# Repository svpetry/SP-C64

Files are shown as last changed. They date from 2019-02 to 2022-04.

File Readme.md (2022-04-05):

This was my first attempt to recreate the Commodore 64. I was able to get it more or less working, but the design still contains timing issues. Currently I am working on a C64 ATX board.

Please note that this design is still buggy. If you are interested in my work then you should wait until I release my C64 ATX project.

## Original text:

This is a rebuild of the Commodore 64 using the original schematics.

Features/changes:
* Replaced DRAM with 2 x 32K SRAM
* Modulator with S-Video and Composite output
* PLA replaced with EEPROM
* PS/2 keyboard connector
* VIC and SID voltage selectable by jumper
* replaced all C64 ROM chips with one EEPROM
* 4 kernal images selectable by switches
* clock generation by ICS 525 clock chip

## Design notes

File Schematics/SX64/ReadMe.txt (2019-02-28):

Commodore SX 64 Portable Computer Schematics
--------------------------------------------

This archive contains a scanned version of the complete Commodore SX 64
Portable Computer Schematics. The book is marked as CBM Part No. 314001-05.

The PDF is in Letter format with all the double sized diagram pages in Ledger
format, just as the original. The width on the Front and Back covers is
slightly oversized, also just as the original.
The original was in near perfect condition, but due to the poor quality
of the original print, some of the scanned pages look somewhat poor. Blame
CBM, not me ;-)

I hope this document can be of some use to you.

2007-04-10, Devia/Ancients

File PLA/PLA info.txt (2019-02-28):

Eprom PIN		C64 signal

1		A15	/GAME
2		A12	A13
3		A7	A14
4		A6	A15
5		A5	/VA14
6		A4	/CHAREN
7		A3	/HIRAM
8		A2	/LORAM
9		A1	/CAS
10		A0	MA4 (A4/A12 VIC)
11		O0	/ROML
12		O1	I/O
13		O2	GR/W
14		GND	GND
15		O3	/CHAROM
16		O4	/KERNAL
17		O5	/BASIC
18		O6	/CASRAM
19		O7	/ROMH
20		/CE	GND
21		A10	MA5 (A5/A13 VIC)
22		/OE	GND
23		A11	/EXROM
24		A9	R/W
25		A8	/AEC
26		A13	BA
27		A14	A12
28		VCC	VCC

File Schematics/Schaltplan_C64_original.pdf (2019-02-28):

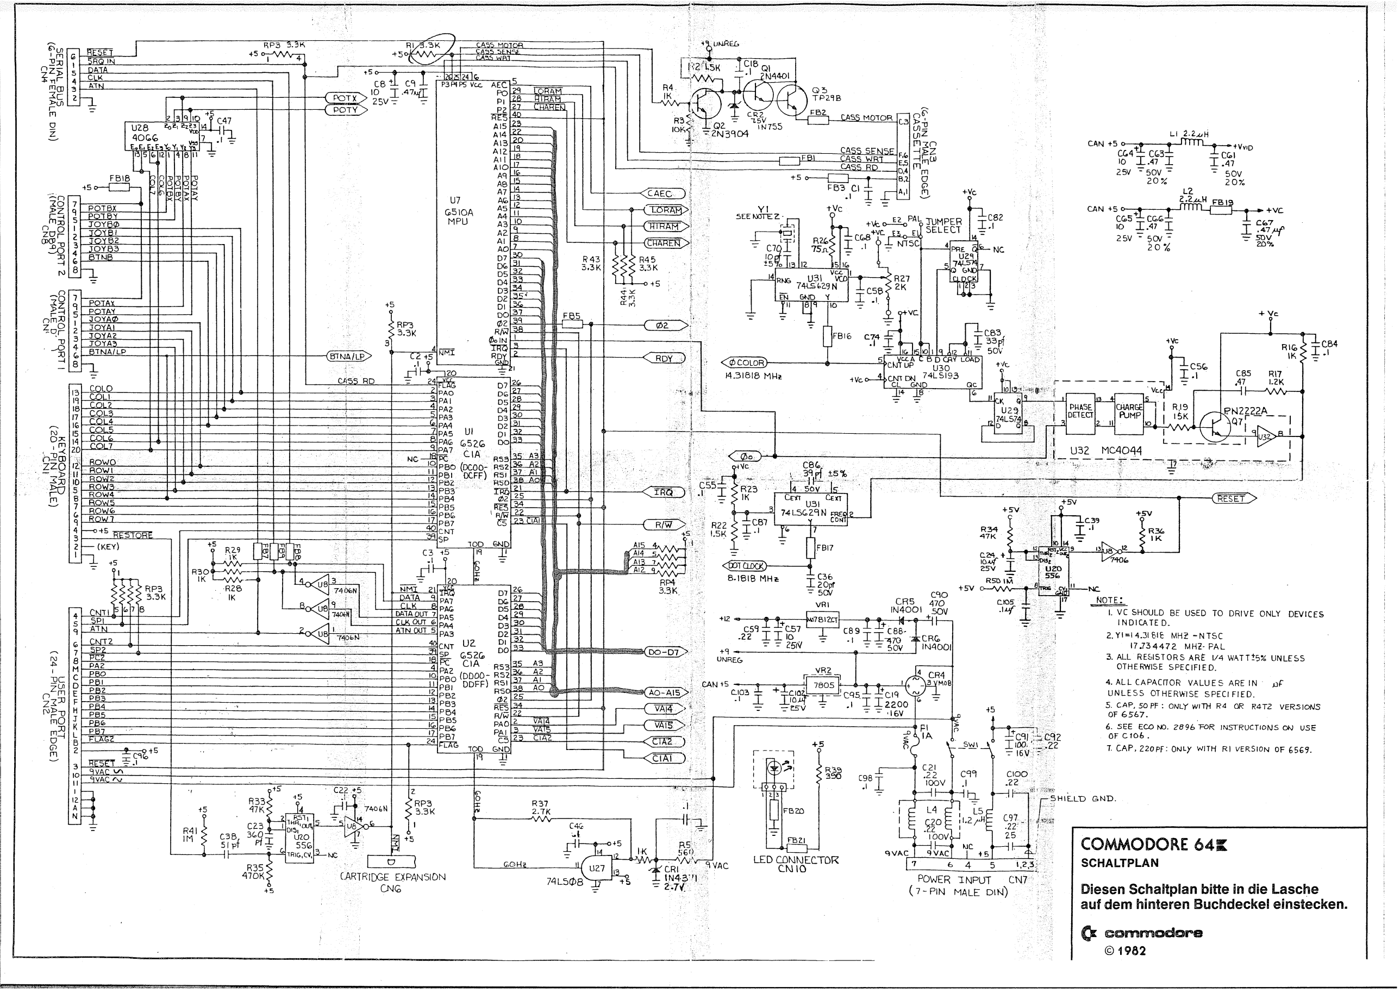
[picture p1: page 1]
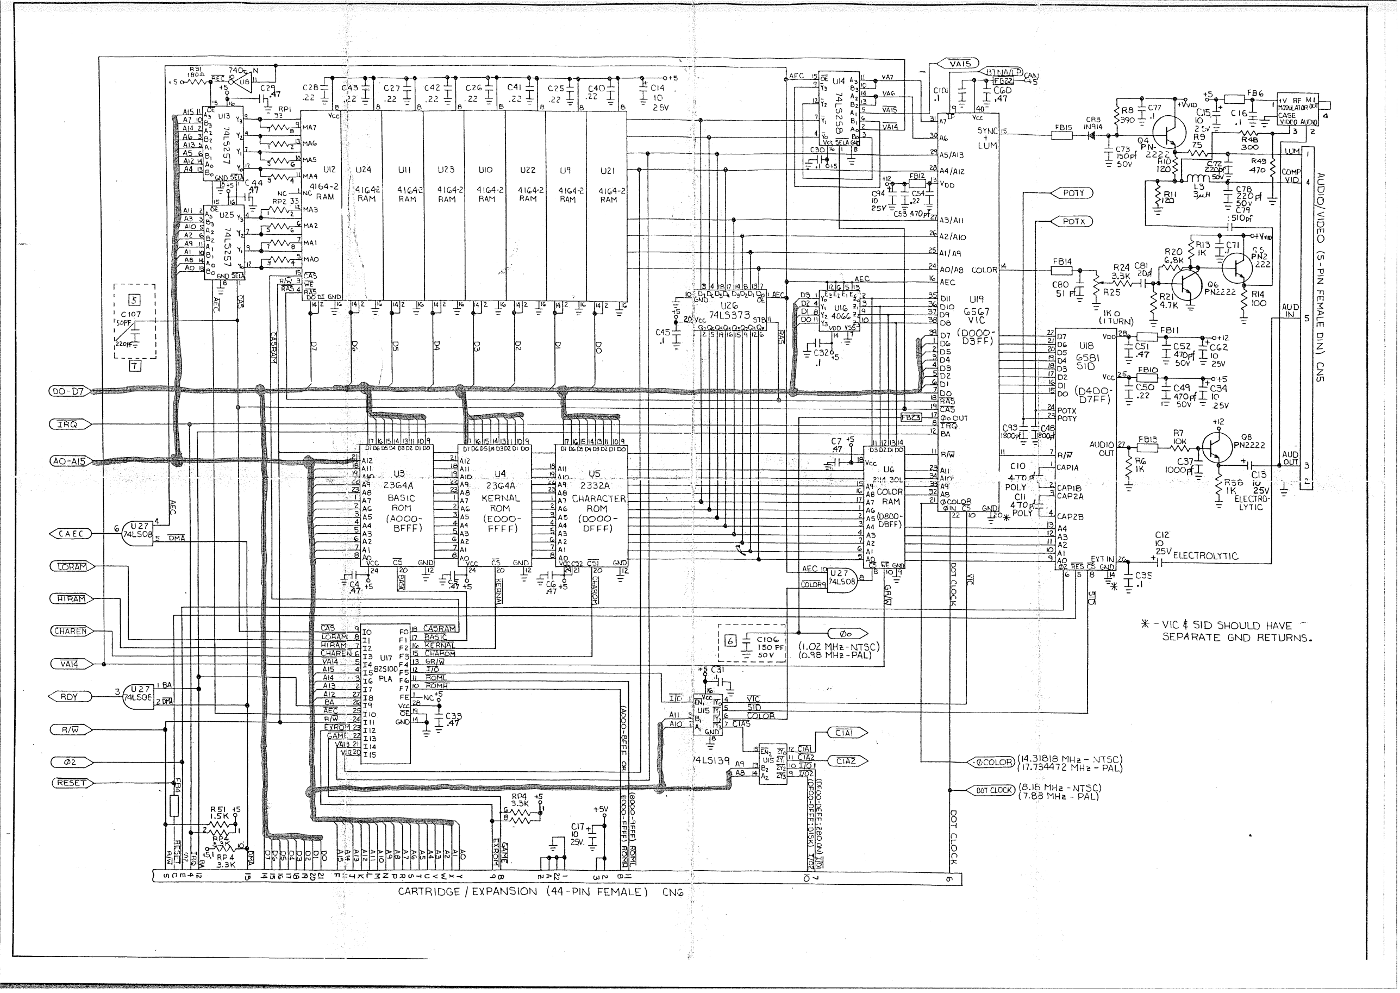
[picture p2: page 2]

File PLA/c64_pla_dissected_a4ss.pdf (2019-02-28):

The C64 PLA Dissected

Thomas ’skoe’ Giesel

Revision 1.1, December 24, 2012

# Contents

Contents | 2
1 Introduction | 3
2 The Logic in the PLA | 6
3 Hardware | 16
4 The Inner Workings of a CSG PLA | 25
5 A PLA Replacement: realPLA | 52
6 Conclusion | 55
A C64 Memory Configurations Explained | 57
Bibliography | 65

2

# Chapter 1

# Introduction

### 1.1 Overview

The programmable logic array (PLA) in the Commodore 64 (C64) is used to create chip select signals from various other signals, e.g., from the current address. These signals control which chip is to be connected to the data bus. Therefore the PLA is responsible to implement the memory map of the C64.

If the PLA is broken, the CPU and the VIC-II¹ direct memory access (DMA) can not access the right memory and I/O devices anymore. In this case some chips can not be selected or more than one chip is active at the same time. A total or partial malfunction of the computer is the result. If a PLA is replaced with a part which does not meet certain timing or electrical constraints of the chips connected to it, the computer becomes unstable, possibly depending on temperature or hardware extensions used or may refuse to work at all.

The logic implemented in the PLA defines the memory map. The logic equations are described in chapter 2, among a short overview of previous reverse engineering work related to it. Also the meaning of all signals connected to the PLA for the working of the C64 is explained there. Appendix A contains the actual memory maps in a readable form as a reference.

A list of PLAs found in C64s and measurements on some of them are shown in chapter 3. This chapter also describes which parameters are important when a PLA is replaced with a different part. Most C64s shipped with a PLA made by Commodore Semiconductor Group (CSG), better known under their original name MOS Technology (MOS). A PLA of this type was opened, photographed through a microscope and completely reverse engineered for this article, down to the transistor level. Chapter 4 contains information about the inner workings of the PLA, a redrawn chip layout and schematics. That chapter also contains some background information by former Commodore/MOS engineers.

An actual implementation of a PLA replacement called realPLA is introduced in chapter 5 which can be built with parts being in production at the time of writing. This implementation aims at highest compatibility possible while using low-cost parts only. The design files for the realPLA are available under a Creative Commons license.

Finally, chapter 6 gives a conclusion about the findings in this document. It also evaluates the compatibility of different PLA replacements.

1Video Interface Controller II

3

### 1.2 About this Document

Why is it necessary to write a document about the PLA in 2012? Information already documented is spread over many articles, buried in old dusty books, various forums and mailing lists, sometimes mixed with wrong statements. Even though the PLA contains combinatorial logic only, it plays an essential role in the C64 and other Commodore computers. “The PLA’s [...] were our last salvation to pull a problem out of the fire, and our chance to impart any coolness in logic,” recalls Bil Herd, a former Commodore engineer.

Understanding the logical function of the PLA is important for programmers, for hardware designers and for emulator developers. However, it is also important to have a closer look at the electrical properties of the original PLAs to implement a drop-in replacement for PLA chips. This document addresses both topics.

This document collects information already documented and adds new measurement and research results. The text and all figures are licenced under Creative Commons Attribution-ShareAlike 3.0 Unported (CC BY-SA 3.0).

### 1.3 Acknowledgements

I wish to thank the engineers of Commodore for the interesting memory maps achieved by using the PLA. Unfortunately you forgot a KERNAL cartridge ;)

Furthermore I would like to express respect to all persons who examined the PLA before and published their results, namely William Levak, Jens Sch¨onfeld, Marko M¨akel¨a, Andreas Boose and Mark Smith.

All PLA logic incorporated in this document and used for the implementation is based on the JEDEC file by Raymond Jett of arcadecomponents.com. It was created by reading a C64 PLA with a TopMAX programmer and Max Loader software. The file is available at [AC12] and in the source code repository of the realPLA implementation [realPLA12].

Segher Boessenkool described in a mail to the cbm-hackers mailing list [Boess12] how the JEDEC file can be read directly. Thanks to his explanation I was able to implemented a small tool which converted the JEDEC file to VHDL equations directly. Segher also helped me much with the first steps to learn to read NMOS die shots and also reviewed this document.

The micrographs for this document were made by Dr. Martin ‘enthusi’ Wendt (8700R1) and Philipp ‘Dexter’ Maier (7700R2). AREA51HD donated the chips we used for that.

Gerrit Heitsch, TheRyk and Bj¨orn ‘JMP$FCE2’ Wieck sent some different PLAs for the investigations. Gerrit also gave some valuable hints for various topics and Bj¨orn made some additional measurements. Ingo Korb helped with proofreading.

Last but not least I also want to thank the former Commodore engineers Bil Herd, Bret Raymis, Dan Morris, Dave DiOrio, Dave Esposito and James Redfield for interesting background information and for clarifying some technical issues.

All quotes in this document which do not state a reference are taken from personal com-munications with the persons concerned.

4

Revision | Changes
1.0 | Initial release
1.1 | Minor changes after review comments; link to Jens Sch¨onfeld’s PLA tool
| added; SuperPLA V3 mentioned

Table 1.1: Document Revisions

### 1.4 Document Revisions

Please look out for new revisions of this document. If you have new or additional information relevant for this document or found mistakes, please contact me. The latest version of this document is available at http://skoe.de/docs/c64-dissected/pla/. Feel free to mirror these files.

5

# Chapter 2

# The Logic in the PLA

### 2.1 The Development

The logic needed to get the C64 running was programmed by Bob Yannes. “He just needed some glue logic to tie everything together,” recalls James Redfield. According to Bil Herd, “[The original PLA terms] appear on an 82S100 worksheet photocopied out of the Signetics databook.”

### 2.2 Reverse Engineering History

The memory maps in the Programmer’s Reference Guide [PRG83] show all possible configurations as they are seen by the CPU, including Ultimax mode. However, some details cannot be taken from that book, especially memory configurations for VIC-II accesses.

Probably the earliest full reverse engineering of the logic programmed to the PLA was written by William Levak in 1986. It was published in The Transactor magazine [Lev86]. He read out a PLA, put the binary dump onto a disk and used a computer program to extract the logic table from it. Using this way he avoided transcription errors. He double-checked the results against two other PLAs. Unfortunately the article in The Transactor has some typesetting mistakes in the memory maps, although the logic table is correct and nicely optimized.

Some years later, in 1994, Jens Sch¨onfeld - apparently not aware of William’s work -captured the truth table again. He, Marko M¨akel¨a, Andreas Boose and others [PLA95] investigated that table and derived equations from it. Mark Smith took a programmer and read out an 82S100 in 1995. The results confirmed their work.

### 2.3 PLA Logic Revisions

Very early C64s contain a PLA which was labeled REV2 7E17. This version is said to have a different logic implemented. Unfortunately no binary or JEDEC dump was available for this document. The next version was REV3 8411. The four digit hex number is the checksum of the original JEDEC file most likely.

Different PLAs with different part numbers by different manufacturers found in C64s have been read out. The logic in all of them was identical with REV3, so this was the final revision.

6

### 2.4 How the PLA is Connected in the C64

To understand the logic in the PLA, first let’s have a look how it is connected in the C64. All descriptions are based on the schematic #251138 from [Serv85], but apply for other C64 models too.

#CAS (I0)

The input line I0 is connected to the #CAS output of the VIC-II. In every Phi1 and Phi2 cycle this line is pulled down by the VIC-II to initiate a read or write access to DRAM. Depending on the other inputs, the PLA may propagate the #CAS pulse to the #CASRAM output or mask it out. Only if it is propagated to #CASRAM, DRAM is actually addressed by the memory access. When #CASRAM remains high in a cycle because it is disabled by the PLA logic, the DRAM access is rendered ineffective, or more precisely it turns to a RAS-only refresh cycle.

#LORAM, #HIRAM, #CHAREN (I1 to I3)

The lines #LORAM (I1), #HIRAM (I2) and #CHAREN (I3) are connected to the pro-cessor port of the CPU, better known as bits 0..2 of $00/$01 in the 6510/8500. After a reset these lines are all set to input mode by the CPU, which means that they are not driven. To make sure the have a sane value when the machine is started, they are pulled up by R43, R44 and R45. With all these values being 1, the C64 can start with KERNAL, I/O and BASIC banked in.

#VA14 (I4)

#VA14 (I4) is one of the additional video address lines for the VIC-II. The VIC-II has a 14 bit wide address bus to address 16 KiByte of memory, while the C64 has 64 KiByte of DRAM. To allow the VIC-II to address any of the four 16 KiByte chunks available in these 64 KiByte, two additional address lines called #VA14 and #VA15 are generated by programmable outputs of the CIA U2. They are fed to an extra address multiplexer U14. This is a 74LS258, which has inverted outputs.

The I/O ports are in input mode after the CIA has been reset. In this case these two lines are pulled high by internal pull-up devices in the CIA, which effectively selects bank 0 on startup. Note that these two video address bits do not appear on the global C64 address bus, they are only used for DRAM accesses. #VA14 is also connected to the PLA to influence the character set ROM mapping.

A15 to A12 (I5 to I8)

The address bus lines A15 to A12 (I5 to I8) are connected to the global address bus. They are driven by the CPU when AEC from the VIC-II and #DMA from the Expansion Port are both high. During VIC-II cycles, when AEC is low, they are pulled up by RP4. When they are pulled up by this resistor array only, it is possible to change them from the Expansion Port. These address lines are used by the PLA to control the memory mapping when AEC is high, i.e. during CPU cycles. However, they are also evaluated in the PLA in Ultimax mode when AEC is low, which makes an interesting trick possible, shown in section A.

7

BA (I9)

BA (I9) is set low by the VIC-II when it wants to halt the CPU to be able to use both half-cycles to get more memory bandwidth. When the VIC-II pulls down BA to take over the bus, there are three cycles left for the CPU. In these cycles up to three write accesses can take place, which is the maximum number of consecutive write accesses a 6510 does. However, the CPU stops its work before the first read access is started. Therefore there are up to three dummy read accesses on the bus until the VIC-II takes over control.

#AEC (I10)

#AEC (I10) is an inverted version of AEC. #AEC is high whenever the VIC-II is going to control the address bus. This is the case in every Phi1 cycle and in all full cycles when is BA low, after the CPU got three extra Phi2 cycles.

R/#W (I11)

The signal R/#W (I11) is high for read accesses and low for write accesses. Note that it is pulled up with resistor R51, because this line is not driven by the CPU when AEC or #DMA are low.

#EXROM, #GAME (I12, I13)

The two lines #EXROM and #GAME can be pulled down by cartridges to change the memory map of the C64, e.g., to map external ROM into the address space. When they are not pulled down from the cartridge port, resistors in RP4 pull them up.

VA13, VA12 (I14, I15)

The two address lines VA13 and VA12 are directly connected to the VIC-II. These lines are needed to address the 16k address space of the VIC-II. Note that #VA14 is from a completely different source, it is connected to a CIA output.

#CASRAM (F0)

The #CASRAM output is connected to the #CAS input of the DRAM chips. It is a gated version of the #CAS signal from the VIC-II. The VIC-II activates the #CAS signal in every half-cycle. Whenever a memory access has to address a different chip or port than the internal DRAM, the PLA disables the #CASRAM output, i.e. it remains high. This is also the case in the Ultimax memory configuration, where some address ranges simply have no memory selected at all.

The #CASRAM line requires the PLA to fullfill certain timing requirements, details can be found in section 3.3.

#BASIC, #KERNAL, #CHARROM (F1..F3)

The outputs #BASIC, #KERNAL, #CHARROM are connected to the chip select inputs of BASIC, KERNAL and character set ROMs. To address one of these chips, the appropriate line is pulled down.

### 2.5 How to Extract the Logic from a 82S100

The 82S100 PLA used in some early C64s can be read out to a JEDEC file with a programmer. This file contains a direct image of the fuse map programmed in the PLA.

8

This fuse map can be translated to product terms, which are AND combinations of inputs and inverted inputs. These product terms may be used in any of the eight sum terms, which are OR combinations. Finally, the fuse map describes which output shall be inverted. The meaning of the bits in the JEDEC file has been explained, e.g., in a mail by Segher Boessenkool [Boess12].

For this document a Python tool has been implemented, which converts the JEDEC file to a more readable logic table and to VHDL source code. The result is also used in the PLA replacement described in section 5.

### 2.6 Full Logic Table

The following table shows the AND and OR relations in the PLA in a very compact form. The symbol ‘*’ means AND, ‘/’ means AND NOT and ‘+’ means OR. Human readable equations are listed in subsequent sections, the resulting memory maps can be found in appendix A.

p 00000000001111111111222222222233 01234567890123456789012345678901 Inputs
#CAS | ........* | /*/

#LORAM | *...*......**..**..* |

#HIRAM | ****.*...**..**....*.* |

#CHAREN ...///...******** |

#VA14 | ......** |

A15 | ******..***************.///**..*
A14 | /*****..***********///*.//*/*..*
A13 | ***///../////////////**..*.*/../
A12 | ...***..***********.....*.../..*
BA | .........*.*.*.*.* |
#AEC | //////**///////////////*......./

R/#W | ******../*/*/*/*/*/*.*........./
#EXROM | ../.././.....////**/*/*******...

#GAME | **/**/*/.****//////./////////...

VA13 | ......// | *........
VA12 | ......** | *........
Outputs
++++++++.++++++++++++++++++++.+. | #CASRAM
+ | NOT #BASIC
.++ | NOT #KERNAL
...+++++ | NOT #CHARROM
| + NOT #GRW
.........++++++++++ | NOT #IO
| ++ | NOT #ROML
| +++........ NOT #ROMH

### 2.7 Original PLA Equations

This chapter shows all equations as extracted directly from a 82S100 and explains their meaning.

9

Note that the value of VADDR refers to a VIC-II address as mapped to the 64k memory space: Address bits 15 and 14 are the inverted values of #VA15 and #VA14, generated by the CIA U2, the remaining bits are generated by the VIC-II itself.

Product Terms

These product terms are AND combinations of the input signals and inverted input signals. They can be used in sum terms to determine the final output signals.

Product Term for #BASIC

If p0 is true, BASIC ROM is selected.

-- # LORAM = 1 , # HIRAM = 1 ,
-- address $A000 .. $BFFF ,
-- no VIC access , read , cartridge : none or 8k p0 <= n_loram and n_hiram and
a15 and not a14 and a13 and
not n_aec and rd and n_game ;

Product Terms for #KERNAL

If p1 or p2 are true, KERNAL ROM is selected.

-- # HIRAM = 1 ,
-- address $E000 .. $FFFF
-- no VIC access , read , cartridge : none or 8k p1 <= n_hiram and
a15 and a14 and a13 and
not n_aec and rd and n_game ;

-- # HIRAM = 1 ,
-- address $E000 .. $FFFF
-- no VIC access , read , cartridge : 16k
p2 <= n_hiram and
a15 and a14 and a13 and not n_aec and rd and not n_exrom and not n_game ;

Product Terms for #CHARROM

If one or more of p3 to p7 are true, CHARACTER SET ROM is selected.

-- # HIRAM = 1 , # CHAREN = 0 ,
-- address $D000 .. $DFFF
-- no VIC access , read , cartridge : none or 8k p3 <= n_hiram and not n_charen and
a15 and a14 and not a13 and a12 and not n_aec and rd and n_game ;

-- # LORAM = 1 , # CHAREN = 0 ,
-- address $D000 .. $DFFF ,
-- no VIC access , read , cartridge : none or 8k p4 <= n_loram and not n_charen and
a15 and a14 and not a13 and a12 and not n_aec and rd and n_game ;

-- # HIRAM = 1 , # CHAREN = 0 ,

10

-- address $D000 .. $DFFF ,
-- no VIC access , read , cartridge : 16k
p5 <= n_hiram and not n_charen and
a15 and a14 and not a13 and a12 and
not n_aec and rd and not n_exrom and not n_game ;

-- VADDR $1000 .. $1FFF or $9000 .. $9FFF
-- VIC -II access , cartridge : none or 8k
p6 <= n_va14 and not va13 and va12 and n_aec and n_game ;

-- VADDR $1000 .. $1FFF or $9000 .. $9FFF
-- VIC -II access , cartridge : 16k
p7 <= n_va14 and not va13 and va12 and n_aec and not n_exrom and not n_game ;

Unused Product Term p8

The term p8 is not used at all. It may be a remainder of an earlier design stage of the C64 prototypes. Note that this is the same as p31 with CAS inverted.

p8 <= n_cas and
a15 and a14 and not a13 and a12 and not n_aec and not rd ;

Product Terms for #IO

If one or more of p9 to p18 are true, an I/O chip or port is selected.

-- # HIRAM = 1 , # CHAREN = 1 ,
-- address $D000 .. $DFFF ,
-- no VIC access bus available , read ,
-- cartridge : none or 8k
p9 <= n_hiram and n_charen and
a15 and a14 and not a13 and a12 and not n_aec and ba and rd and n_game ;

-- # HIRAM = 1 , # CHAREN = 1 ,
-- address $D000 .. $DFFF ,
-- no VIC access , write , cartridge : none or 8k p10 <= n_hiram and n_charen and
a15 and a14 and not a13 and a12 and not n_aec and not rd and n_game ;

-- # LORAM = 1 , # CHAREN = 1 ,
-- address $D000 .. $DFFF ,
-- no VIC access , bus available , read ,
-- cartridge : none or 8k
p11 <= n_loram and n_charen and
a15 and a14 and not a13 and a12 and not n_aec and ba and rd and n_game ;

-- # LORAM = 1 , # CHAREN = 1 ,
-- address $D000 .. $DFFF ,
-- no VIC access , write , cartridge : none or 8k p12 <= n_loram and n_charen and
a15 and a14 and not a13 and a12 and

11 not n_aec and not rd and n_game ;

-- # HIRAM = 1 , # CHAREN = 1 ,
-- address $D000 .. $DFFF ,
-- no VIC access , bus available , read , cartridge : 16k p13 <= n_hiram and n_charen and
a15 and a14 and not a13 and a12 and
not n_aec and ba and rd and
not n_exrom and not n_game ;

-- # HIRAM = 1 , # CHAREN = 1 ,
-- address $D000 .. $DFFF ,
-- no VIC access , write , cartridge : 16k p14 <= n_hiram and n_charen and
a15 and a14 and not a13 and a12 and not n_aec and not rd and
not n_exrom and not n_game ;

-- # LORAM = 1 , # CHAREN = 1 ,
-- address $D000 .. $DFFF ,
-- no VIC access , bus available , read , cartridge : 16k p15 <= n_loram and n_charen and
a15 and a14 and not a13 and a12 and
not n_aec and ba and rd and
not n_exrom and not n_game ;

-- # LORAM = 1 , # CHAREN = 1 ,
-- address $D000 .. $DFFF ,
-- no VIC access , write , cartridge : 16k p16 <= n_loram and n_charen and
a15 and a14 and not a13 and a12 and not n_aec and not rd and
not n_exrom and not n_game ;

-- address $D000 .. $DFFF
-- no VIC access , bus available , read , cartridge : Ultimax p17 <= a15 and a14 and not a13 and a12 and
not n_aec and ba and rd and
n_exrom and not n_game ;

-- address $D000 .. $DFFF ,
-- no VIC access , write , cartridge : Ultimax
p18 <= a15 and a14 and not a13 and a12 and
not n_aec and not rd and n_exrom and not n_game ;

Product Terms for #ROML

If p19 or p20 are true, the cartridge line ROML is selected.

-- # LORAM = 1 , # HIRAM = 1 ,
-- address $8000 .. $9FFF
-- no VIC access , read , cartridge : 8k or 16k p19 <= n_loram and n_hiram and
a15 and not a14 and not a13 and
not n_aec and rd and not n_exrom ;

-- address $8000 .. $9FFF

12

-- no VIC access cartridge : Ultimax
p20 <= a15 and not a14 and not a13 and
not n_aec and n_exrom and not n_game ;

Product Terms for #ROMH

If one or more of p21 to p23 are true, the cartridge line ROMH is selected.

-- # HIRAM = 1 ,
-- address $A000 .. $BFFF ,
-- no VIC access , read , cartridge : 16k
p21 <= n_hiram and
a15 and not a14 and a13 and
not n_aec and rd and not n_exrom and not n_game ;

-- address $E000 .. $FFFF ,
-- no VIC access cartridge : Ultimax
p22 <= a15 and a14 and a13 and
not n_aec and n_exrom and not n_game ;

-- VADDR $3000 .. $3FFF , $7000 .. $7FFF , $B000 .. $BFFF or
-- | $E000 .. $EFFF ,
-- VIC -II access , cartridge : Ultimax
p23 <= va13 and va12 and
| n_aec and n_exrom and not n_game ;

Additional Product Terms for #CASRAM

The DRAM of the C64 must be disabled whenever another device is selected. Therefore all product terms above appear in the #CASRAM term. Exceptions are the unused terms and #GRW, which is not a chip select signal. However, in Ultimax mode most of the DRAM is hidden permanently to emulate the 4 KiByte contained in an original Commodore MAX Machine. To hide the remaining DRAM, the terms p24 to p28 are used.

-- address $1000 .. $1FFF , $3000 .. $3FFF ,
-- cartridge : Ultimax
p24 <= not a15 and not a14 and a12 and
| n_exrom and not n_game ;

-- address $2000 .. $3FFF ,
-- cartridge : Ultimax
p25 <= not a15 and not a14 and a13 and
| n_exrom and not n_game ;

-- address $4000 .. $7FFF ,
-- cartridge : Ultimax
p26 <= not a15 and a14 and
| n_exrom and not n_game ;

-- address $A000 .. $BFFF ,
-- cartridge : Ultimax
p27 <= a15 and not a14 and a13 and
| n_exrom and not n_game ;

-- address $C000 .. $CFFF ,
-- cartridge : Ultimax

13 p28 <= a15 and a14 and not a13 and not a12 and n_exrom and not n_game ;

Unused Product Term p29

Term p29 is unused. Note that this is the same as p30 with CAS inverted.

p29 <= not n_cas ;

Product Term to Forward #CAS to #CASRAM

p30 is used to put #CASRAM always high when #CAS is high. This completes the gate mechanism for #CAS.

p30 <= n_cas ;

Product Term for #GRW

The C64 makes use of static RAM for the color memory. Typical SRAM parts like the HM472114 ([Hita2114]) need their address lines to be set up for a certain time before they get their chip select and write enable signals. Because of the bus multiplex mechanism controled by #AEC this is not the case in the C64.

When the color SRAM may be written, a special #GRW is generated for it. The term makes use of #CAS, because this input is only active when the address bus has a stable state. Note that also the I/O decoding has to match to enable an actual write access to the color RAM.

-- # CAS low ,
-- address $D000 .. $DFFF ,
-- no VIC access , write
p31 <= not n_cas
and a15 and a14 and not a13 and a12 and not n_aec and not rd ;

Sum Terms

-- No RAM whenever BASIC , KERNAL , CHARROM , IO , -- ROML or ROMH are accessed or
-- any area with RAM disabled in Ultimax mode or -- when there is no CAS signal from the VIC -II n_casram <= p0 or p1 or p2 or
p3 or p4 or p5 or p6 or p7 or
p9 or p10 or p11 or p12 or p13 or
p14 or p15 or p16 or p17 or p18 or
p19 or p20 or p21 or p22 or p23 or
p24 or p25 or p26 or p27 or p28 or p30 ;

-- Low for BASIC ROM read
n_basic <= not p0 ;

-- Low for KERNAL ROM read n_kernal <= not ( p1 or p2 );

-- Low for CHARACTER SET ROM read
n_charrom <= not ( p3 or p4 or p5 or p6 or p7 );

14

-- Clean write pulse for color RAM
n_grw <= not p31 ;

-- Low for I/O chips or ports read or write
n_io <= not ( p9 or p10 or p11 or p12 or p13 or p14 or p15 or p16 or p17 or p18 );

-- Low for cartridge ROML read or write
n_roml <= not ( p19 or p20 );

-- Low for cartridge ROMH read or write n_romh <= not ( p21 or p22 or p23 );

15

# Chapter 3

# Hardware

### 3.1 Types of PLAs Found in C64s

Signetics 82S100

The well known PLA type 82S100 by Signetics [Si75] can be found in many early C64s. Signetics was acquired by Philips and the part was renamed to PLS100 later, with a slightly revised specification [PLS100]. The 82S100 has been the first widely used field programmable logic chip. It was launched in 1975 [CHM09].

Fairchild 93459

A clone of the Signetics PLA made by Fairchild was named 93459. The oldest public reference to this IC found so far is a Fairchild catalog from 1977 [Fc77]. This PLA was also used in many early C64s.

MOS 7700/8700

Later Commodore MOS made their own chips labeled with MOS 906114-01. This was a mask programmable NMOS clone of the 82S100. “We reverse engineered the PLA from Signetics using a polaroid camera,” recalls Bil Herd. Dave DiOrio adds, “We may have looked at other circuits but the design was custom.”

To reverse engineer the CSG PLAs for this document several of them were decapped. It turned out that the actual silicon used has been a 7700R2 before around mid of 1984 and an 8700R1 later. There is no clear indication printed on the chip package, but after opening a few (broken) PLAs, it turned out that manufacturing dates in 1983 suggest a 7700 and 1985 and later suggest an 8700. ICs manufactured in 1984 could be either of them.

Beginning in 1986 another version of the 8700R2 has been made: The revision number didn’t change, but the MOS logo was replaced with “[M] 1986 CBM”.

The CSG PLAs were also used in other Commodore computers and periphery. For example a 251641-02 from a C16/C116/Plus4 was decapped. It had an 8700R1 inside, with just a different mask programming.

The C64 schematics also reference different types for the PLA, this is summarized in table 3.1. Schematic #252278 contains a PLA type MB112A101, which to the authors best knowledge has not been found on a C64 board yet.

16

PCB Assy | Schematic | PLA types listed
326298 | #326106 | 82S100
250407 | #251138 | 7700
250425, 250441 | #251469 | 7700, 8700
250446 | #252278 | 8700, MB112A101

Table 3.1: PLAs on various C64 schematics

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
14 | 15
| 16

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
FE/NC | 28
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
VSS | F3 F2

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
## PLA

Figure 3.1: PLA pinout

### 3.2 Package and Pin Assignment

The PLAs used in the C64 are packaged in a 600 mil wide DIP with 28 pins, usually made of plastic. The pinout diagram is shown in figure 3.1. It has two supply pins, VCC (5 V) and VSS ( 0 V). There are 16 inputs to the logic functions and one output enable (#OE) to tristate or enable the outputs. The 8 outputs have push-pull drivers. The special pin FE/NE is used for programming field-programmable parts and not connected internally for mask programmable parts.

### 3.3 Electrical Properties

In this section the results of measurements of some electrical properties of original PLAs and different PLA replacements are shown. Their meaning for the inner workings of the C64 is discussed.

Devices Under Test

The measurements for this document were done with one sample of each of the two most frequently used bipolar PLAs, the Signetics 82S100 and the Fairchild 93459PC. Three samples of the 906114-01 with different date codes were also tested. Finally three PLA replacements were checked, the EPROM STMicroelectronics M27C512-90B6, which is

17

Package | Type | VOH | Technology
Label | | [V]
N82S100N S C64 K8303 | Signetics 82S100 | 4.2 | Bipolar
93459 PC F 8235 | Fairchild 93459PC | 3.9 | Bipolar
906114-01 2683 | MOS 7700R1 | 3.7 | NMOS
906114-01 4885 | MOS 8700R2 | 3.8 | NMOS
906114-01 2488 | MOS 8700R2 | 3.7 | NMOS
M27C512-90B6 | EPROM M27C512-90B6 | 4.9 | CMOS
SuperPLA | SuperPLA V2 | 4.0 | CMOS/NMOSa
realPLA | realPLA | 5.0 | CMOS

Table 3.2: PLA devices under test

said to be the EPROM ideally suited for this usage, the SuperPLA V2¹
from Individual
Computers and the realPLA, which is introduced in this document.

Gerrit Heitsch found another PLA type in a C64 which seems to be manufactured by Fujitsu, according to its package shape and printing. This type has a much lower power consumption than other original PLAs. It was not examined for this document yet, but listed for the sake of completeness.

Table 3.2 lists all devices under test (DUTs). This table contains also the voltage of an output high level VOH. This is a valuable indicator to the semiconductor technology used. However, the technology is listed in the datasheets for most of the parts.

As a rough guideline the bipolar parts have a VOH of about VCC − 1.0 V. The NMOS parts have a VOH of VCC − 1.3 V, where 1.3 V is Vth of an N-channel FET used in the pad buffer totem pole. Details about the actual circuitry used there will be described in section 4. The CMOS parts have a VOH of about VCC. The SuperPLA is a special case, refer to section 3.3 for details.

Power Consumption

One of the most impressive properties of the PLA is: It gets quite hot for the little work it has to do. To get an impression about their static power dissipation, the devices were mounted on a breadboard. #OE was connected to GND. All inputs were pulled high, the outputs did not have a load. The current at VCC was measured with a multimeter.

Additionally the temperature was captured with an infrared thermometer in the middle of the chip package’s surface at an ambient temperature of 24 ◦C. Note that the temperature is a rough estimation only. In some cases the temperature is higher for a part which needs less power compared to another part. The reason may be different physical properties of the chip package² or simply inaccurate temperature measurements.

Table 3.3 shows the results of these measurements.

The 82S100 and the 93459 use bipolar technology, basically TTL or Schottky TTL. They have the highest power consumption.

Also the NMOS implementation has a quite high power dissipation, which is caused by the depletion load NMOS logic which needs relatively strong pull-up devices to get the same switching speed as the bipolar original.

1While this document has been written, a revised Super PLA V3 has been released, it has similar characteristics as V2, it can replace PLAs in multiple Commodore devices
2All of them where plastic packages

18

DUT | Iidle [mA] | T [ ◦C]
82S100 | 102 | 45
93459PC | 98 | 57
7700R1 (2683) | 92 | 52
8700R2 (4885) | 90 | 53
8700R2 (2488) | 86 | 39
M27C512-90B6 | 4 | 26
SuperPLA | 68 | 42
realPLA | 13 | 28

Table 3.3: PLA power consumption and package temperature

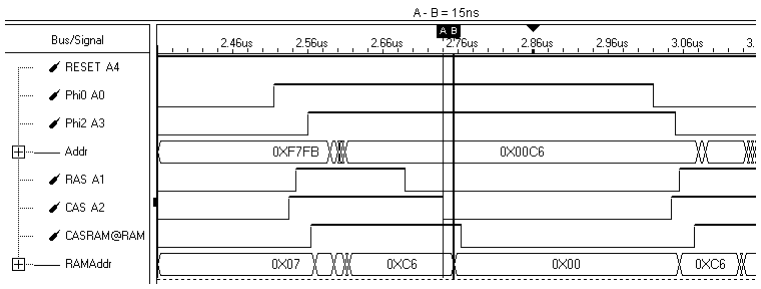
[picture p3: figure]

Figure 3.2: The #CAS race

The pure CMOS variants EPROM and realPLA have the lowest idle power consumption.

The PLD used in the SuperPLA uses CMOS technology according to its datasheet [Mach110]. But the relatively high static power consumption and its VOH of only 4.0 V (refer to table 3.2) shows that it must use some kind of hybrid logic, e.g., pseudo NMOS logic. This is indirectly confirmed by some figures in that datasheet, e.g., the output driver uses an NMOS totem pole instead of a real CMOS totem pole, most likely for higher speed vs. chip area compared with PMOS FETs.

Propagation Delay

The propagation delay of the PLA is very important for the correct work of the C64. For example, the #CASRAM signal must be delayed by the PLA by at least a certain time. On the other hand, the propagation delay must not be too large, otherwise e.g., setup times of the chips which get their select signals too late may be violated.

The #CAS signal from the VIC-II is also used to multiplex the address bus for the DRAM address inputs. This is done with U13 and U25 (74LS257), which have a maximum propagation delay from their select input (#CASRAM) to their outputs of 24 ns [TI257]. Typical DRAM chips used in the C64 have an address setup time of at least 0 ns before #CAS, an example is the HM4864A ([Hita4846]). This means that the #CASRAM signal must be delayed by at least this time, otherwise the DRAMs would latch the wrong column address. This timing dependency could be called a design flaw in the C64. Figure 3.2 shows that the multiplexed address changes about 15 ns after #CAS and becomes stable just about 10 ns before #CASRAM gets active on this board.

19

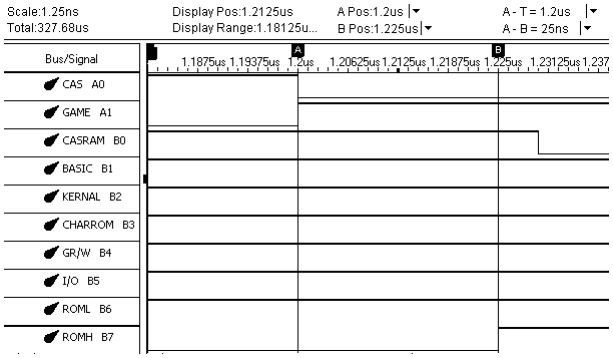
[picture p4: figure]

Figure 3.3: Example propagation delay measurement, DUT is 8700R2 (2488)

The measurements shown here were done with a 200 MHz logic analyzer, so the error is about ±5 ns. The input signals #CAS and #GAME were connected to a binary counter. The output signals were sampled with a threshold voltage of 1.3 V, which is close to the threshold voltage of NMOS inputs. #CASRAM and #ROMH have been chosen as outputs because one of them has an inverted logic compared to the other one. This may cause these two to have different delays. Figure 3.3 shows the output of one of these measurements. Table 3.4 lists the results. There may be sightly different propagation delays for situations where several inputs change simultaneously, this has not been considered for the measurements.

The propagation delays of original PLAs are of the order of 25 ns ± 5 ns. Note that the 7700R1 is about 5 ns to 10 ns slower then the other types. The bipolar PLAs have a slightly slower effective delay for low to high transitions because their rising edges are very slow.

The EPROM M27C512-90B6 is a bit quicker than the original PLAs, but still in the same ballpark.

The SuperPLA has its CASRAM delay tuned to be in the right order, which is important for the DRAM control in the C64. But the delay of the other outputs is much lower than the values seen on original parts. This seems not to play a role usually, but there may be C64 boards and cartridges which may have problems with this difference. Note that the logic in the SuperPLA inhibits that other outputs to become low when #CASRAM is still low, which would lead to overlapping chip selects otherwise, due do the different delays.

The realPLA was designed to have an authentic delay and to have matched delays among all outputs. This measurement confirmed that this aim was reached.

Slew Rate

Some of the signals generated by the PLA are connected to long PCB traces and connected to the Expansion Port, which may be connected using a ribbon cable (as in the SX64) or may have a port expander or large PCB attached to it. Signals with very steep edges

20

#CASRAM | #ROMH

DUT | TpdLH | TpdHL | TpdLH | TpdHL
82S100 | 35 | 25 | 25 | 25
93459PC | 35 | 20 | 35 | 20
7700R1 (2683) | 30 | 35 | 40 | 30
8700R2 (4885) | 30 | 25 | 25 | 30
8700R2 (2488) | 20 | 30 | 25 | 25
M27C512-90B6 | 20 | 20 | 20 | 20
SuperPLA | 25 | 30 | 10 | 10
realPLA | 25 | 30 | 25 | 30

Table 3.4: Propagation delays [ns]

Figure 3.4: 82S100 - rising edge | Figure 3.5: 82S100 - falling edge

could cause undesirable effects because of reflections on the PCB traces or result in strong switching noise.

To get an impression of the slew rate of all PLAs tested, they were connected to a test circuit. One of the inputs of each PLA was connected to a clock signal, one of the outputs was loaded with a capacitor (82 pF, which is a quite heavy load already) and captured with a digital scope. The scope I was using had a sample rate of 100 Msamples/s only, so the slew rates are a rough guess only.

A noticeable result of this measurement series is that bipolar and NMOS/CMOS PLAs have very different slew rates. The falling edge and the rising edge of the NMOS and CMOS PLAs are nearly symmetric, at least in the range between 1 V and 3 V.

However, the voltage of the bipolar PLAs raises very slowly over the whole voltage range but drops quite quickly. The reason is most likely an output stage similar to what is used in LS-TTL.

Overlapping Chip Selects

A potential problem with PLAs and PLA replacements is that they could activate multiple chip select signals at the same time. A reason for that can be slower high to low transition times than low to high or different propagation delays for different signal paths. Temporary bus contentions caused by these effects could lead to higher power dissipation and therefore higher heat generation in the chips involved.

21

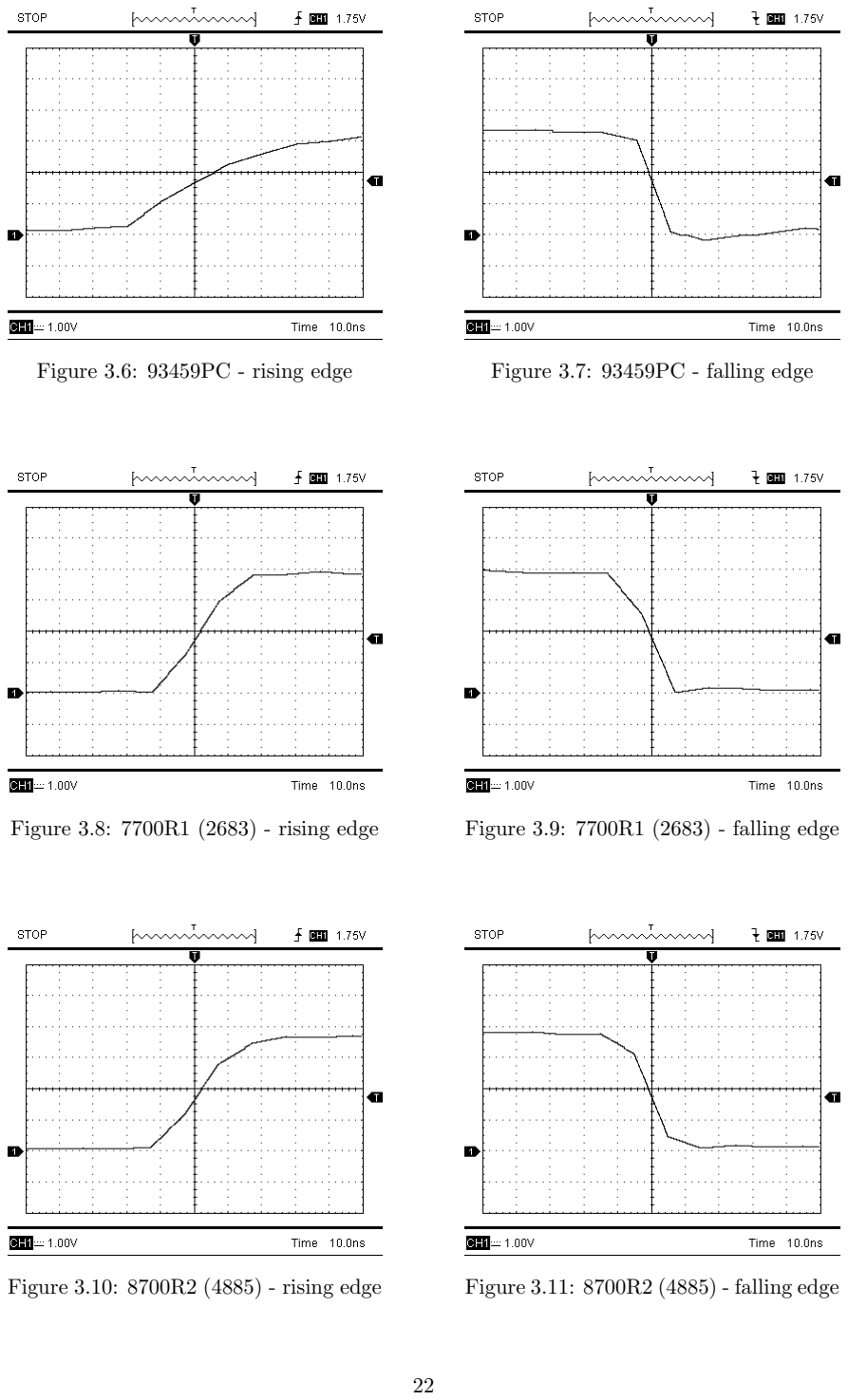
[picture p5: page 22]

Figure 3.6: 93459PC - rising edge | Figure 3.7: 93459PC - falling edge
Figure 3.8: 7700R1 (2683) - rising edge | Figure 3.9: 7700R1 (2683) - falling edge
Figure 3.10: 8700R2 (4885) - rising edge | Figure 3.11: 8700R2 (4885) - falling edge

22

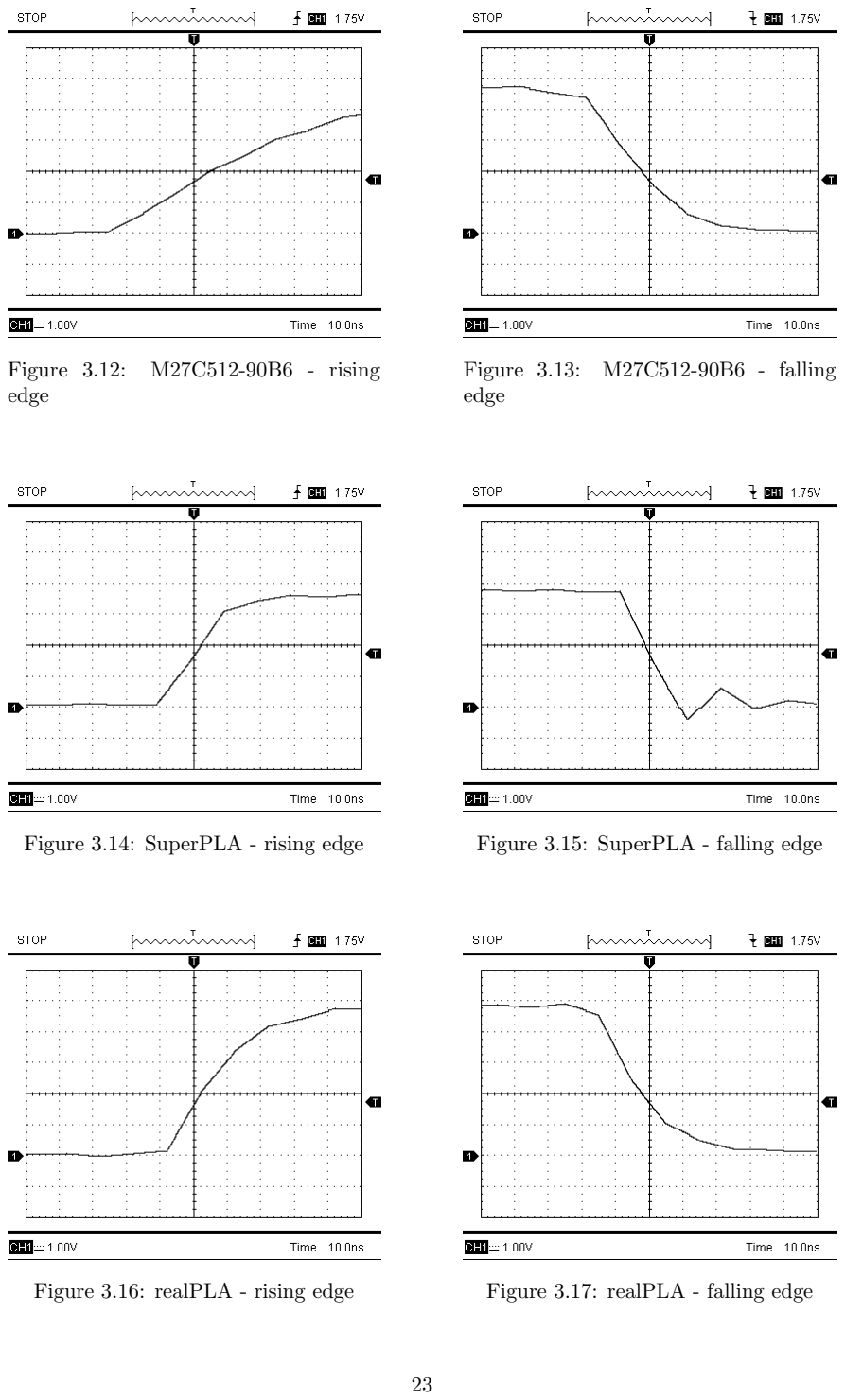
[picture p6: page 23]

Figure 3.12: M27C512-90B6 - rising edge

Figure 3.13: M27C512-90B6 - falling edge

Figure 3.14: SuperPLA - rising edge | Figure 3.15: SuperPLA - falling edge
Figure 3.16: realPLA - rising edge | Figure 3.17: realPLA - falling edge

23

DUT | Overall | PLA | Board w/o PLA
| I [mA] | I [mA] | I [mA]
SuperPLA | 695 | 59 | 636
8700R2 (2488) | 720 | 82 | 638
8700R2 (4885) | 721 | 82 | 639
M27C512-90B6 | 647 | 6 | 641
93459PC | 736 | 86 | 650

Different Board, different PLAs:

realPLA | 782 | 15 | 767
M27C512-90B6 | 775 | 6 | 769
SuperPLA | 837 | 68 | 769
82S100 | 875 | 105 | 770

Table 3.5: Board power consumption depending from PLA

After some investigations regarding this topic at [esl11], Fran¸cois L´eveill´e had the idea to measure the power consumption of a C64 with different PLAs attached. He did not elaborate this interesting experiment very much, so it was repeated for this document.

Two different C64s of revision 250407 were used. The 5V rail was cut at inductor L5 and the current was measured there. The supply current of such a C64 at the 5V line is about 50 mA higher when the computer is at room temperature than when it is warm. So in all cases the C64s have been left running with the BASIC screen shown until the current consumption was stable.

In a second experiment the plain VCC current of the PLA was measured at the same state of the C64. This can be subtracted from the overall current to calculate the power consumption of the rest of the C64.

Table 3.5 shows the result of these measurements, sorted by board supply current at 5V without PLA supply current. Note that the first board had the KERNAL ROM replaced with a CMOS type, which is the reason for its lower overall power consumption.

The results show that the current differs, in addition to the different power consumptions of the PLAs themselves. The 93459PC causes the rest of the C64 to draw about 10 mA more, which confirms the theory by Fran¸cois L´eveill´e.

However, the additional 10 mA compared with the overall 800 mA are a bit more then 1%, distributed over at least two chips. This will not cause a noticeably increased heat generation nor reduced life time.

A closer look at the propagation delays and slew rates shown in section 3.3 reveals that the Fairchild 93459PC has very quick falling edges and very slow rising edges. This may lead to a bus contention with a duration of about 15 ns per transistion, which explains the slightly higher current.

24

# Chapter 4

# The Inner Workings of a CSG PLA

To investigate the actual implementation of the PLA in the part which was used most often in C64s, the MOS 7700R2/8700R1, they have been decapped and photographed under a microscope for this document.

To get rid off the package, the PLAs have been cooked in rosin two times for several hours. The abietic acid contained in rosin dissolved the plastic package. Finally the dies have been cleaned in isopropyl alcohol. Figure 4.1 et seq. show this procedure.

With these die shots the masks of the 8700R1 have been redrawn. The resulting chip layout was used to draw the schematics of the PLA.

### 4.1 The Original Designers

Even though the overall design of the PLA is not very complex, it may have been chal-lenging to build the NMOS part with the same speed as the original bipolar part. It needs only approximately 25 ns for the whole row of gates comprising an input super buffer, another super buffer, a NOR array for the product term, another NOR array for the sum term, a super buffer and the pad push-pull buffer. It was designed by Dave DiOrio, he recalls, “It was a rather simple chip select circuitry.”

The PLA was produced over many years, but not all replacements for third party chips by Commodore had such a good fate. “At one time there was a shortage of some of the TTL components used on the platform so they even tried replacing those chips with an NMOS ‘equivalent’ that never really panned out due to speed problems,” recalls James Redfield.

Figure 4.1: The decapping procedure starts

25

Figure 4.2: The package starts to dissolve

Figure 4.3: The die decapped and cleaned

The 7700R2 PLA has the initials “RD” and “JB” written on the metal layer. JB is the mask designer Joan Brenneke. She drew the polygons most likely, her colleague RD¹ digitized the layout into the Calma CAD system finally. Figure 4.4 shows their initials.

### 4.2 NMOS Process Generations

CSG evolved several generations of NMOS manufacturing. Before about 1983, the chips were numbered with a 6xxx scheme. Their manufacturing process was commonly referred to as NMOS and had a critical dimension (CD) of about² 8 µm for the 6502, over the years they seem to have been reduced, The VIC-II (MOS 6567) was implemented with 6 µm channel length³
. The 7xxx chips appeared in about 1983. This process was called HMOS1. Only one year later, the next generation called HMOS2 was in use already, which was numbered 8xxx. The design rules had a CD of 5 µm⁴
. The numbering scheme
was not used consistently in all cases, for example the CIA was still called 6526(A) when it was manufactured using the HMOS2 process.

Dave DiOrio explains, “These dimensions were ‘drawn’ dimensions. Through the fabri-cation process there would be etching and effects that provided a different effective gate length.” This may be the reason that the PLA die shots look like they use a channel width of approximately 4 µm, although the nominal gate length were larger.

1Name still unknown
2Measured on die shots
3According to James Redfield and Bret Raymis, this confirms measurements on die shots 4According to Bret Raymis

26

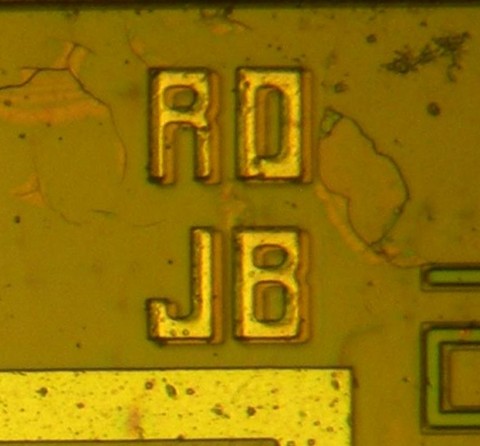
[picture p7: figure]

Figure 4.4: Initials found on the PLA 7700R2

There is no official definition for HMOS1 and HMOS2. Dan Morris recalls “All companies used similar naming conventions. [...] The photo process sets the classical shrink sequence. As photo equipment improves, smaller geometries can be resolved. Scaling through photo shrinkage allowed circuit designs to be reused without the need to redesign them. A 20% linear shrink would run [approximately] 40% faster at 40% lower power. and reduce production cost by 40% as well. So process engineering’s job was to develop a 20% shrink process about every 12 months. The number sequence identified each shrink step (HMOS1 to HMOS2) that process was running. When a process could no longer be shrunk a new process was developed and used the new design rules as its starting point. (NMOS to HMOS)”

Figure 4.5 shows the size of the two CSG PLAs. There is a noticeable 10% linear process shrink between these two revisions. Unfortunately the surface of the 7700R2 got damaged when it was decapped. Figure 4.6 shows (more or less) that the channel length was changed by the same factor, which confirms a photo shrink with changes in the metal layer for the labels only. When putting a die shot of the 7700R2 on top of a scaled die shot of the 8800R1, it can be seen that the match very well.

With the term NMOS this document refers to NMOS logic in general, no matter which process or structure size was used to manufacture it.

### 4.3 Reliability Failures

People who repair Commodore computers notice that the early PLAs fail quite often. Bil Herd recalls “By far the worst chip failure mode we had was the PLA around 1982-83 as it was suffering from poor passivation. It would get the ‘purple creeping crud’ which was corrosion under the protective layer.”

Dan Morris knows the reason for this issue: “The inter-layer glass (Low Temp Oxide or LTO) is doped with Boron and Phosphorus atoms. Boron and phosphorus are added to soften the glass and cause it to flow at lower temperatures. The flow smooths the surface of the circuit dramatically improving step coverage for the aluminum interconnections. Boron concentrations above 4% really accelerates the glass flow. Unfortunately raising the Boron concentration above 4% also sets up a strong but relatively slow corrosion reaction with aluminum. This is a reliability time bomb. As soon as the field failures demonstrated

27

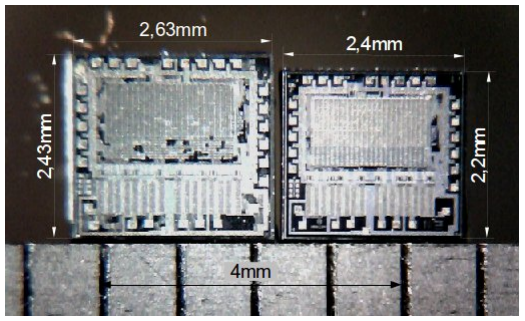
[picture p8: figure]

Figure 4.5: Sizes of MOS 7700R2 and MOS 8700R1 compared

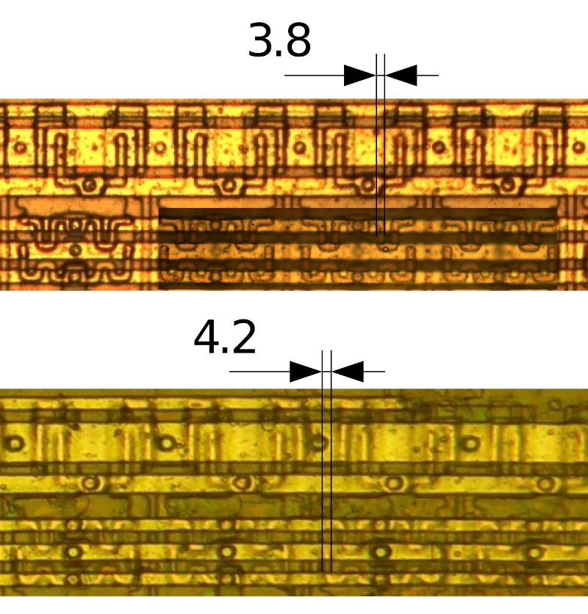
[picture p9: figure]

Figure 4.6: Approximate channel length of 7700R1 and 8700R1

28 a problem. The process was changed to reduce the Boron to less than 3%. Unfortunately, many, many computers shipped with this problem first.”

Dan Morris managed the manufacturing test and product engineering for the California semicondutor facilitya
from September 1981 to 1985. His first task was to set up a silicon gate CMOS fab, this fab made metal gate CMOS up to then. “About three months into our production ramp up we got the word on a Friday night that we needed to stop all work and immediately convert the fab to run the NMOS process from Valley Forge. [...] The CMOS process we developed never went to production.”
“Our orders were ‘copy exactly’, no deviations allowed. That was a tall order, given different equipment and different process skills. We worked without sleep for 5 days. We took each process step and duplicated it on each piece of equipment and started the first fab lot on the 6th day. We ramped the fab to full production 4 weeks later after the first lot proved successful with yields better than the Valley Forge fab.” The California facility produced the majority of the integrated circuits for the VIC 20 and Commodore 64 computers.
Dan Morris also developed low cost test systems for wafer and final test of the audio and video chips.

aFrontier Semiconductors, acquired by Commodore

The PLA seems to be more prone to failures than e.g., the 6510 or 8500 CPU. This may be caused by the fact that it was among the first chips made with the HMOS1 process. Another factor could be that it has a quite high power dissipation on a small die area compared to other chips. Its high temperature may speed up its aging, e.g., because of mechanical stress and by speeding up processes like electromigration [Hoffmann06]. Also the 7360 TED and the 7501 CPU are reported to fail quite often.

### 4.4 Block Diagram

Figure 4.7 shows the function blocks of the CSG PLA and their approximate position on the die. These function blocks will be described in the subsequent sections.

29

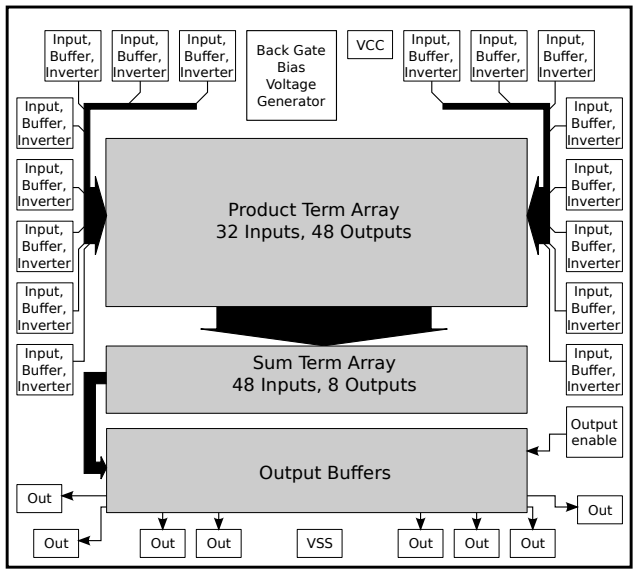
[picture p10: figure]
Product Term Array 32 Inputs, 48 Outputs; Sum Term Array 48 Inputs, 8 Outputs; Back Gate Bias Voltage Generator; Input, Buffer,; Inverter; VCC; VSS; Output enable; Output Buffers; Out

Figure 4.7: Block Diagram of the CSG PLA

30

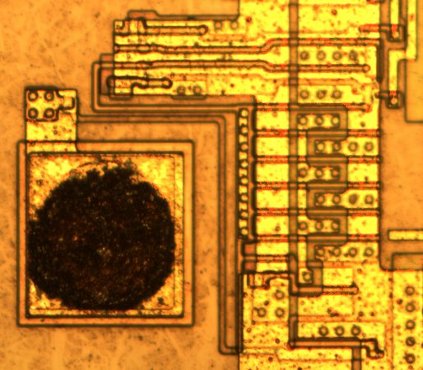
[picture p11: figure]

Figure 4.8: Die photograph of ESD protection, input buffer and inverter

### 4.5 Input Stage

All 16 function inputs of the PLA have the same input stage. An input contains a basic ESD protection made of a grounded gate FET T1 (GGNMOS). With a width of only 50 µm this protection can only stand small ESD stress [Sem08]. The diffusion resistor R1 connects to the input pad I0. This resistor additionally limits current peaks, which supports the ESD protection mechanism.

The input signal is connected to a large inverting super buffer T2..T5 which creates an inverted signal #I0B. Additionally there are two inverting super buffers T6..T9 and T10..T13 to create a buffered signal I0B. These two output signals I0B and #I0B are connected to the rows of the AND array.

Note that the depletion mode pull-up devices of the final stages, T4 and T12 are very strong drivers, their width to length ratio (W/L) is about 35/6. They must be that strong to pull up all of the 48 small gates in the NOR array quickly enough.

Figure 4.8 shows a photo of an input stage, the redrawn layout is shown in figure 4.9 and the schematics in figure 4.10.

31

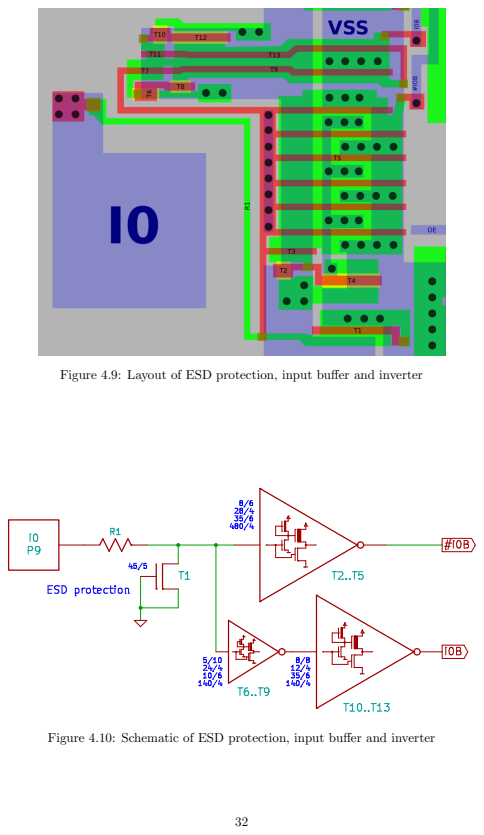
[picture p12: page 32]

Figure 4.9: Layout of ESD protection, input buffer and inverter

Figure 4.10: Schematic of ESD protection, input buffer and inverter

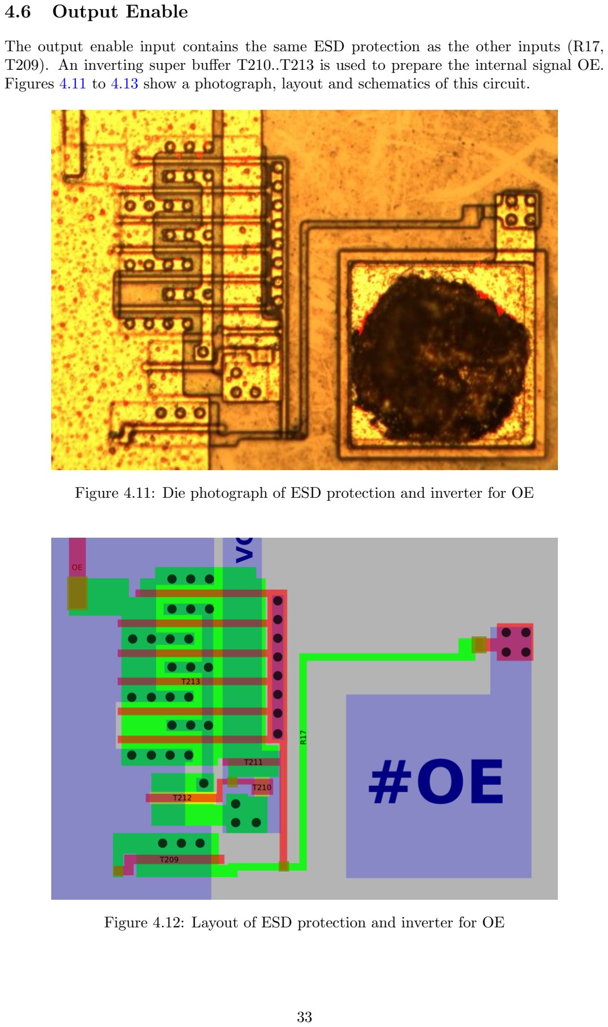
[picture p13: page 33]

### 4.6 Output Enable

The output enable input contains the same ESD protection as the other inputs (R17, T209). An inverting super buffer T210..T213 is used to prepare the internal signal OE. Figures 4.11 to 4.13 show a photograph, layout and schematics of this circuit.

Figure 4.11: Die photograph of ESD protection and inverter for OE

Figure 4.12: Layout of ESD protection and inverter for OE

33

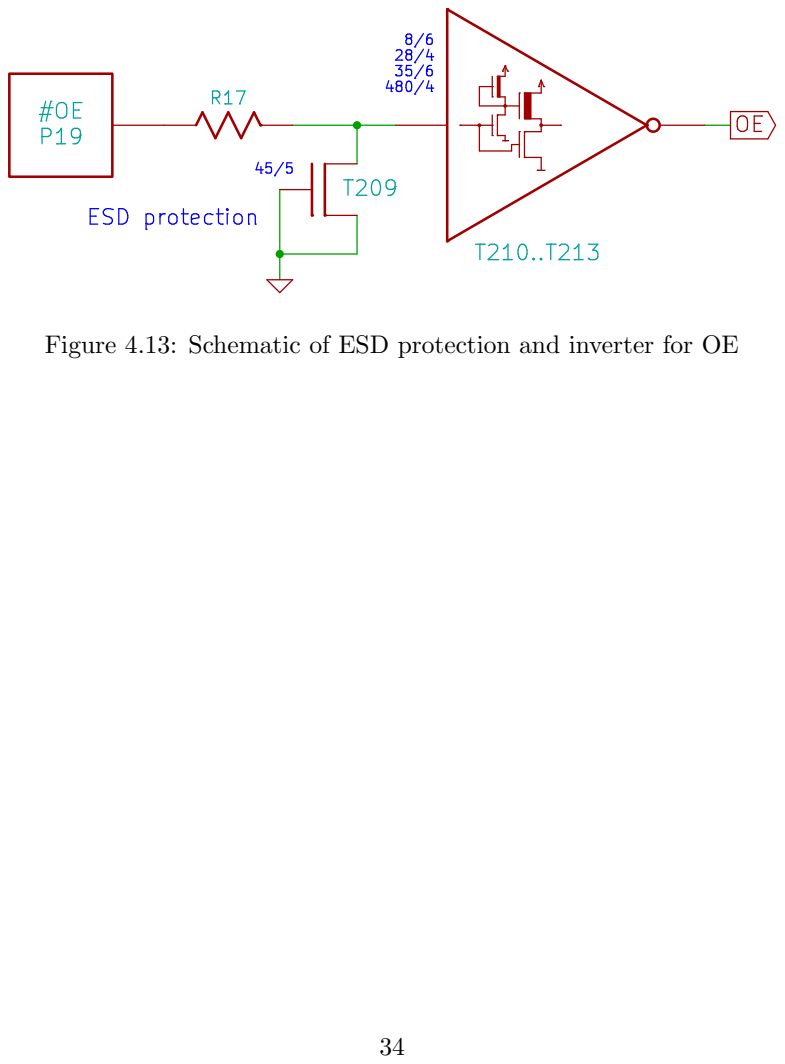
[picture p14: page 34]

Figure 4.13: Schematic of ESD protection and inverter for OE

### 4.7 Product Term Array

A classical PLA contains a programmable AND array which has its outputs connected to a programmable OR array [Maini07]. The AND array is used for product terms and the OR array for sum terms.

The actual implementation of the AND array is realized with NOR gates with inverted inputs on the CSG PLAs, which has the same functionality according to De Morgan’s laws. This implementation is also explained in [Mead79].

The product term array has 32 inputs, I0B, #I0B to I15B and #I15B and 48 outputs P0 to P47. Each of these 48 output columns can carry the result of a product term of the inputs.

Each input row is connected to 48 polysilicon tracks which can become gates for enhancement mode FETs. The field oxide mask, which also defines the diffusion layer, is used to program this array. Each of the 48 * 32 array gates forms a FET only if it crosses a diffusion area. Otherwise it is just a piece of non-functional polysilicon.

Each output column has a pull up circuit to pull it high when no FET in the column is on. Any of the FETs in each column can pull the column down. This circuit is used to implement NOR functions.

The die photograph and layout 4.15 show two inactive nodes in the product term array and two nodes which were mask programmed to build FETs. The same parts are also shown in the schematic 4.16. To keep the numbering scheme simple, all gates have a transistor annotation ’T...’, although only some of them are real transistors. The whole array is totally uniform, therefore only a part of it is shown here.

Figure 4.14 shows the encoding of the whole NOR array. The product terms are nearly in the same order as it was extracted from an 82S100. The unused terms p8 and p29 were removed (refer to section 2.7) and replaced with the terms initially numbered p31 and p30. So the numbering of the product terms is slightly different.

Figure 4.17 shows a high resolution detail of the pull-up circuit, even the contact through gate oxide can be seen there. The two images in figure 4.18 give a very good impression about the third dimension of the chip’s surface. The microscope was focused on the active area at the first picture and on the poly or metal layer on the second one.

The graphics also show the pull up circuit mentioned before. Because of its relatively large width the pull up FET T426 is not a depletion mode FET but an enhancement mode device. Its gate is pulled up to VCC with the depletion mode FET T424. This causes T426 to be switched on steadily.

The function of T425 could not be clarified. Its gate is tied to VSS, therefore this FET is always off. One potential use of it could be bootstrapping. In this case the parasitic capacity CDS of T425 would pull down or push up the gate voltage of T426 for a short moment, whenever the source voltage of this FET changes. This would increase its channel resistance on falling edges and decrease it on rising edges. Note that the drain-gate capacitance CDG even has an opposite effect. SPICE simulations⁵ did not reveal a useful effect of this transistor. Also simulations with a zero-threshold device did not help. However, when a poly cap of a similar size, e.g., 20 µm×10 µm is put into the simulation, there is a much stronger bootstrap effect, which speeds up this gate by about 1 ns. Possibly the SPICE model parameters were not chosen correctly to simulate the intended effect. So it looks like the real reason for T425 is still unknown.

5MOSFET model level 3, various parasitic parameters defined with generic values, L, W, AS, AD, PS, PD measured and entered

35

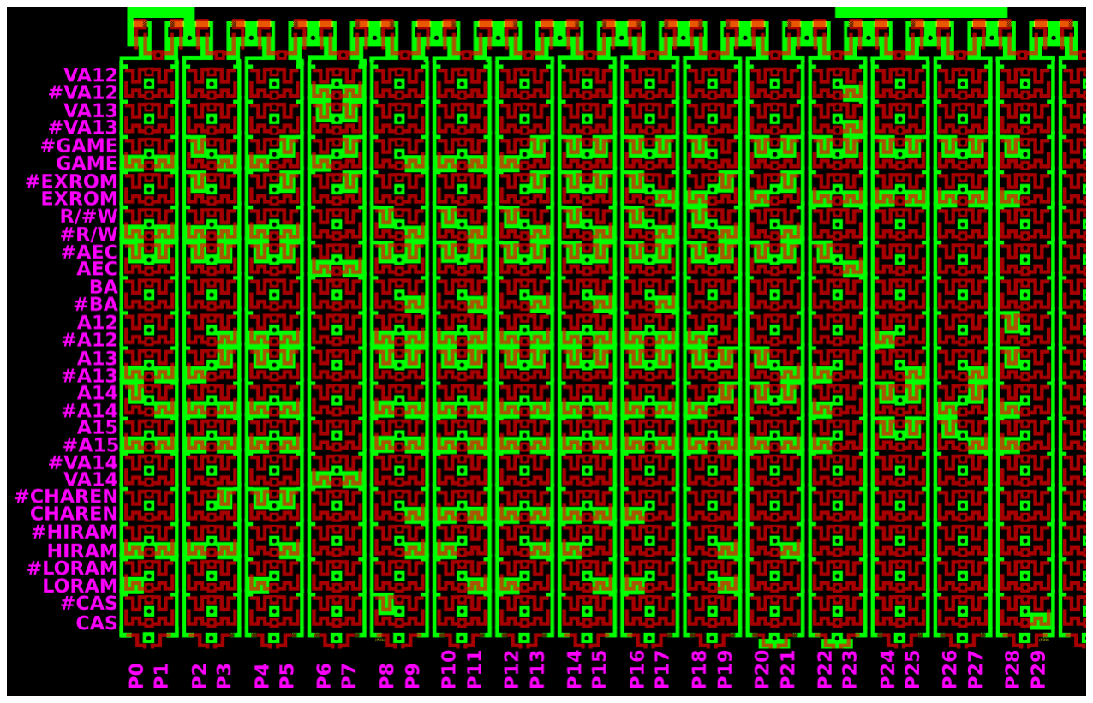
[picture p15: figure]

Figure 4.14: Product terms made readable in the layout

(a) Die photograph | (b) Layout

Figure 4.15: A part of the product term array

36

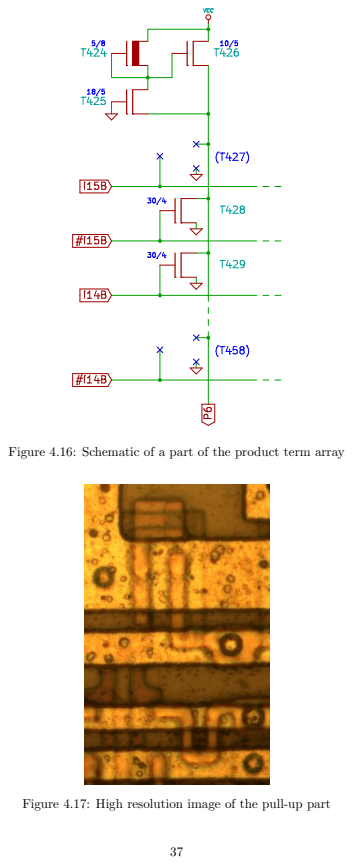
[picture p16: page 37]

Figure 4.16: Schematic of a part of the product term array

Figure 4.17: High resolution image of the pull-up part

(a) Focus on active area | (b) Focus on poly

Figure 4.18: Different focal planes

The enhancement mode FET threshold voltage Vth in the CSG chips cannot be measured directly. However, it can be found by looking at the output pad buffers: They are implemented using a totem pole made of two NMOS FETs. When an output delivers a high level, the pull-up FET gets its gate voltage from a super buffer with a depletion mode pull-up, which delivers VCC virtually. This NMOS pull-up can pull the output not higher than about VCC − Vth. Measurements showed that the output voltage is about 3.7 V to 3.8 V, which means that Vth is approximately 1.3 V.
Note that Vth can not be measured on an input pad accurately, because the inputs are connected to a super buffer with depletion mode devices in its pull-up branches. A high level is only detected if the input voltage is higher than the inverter voltage Vinv, which is determined by the FET size ratios. However, given the large ratios seen on CSG chips, Vinv is not much higher than Vth.

Unfortunately it is not possible to accurately simulate or calculate the dynamic behaviour of these chips, because too few parameters are known. However, some things can be calculated, for example the output voltage of a product term VO. It depends on how many pull-down FETs are switched on, the size of the FETs involved, VCC and Vth.

As an example VO for a single pull-down device being active is calculated here. The gate and source of a pull-up FET (e.g. T426) are at approximately VCC (5 V). Its source is at output voltage VO.
VGSu = VDSu = VCC − VO | (4.1)

The drain of a pull-down FET (e.g. T428) is also at VO, its gate is at VCC, due to the depletion mode super buffers, and the source at VSS (0 V).

VGSd = VCC | (4.2)
VDSd = VO | (4.3)

The ratio between pull-up device and pull-down device will be called z:

z =

Wd
Ld Wu Lu | (4.4)

38

Because of (4.1) VGS < VDS + Vth is valid, the pull-up FET is saturated. So its drain current is calculated as follows:

I = K

W
L

(VGS − Vth)

2
(4.5)

With K being a constant which describes some physical properties of the FETs. Refer to [Raj08] for details about K, (4.5) and (4.6).

Because the pull-up device is a depletion mode FET, it is known that VO < VCC − Vth, which means that VGS > VDS + Vth. Therefore the pull-down FET is not saturated. For this case (4.6) is used.

I = K

W
L

[2(VGS − Vth)VDS − V

2
DS] | (4.6)

This equation can be written in a form which will be more handy later, the result is (4.7)

| 6

I = K

W
L

[2(VGS − Vth)VDS − V

2
DS]

= K

W
L

[2VGSVDS − 2VDSVth − V

2
DS]

= K

W
L

[V

2
GS − 2VGSVth + V

2
th
− V

2
GS − V

2
DS − V

2
th + 2VGSVDS + 2VGSVth − 2VDSVth]

= K

W
L

[(VGS − Vth)

2 − (VGS − VDS − Vth)

2
] | (4.7)

The current flows through both FETs and there is no significant load current once the circuit reached a static state, therefore (4.5) and (4.7) can be used:

IDu = IDd

K

W u
Lu

(VGSu − Vth)

2 = K

W d
Ld [(VGSd − Vth)

2 − (VGSd − VDSd − Vth)

2
]

With the values from (4.1) to (4.3):

(VCC − VO − Vth)

2 = z[(VCC − Vth)

2 − (VCC − VO − Vth)

2
]

(VCC − VO − Vth)

2 = z(VCC − Vth)

2 − z(VCC − VO − Vth)

2

(z + 1)(VCC − VO − Vth)

2 = z(VCC − Vth)

2

Both sides are positive:
√
z + 1(VCC − VO − Vth) = √
z(VCC − Vth)
√
z + 1(VCC − Vth) −

√
z + 1VO =

√
z(VCC − Vth)
(

√
z + 1 −

√

z)(VCC − Vth) = √
z + 1VO

VO =

√
z + 1 −

√
z
√
z + 1

(VCC − Vth)

VO = (1 −

√
z
√
z + 1
)(VCC − Vth) | (4.8)

6Thanks to Segher Boessenkool for pointing me to the transformed equation. However, deriving it from the equation found in most books needs a bit of magic.

39

Die shots show that Wd
Ld

is about 3Wu
Lu

, so z = 3. With VCC = 5 V to and Vth = 1.3 V this results in:

VO = (1 −

√
3
√
3 + 1

)(5 V − 1.3 V)

∼ 0.5 V

This gives a nice low level output. The voltage will be lower with more pull-down FETs turned on, which is equivalent with higher values for z.

James Redfield was hired by Al Charpentier specifically to work on the VIC-II chip. Al Charpentier, James Redfield and Dave DiOrio developed the VIC-II together. I asked James about the methodology taken to develop the design of the Commodore chips. “There were no logic simulations in those days,” he explains, “everything was manual expect for pure transistor simulations with SPICE [...].” A custom chip design is a very complex work. To give an impression of some of the steps needed to be done, James explains, “Before joining Commodore, one of the grad courses I had taken was a class in VLSI systems design. That class used a book that was the authority for NMOS circuit design at the time: ‘Introduction to VLSI Systems’ by Carver Mead and Lynn Conway [Mead79]. I would highly recommend that any serious student of early VLSI design methodology purchase a copy of this book if at all possible! [...] For example, chapter 1 walks the student through calculations necessary to derive the proper transistor dimensions that will establish logic switching thresholds that yield the greatest noise immunity. The inverter is the most basic element, it is analyzed to develop the optimal aspect ratio (the optimal NMOS switching device W/L dimensions to depletion device W/L dimensions). Once established this ratio can easily be extended to cover [other] logic elements. This optimal aspect ratio is always the same for any given process technology. Once it’s been derived the main consideration for sizing transistors is the load seen by each gate. To assist in sizing the transistors, my methodology was as follows. At the start of the project I would run a series of simulations to generate a table of load versus gate size delay information. The circuit in the simulation was a string of six inverters, each inverter connected to identical load capacitance and the sizes on each inverter all set the same. I would measure the delay time between nodes 3 and 5 in the inverter string and divide by two (to average out rise versus fall delay). I would then have a table of delay versus transistor size for a wide range of load capacitance that I would reference to size paths in the chip I was building. In logic devices, required timing for each path is dictated by the frequency of the clock used to clock the launching and sampling flip-flops. The period of the clock divided by the number of logic gates between each set of flops specified how fast each gate in the path needed to be. I would start with the sampling flop, estimate the input load of the flop and select the size for gate driving the input based on that load and the time budgeted for each gate in that path. That gate having been sized I could move back to the next gate and size that one. This provided a preliminary design that could then be simulated with spice [...].
Of course this is very simplified overview of the design process. Many factors could dictate other size choices for example die real-estate available and power requirement are two other considerations.”

40

Figure 4.19: Die photograph of a part of the sum term array

Figure 4.20: Layout of a part of the sum term array

### 4.8 Sum Term Array

The sum terms are also implemented using a NOR array. The output signals are inverted compared with a plain OR array, but this does not matter since the final output will still go through amplifiers and can be programmed to be inverted anyway.

Each output signal from the product term array is connected to a column of polysilicon. Eight metal rows cross these columns. These rows carry the sum terms #F0 to #F7. Each row has a pull-up circuit of the same kind as used in the product term array.

The field oxide mask is used to program FETs, like in the other array. Additionally contacts to metal are needed here. Obviously these contacts are not at every potential FET, but only at FETs actually implemented. This means that two masks had to be changed to program a PLA.

The ratio between pull-up FET and pull-down FETs is the same as in the product term array.

Figures 4.19 to 4.21 show a photograph, layout and schematics of this circuit.

41

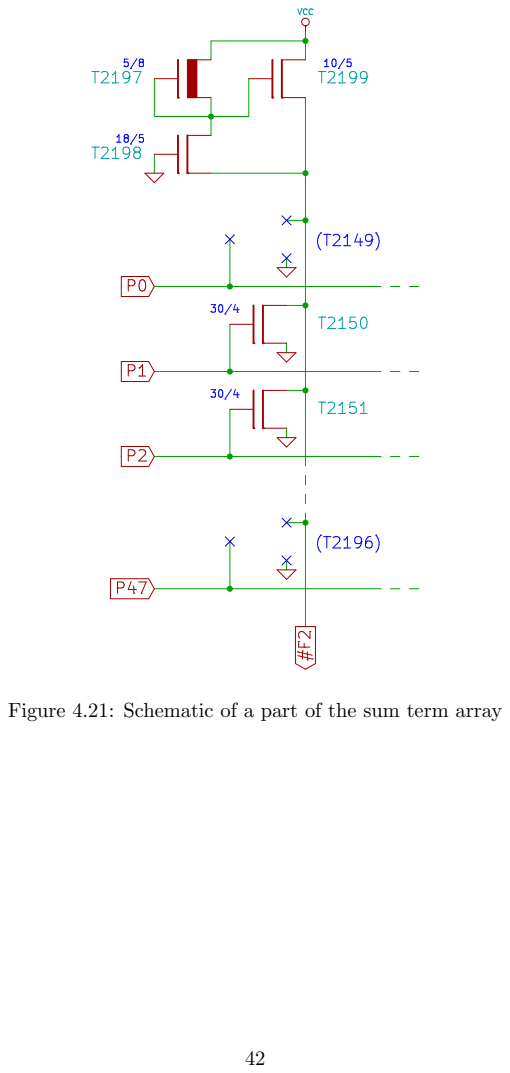
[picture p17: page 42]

Figure 4.21: Schematic of a part of the sum term array

### 4.9 Output Stage

Each function result like #F0 is inverted with a quick inverting super buffer (T2302..T2305), which results in the complementary value F0. F0 and #F0 are combined with OE with a logical NAND function (T2306..T2310). The resulting intermediate signals are buffered with two larger super buffers to be able to drive the gates of the pad buffer quickly.

The push-pull totem poles for the output pads are really huge. These 16 FETs take about 25% of the chip area. Bj¨orn ‘JMP$FCE2’ Wieck examined their drive strength. When an output is low, it can sink more than 80 mA while still being in the linear region⁷
, i.e. the
output is still below 1.3 V in this situation. When the output switched from low to high, the pull-up FET will deliver the same current as long as the source voltage is still very low, so also low to high transitions rise over the threshold voltage quickly. Due to the characteristics of an N-channel FET the drive strength decreases at higher output levels which result in lower VGS.

Figure 4.22 to 4.24 show photo, layout and schematic diagram of the output stage.

Why did the initials disappear? People who worked on reverse engineering CSG chips noticed that older chips usually have the initials of their engineers written on it. Later revisions do not have these nice signatures anymore. A certain incident was the reason.
In about 1984 or 1985 several chips were redrawn for the HMOS2 process to reduce cost. Bret Raymis worked on a shrink of the SID chip from 6 to 5 micron. He recalls, “I almost got fired for putting my initials on the chip with it appearing in 3 spots across the die with ‘Dave’sa Bar and Grill’. The SID had three identical large blocks with a hole in the middle.” Dave DiOrio confirms this story, “It actually got fab’ed and the mask shop went berserk.”
Bret’s intention was to make a joke, “But the president of Commodore did not think it was funny. Fortunately Mike [Angelina] took the heat and I did not get fired.” The chip in question was the 8580 R1 most likely. Unfortunately only later revisions have been seen up to now, which do not carry this Easter egg anymore.
James Redfield concludes, “And from that day on we were no longer permitted to include our initials on the chips.”

a
referring to Dave DiOrio

7Don’t try this at home, the PLA won’t survive this for long

43

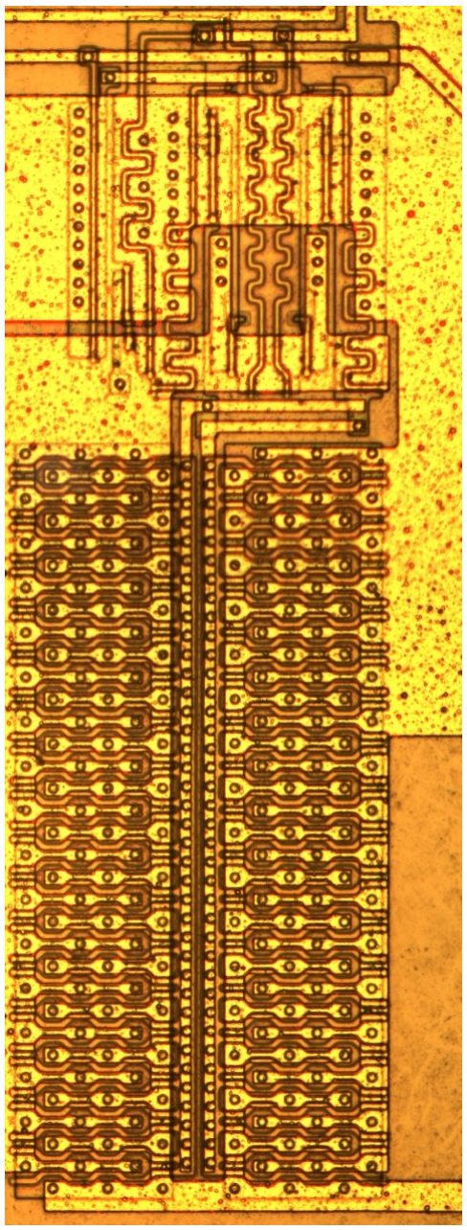
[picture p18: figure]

Figure 4.22: Die photograph of the output stage

44

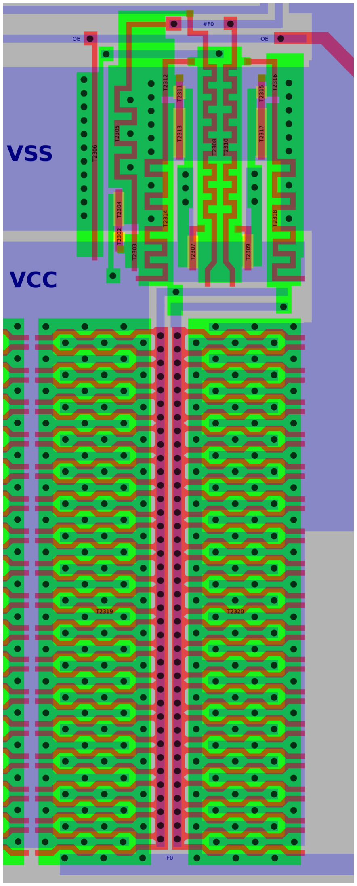
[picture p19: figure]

Figure 4.23: Layout of the output stage

45

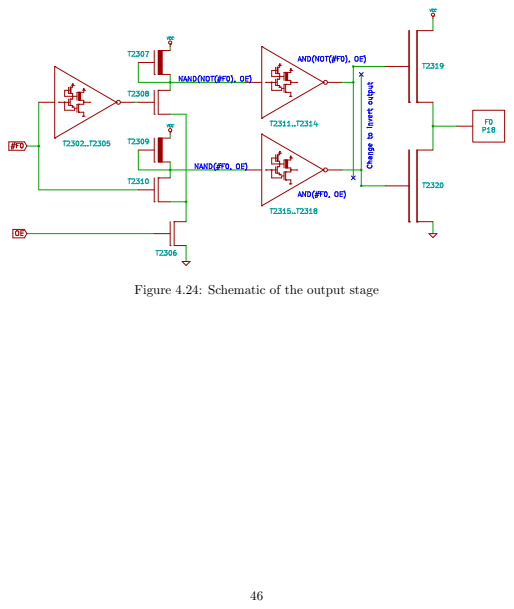
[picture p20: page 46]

Figure 4.24: Schematic of the output stage

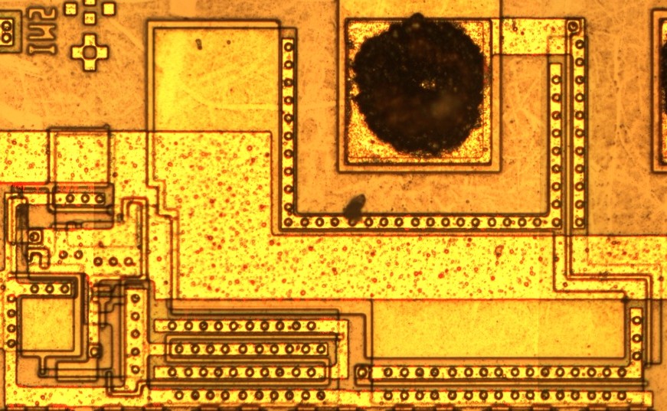
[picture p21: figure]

Figure 4.25: Die photograph of the back-gate bias generator

### 4.10 Back-Gate Bias Generator

The HMOS1 and HMOS2 processes used to make the PLAs use a back-gate bias generator to adjust the FET threshold voltage. Due to the body effect the threshold voltage of NMOS devices increases when the body voltage drops. The back-gate bias generator consists of an oscillator and a charge pump.

The circular oscillator consists of three inverters, T2462/T2463, T2458..T2461 and T2465/T2466. The oscillation frequency is limited by two RC low-pass filters, T2464/C3 and T2467/C2. The totem pole T2456, T2457 and C1 form the charge pump. The two FETs T2454 and T2455 function like diodes for the charge pump.

Figure 4.29 show a simulation of this circuit. The actual voltages and the oscillation frequency depend from the process parameters. As most of the parameters are not known, this simulation is only useful to show the working principle.

47

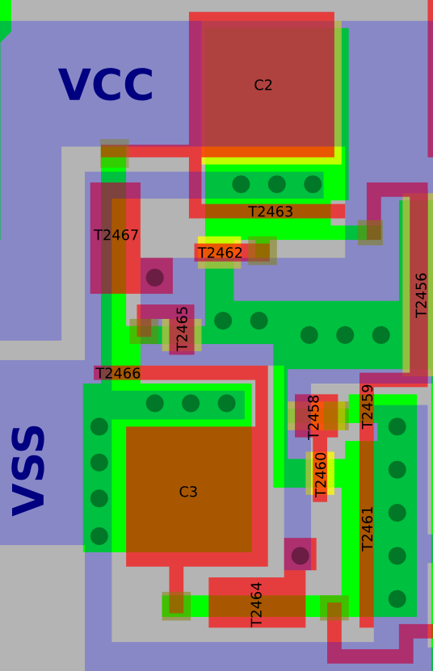
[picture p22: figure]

Figure 4.26: Layout of the back-gate bias generator (oscillator)

48

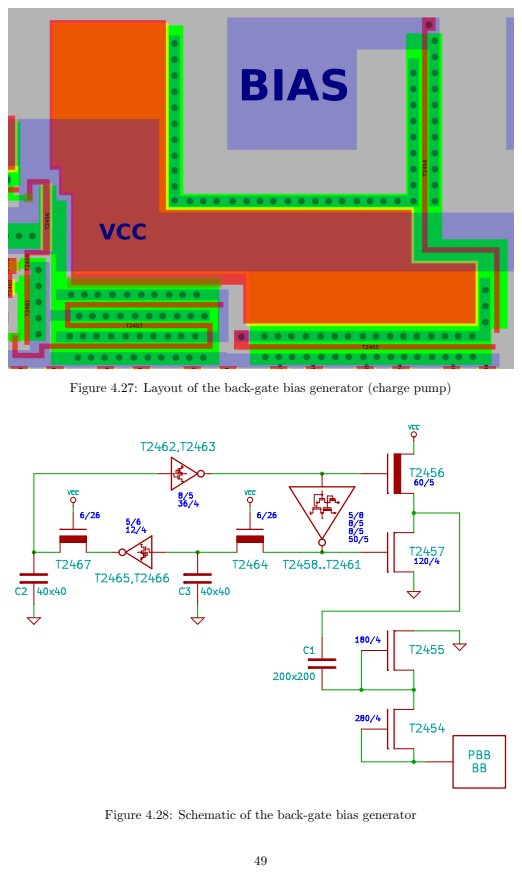
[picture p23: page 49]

Figure 4.27: Layout of the back-gate bias generator (charge pump)

Figure 4.28: Schematic of the back-gate bias generator

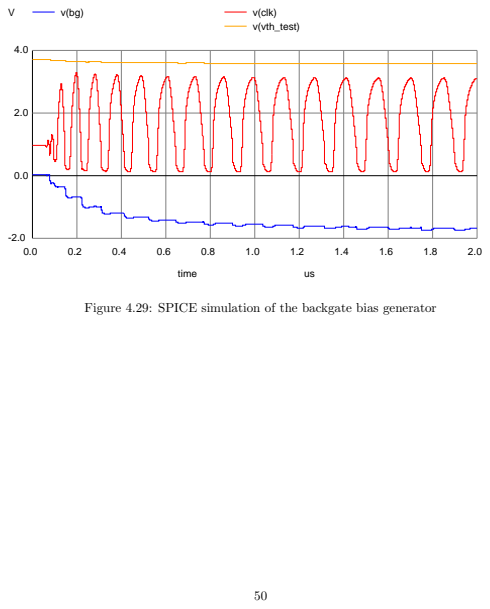
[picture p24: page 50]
time; v(clk); v(vth_test)

Figure 4.29: SPICE simulation of the backgate bias generator

### 4.11 List of Components

Table 4.1 shows the list of transistors, resistors and capacitors found on an MOS 8700R1 and their assignment to functional blocks described in this document.

Annotation | Part usage
R1..R16 | Part of ESD protection for inputs I0..I15
T1..T208 | ESD protection, input buffer and inverter for inputs I0..I15
R17 | Part of ESD protection for OE input
T209..T213 | ESD protection and input buffer for OE
T214..T1893 | NOR array for product terms, only some transistors actually
| populated
T1894..T2301 | NOR array for sum terms, only some transistors actually pop-
| ulated
T2302..T2453 | Output stage and pad push-pull pad buffers
T2454..T2467, C1..C3 | Back-gate bias generator

Table 4.1: List of components on 8700R2 chip

51

# Chapter 5

# A PLA Replacement: realPLA

The realPLA is a PLA replacement which I developed with the results of the investigations shown in this document. It was developed with the aim to work with all C64s which work with original PLAs too. It uses only parts which are still in production and available at low cost as the time of writing.

The logic functions are implemented in a Lattice LC4032V CPLD. Although it runs at 3.3 Volts, it is 5 Volt tolerant. Because of this property the CPLD inputs can be connected to the PLA inputs directly. They even have an input threshold voltage which is quite close to the one of the CSG PLAs.

The logic programmed to the CPLD has been converted from the JEDEC file converted from a 82S100 to VHDL with a small Python tool. The CASRAM equation does not fit into one macrocell of this CPLD, because it either has too many inputs or it needs to use feedback from other terms. To provide matching propagation delays for all input to output paths, all terms have been edited to use two levels of logic. A binary PLA dump has been used to execute a unit test for the logic part of this PLA implementation.

In addition to the logic functions of the PLA, also the dynamic characteristics have to be similar to the original parts, mainly propagation delay and slew rates.

It would have been possible to increase the propagation delay of the CPLD by using additional internal nodes. However, as the speed grade of the CPLD may vary and also depends on factors like temperature, this was not the way chosen. Instead an RC delay has been added for each channel, plus a Schmitt trigger to get well-defined edges again. The RC delay has been dimensioned to get an overall propagation delay as an average original PLA. Finally each output incorporates a serial resistor to limit its slew rate. The Schmitt trigger which also translates the voltage from 3.3 V to 5 V has the additional positive effect that high to low transitions are slightly more delayed than than low to high transitions, which completely inhibits any chip select overlap.

The PCB has been designed to have nearly the same size as an original DIP-28 PLA. This allows it to fit in all C64s, even if there is e.g., a heat sink attached to adjacent chips.

The design of the realPLA is licensed under Creative Commons Attribution-ShareAlike 3.0 Unported (CC BY-SA 3.0). The design files are available at https://bitbucket.org/skoe/pla. (https://bitbucket.org/skoe/pla) Figure 5.2 shows the schematic diagram of realPLA.

52


Figure 5.1: The realPLA

53


Figure 5.2: realPLA schematic diagram

# Chapter 6

# Conclusion

There have been numerous discussions about the PLA and its properties in the past. The reason may have been bad PLA replacements which did not work on all C64s or not with all hardware extensions. The full logic of the PLA was not officially documented by Commodore, which made it necessary to reverse engineer it to be able to implement advanced programs or hardware extensions. In contrast to the CPU, which was of interest for every assembler programmer, the PLA was only examined by a few people. This is another point which made the PLA look somewhat intransparent.

However, this document shows that there is no such obscurity and that most of its properties have been found years ago already. Others can be measured easily or can be derived from C64 schematics. The logic incorporated in the PLA is shown in different comprehen-sive ways. With the hardware facts presented in this document it is easy to see what the important requirements for a compatible PLA replacement are. It also helps to identify properties of PLA replacements which could make it incompatible to certain boards.

Programmable memory devices (PROMs, EPROMs) have frequently been used to replace PLAs. The idea to do this is reasonable, a PLA is a device with a programmable AND array followed from a programmable OR array, while a PROM is a device with a fixed AND array¹
, and a programmable OR array. One must be aware that a PLA replacement has to comply with the requirements of a narrow timing window to work with all boards, no matter if it is made using programmable logic devices or programmable memory. Additionally, the timing printed on the chip is usually not the typical delay which counts here. Note that programmable logic devices usually have a very well defined and documented timing behavior, while PROMs may have different propagation delays for different address lines, caused by their internal geometry in rows and columns. So it is acceptable to use a PROM as PLA replacement, as long as the actual timing has been verified accurately.

The SuperPLA has been the first professional PLA replacement. It is known to work on nearly all boards. Yet, it happens to fail on a few C64 boards with a KU serial number. This board revision is infamous for its fragile timing. Reasons for the failures are hard to identify. It may be caused by the not fully authentic timing or by the fast slew rates which even caused undershoots in the measurements.

The EPROM PLA replacement M27C512-90B6 is one of the simplest PLA replacements. Recalling the bad experience some people had with the compatibility of other EPROM PLA replacements it was highly controversial. However, the sample tested in this document made a good impression. The only negative point seen was the slightly too fast propagation delay, which is most likely the reason that it also failed with a few KU boards.

1The address decoder

55

The prototypes of the realPLA have been tested on about 20 C64 boards of different board revisions, including KU boards. The compatibility of the realPLA with different C64 expansions has been checked, for example EasyFlash 3 and Turbo Chameleon. The realPLA worked on all of these boards. However, there can never be a guarantee that a PLA or PLA replacement works on absolutely every board with any extension ever designed. The different lots and revisions of C64 computers with different VIC-II chips have different timing requirements, which was also known to Commodore: They defined different RC delays for different combinations.

The chapter which describes the reverse engineering and inner workings of a CSG PLA may be of less practical interest. It is more focused on understanding how this part was developed and how it works, for educational and historical purposes.

Hopefully this document can help other hardware projects, emulators and programmers to improve and prolong the experience with the definitely best computer of the world ;)

56

# Appendix A

# C64 Memory Configurations Explained

The Commodore 64 memory configurations are explained in various books and other documents. Some of these tables are incomplete or even flawed.

For the sake of completeness of an C64 PLA article they are listed here once more. All tables have been generated directly from the JEDEC file read out from a 82S100 PLA, so it is very unlikely that there are mistakes in them.

There is a mechanism implemented in the PLA logic which is not shown in the tables below. Section 2.4 explains how the VIC-II can halt the CPU when it wants to take over the bus. If write accesses by the CPU address the I/O area during this phase, the PLA selects the I/O chips accordingly. But to make sure that the (dummy) read cycles in this phase will never accidentally acknowledge an interrupt, the PLA redirects them to RAM. The signals BA and R/#W are used to identify this situation.

Jens Sch¨onfeld’s PLA analyzer is useful to explore the C64 memory maps interactively. It can be downloaded at http://icomp.de/products/SuperPLA/pla_analyzer.zip. It runs in a DOS box, also in the DOS emulator dosbox under Linux.

CPU Memory Configuration

#LORAM, #HIRAM, #GAME, #EXROM = 1111

Table A.1 shows the standard memory configuration ($01 = #$37). No cartridge is attached. BASIC, I/O and KERNAL are visible to the CPU. With #CHAREN = 0 ($01 = #$33), CHARROM (read) and RAM (write) are mapped instead of I/O.

57

#CHAREN 1 | #CHAREN 0

Address | CPU R | CPU W | CPU R | CPU W
$0000 | ram | ram | ram | ram
$1000 | ram | ram | ram | ram
$2000 | ram | ram | ram | ram
$3000 | ram | ram | ram | ram
$4000 | ram | ram | ram | ram
$5000 | ram | ram | ram | ram
$6000 | ram | ram | ram | ram
$7000 | ram | ram | ram | ram
$8000 | ram | ram | ram | ram
$9000 | ram | ram | ram | ram
$A000 | BASIC | ram | BASIC | ram
$B000 | BASIC | ram | BASIC | ram
$C000 | ram | ram | ram | ram
$D000 | I/O | I/O | CHARROM | ram
$E000 | KERNAL | ram | KERNAL | ram
$F000 | KERNAL | ram | KERNAL | ram

Table A.1: C64 memory configurations with LHGX = 1111

#LORAM, #HIRAM, #GAME, #EXROM = 011x

Table A.2 shows the configuration with BASIC banked out ($01 = #$36). If an 8k cartridge is attached, it is also banked out. I/O and KERNAL are visible to the CPU. With #CHAREN = 0 ($01 = #$32), CHARROM (read) and RAM (write) are mapped instead of I/O.

#CHAREN 1 | #CHAREN 0

Address | CPU R | CPU W | CPU R | CPU W
$0000 | ram | ram | ram | ram
$1000 | ram | ram | ram | ram
$2000 | ram | ram | ram | ram
$3000 | ram | ram | ram | ram
$4000 | ram | ram | ram | ram
$5000 | ram | ram | ram | ram
$6000 | ram | ram | ram | ram
$7000 | ram | ram | ram | ram
$8000 | ram | ram | ram | ram
$9000 | ram | ram | ram | ram
$A000 | ram | ram | ram | ram
$B000 | ram | ram | ram | ram
$C000 | ram | ram | ram | ram
$D000 | I/O | I/O | CHARROM | ram
$E000 | KERNAL | ram | KERNAL | ram
$F000 | KERNAL | ram | KERNAL | ram

Table A.2: C64 memory configurations with LHGX = 011x

58

#LORAM, #HIRAM, #GAME, #EXROM = 1000

Table A.3 shows the configuration with a 16k cartridge attached but banked out ($01 = #$35). I/O is visible to the CPU. #CHAREN = 0 ($01 = $31) can be used to hide the I/O space, but it does not bank in CHARROM.

#CHAREN 1 | #CHAREN 0

Address | CPU R | CPU W | CPU R | CPU W
$0000 | ram | ram | ram | ram
$1000 | ram | ram | ram | ram
$2000 | ram | ram | ram | ram
$3000 | ram | ram | ram | ram
$4000 | ram | ram | ram | ram
$5000 | ram | ram | ram | ram
$6000 | ram | ram | ram | ram
$7000 | ram | ram | ram | ram
$8000 | ram | ram | ram | ram
$9000 | ram | ram | ram | ram
$A000 | ram | ram | ram | ram
$B000 | ram | ram | ram | ram
$C000 | ram | ram | ram | ram
$D000 | I/O | I/O | ram | ram
$E000 | ram | ram | ram | ram
$F000 | ram | ram | ram | ram

Table A.3: C64 memory configurations with LHGX = 1000

#LORAM, #HIRAM, #GAME, #EXROM = 101x

Table A.4 shows the configuration with BASIC and KERNAL banked out ($01 = #$35). If an 8k cartridge is attached, it is also banked out. I/O is visible to the CPU. With #CHAREN = 0 ($01 = #$32), CHARROM (read) and RAM (write) are mapped instead of I/O.

59

#CHAREN 1 | #CHAREN 0

Address | CPU R | CPU W | CPU R | CPU W
$0000 | ram | ram | ram | ram
$1000 | ram | ram | ram | ram
$2000 | ram | ram | ram | ram
$3000 | ram | ram | ram | ram
$4000 | ram | ram | ram | ram
$5000 | ram | ram | ram | ram
$6000 | ram | ram | ram | ram
$7000 | ram | ram | ram | ram
$8000 | ram | ram | ram | ram
$9000 | ram | ram | ram | ram
$A000 | ram | ram | ram | ram
$B000 | ram | ram | ram | ram
$C000 | ram | ram | ram | ram
$D000 | I/O | I/O | CHARROM | ram
$E000 | ram | ram | ram | ram
$F000 | ram | ram | ram | ram

Table A.4: C64 memory configurations with LHGX = 101x

#LORAM, #HIRAM, #GAME, #EXROM = 001x or 00x0

The configurations hown in table A.5 have everything banked out ($01 = #$34 or $01 = #$30). No cartridge, an 8k or an 16k cartridge is attached. Only RAM is visible to the CPU. #CHAREN has no effect in this case.

Address | CPU R | CPU W
$0000 | ram | ram
$1000 | ram | ram
$2000 | ram | ram
$3000 | ram | ram
$4000 | ram | ram
$5000 | ram | ram
$6000 | ram | ram
$7000 | ram | ram
$8000 | ram | ram
$9000 | ram | ram
$A000 | ram | ram
$B000 | ram | ram
$C000 | ram | ram
$D000 | ram | ram
$E000 | ram | ram
$F000 | ram | ram

Table A.5: C64 memory configurations with LHGX = 001x or 00x0

60

#LORAM, #HIRAM, #GAME, #EXROM = 1100

Table A.6 shows the standard 16k cartridge configuration ($01 = #$37). A 16k cartridge is attached. ROML/ROMH, I/O and KERNAL are visible to the CPU. With #CHAREN = 0 ($01 = #$33), CHARROM (read) and RAM (write) are mapped instead of I/O.

#CHAREN 1 | #CHAREN 0

Address | CPU R | CPU W | CPU R | CPU W
$0000 | ram | ram | ram | ram
$1000 | ram | ram | ram | ram
$2000 | ram | ram | ram | ram
$3000 | ram | ram | ram | ram
$4000 | ram | ram | ram | ram
$5000 | ram | ram | ram | ram
$6000 | ram | ram | ram | ram
$7000 | ram | ram | ram | ram
$8000 | ROML | ram | ROML | ram
$9000 | ROML | ram | ROML | ram
$A000 | ROMH | ram | ROMH | ram
$B000 | ROMH | ram | ROMH | ram
$C000 | ram | ram | ram | ram
$D000 | I/O | I/O | CHARROM | ram
$E000 | KERNAL | ram | KERNAL | ram
$F000 | KERNAL | ram | KERNAL | ram

Table A.6: C64 memory configurations with LHGX = 1100

#LORAM, #HIRAM, #GAME, #EXROM = 0100

The 16k cartridge configuration with ROML banked out ($01 = #$36) is shown in table A.7. A 16k cartridge is attached. ROMH, I/O and KERNAL are visible to the CPU. With #CHAREN = 0 ($01 = #$32), CHARROM (read) and RAM (write) are mapped instead of I/O.

61

#CHAREN 1 | #CHAREN 0

Address | CPU R | CPU W | CPU R | CPU W
$0000 | ram | ram | ram | ram
$1000 | ram | ram | ram | ram
$2000 | ram | ram | ram | ram
$3000 | ram | ram | ram | ram
$4000 | ram | ram | ram | ram
$5000 | ram | ram | ram | ram
$6000 | ram | ram | ram | ram
$7000 | ram | ram | ram | ram
$8000 | ram | ram | ram | ram
$9000 | ram | ram | ram | ram
$A000 | ROMH | ram | ROMH | ram
$B000 | ROMH | ram | ROMH | ram
$C000 | ram | ram | ram | ram
$D000 | I/O | I/O | CHARROM | ram
$E000 | KERNAL | ram | KERNAL | ram
$F000 | KERNAL | ram | KERNAL | ram

Table A.7: C64 memory configurations with LHGX = 0100

#LORAM, #HIRAM, #GAME, #EXROM = 1110

Table A.8 shows the standard 8k cartridge configuration ($01 = #$37). An 8k cartridge is attached. ROML, BASIC, I/O and KERNAL are visible to the CPU. With #CHAREN = 0 ($01 = #$33), CHARROM (read) and RAM (write) are mapped instead of I/O.

#CHAREN 1 | #CHAREN 0

Address | CPU R | CPU W | CPU R | CPU W
$0000 | ram | ram | ram | ram
$1000 | ram | ram | ram | ram
$2000 | ram | ram | ram | ram
$3000 | ram | ram | ram | ram
$4000 | ram | ram | ram | ram
$5000 | ram | ram | ram | ram
$6000 | ram | ram | ram | ram
$7000 | ram | ram | ram | ram
$8000 | ROML | ram | ROML | ram
$9000 | ROML | ram | ROML | ram
$A000 | BASIC | ram | BASIC | ram
$B000 | BASIC | ram | BASIC | ram
$C000 | ram | ram | ram | ram
$D000 | I/O | I/O | CHARROM | ram
$E000 | KERNAL | ram | KERNAL | ram
$F000 | KERNAL | ram | KERNAL | ram

Table A.8: C64 memory configurations with LHGX = 1110

62

#LORAM, #HIRAM, #GAME, #EXROM = xx01

The Ultimax configuration is shown in table A.9. An Ultimax cartridge is attached. Only 4k RAM, ROML, I/O and ROMH are visible to the CPU. Note that ROMH is mapped to $E000. Memory areas marked with ”-” are not mapped, i.e. read accesses to these areas result in values depending on the current state of the floating data bus. Write accesses to ROML or ROMH address space are forwarded to the cartridge, they have no effect on usual ROM based cartridges. $01 does not change the memory configuration in this mode.

Address | CPU R | CPU W
$0000 | ram | ram
$1000 | - | -
$2000 | - | -
$3000 | - | -
$4000 | - | -
$5000 | - | -
$6000 | - | -
$7000 | - | -
$8000 | ROML | ROML
$9000 | ROML | ROML
$A000 | - | -
$B000 | - | -
$C000 | - | -
$D000 | I/O | I/O
$E000 | ROMH | ROMH
$F000 | ROMH | ROMH

Table A.9: C64 memory configurations with LHGX = xx01

VIC-II Memory Configuration

The VIC-II is able to address 16 kByte of memory, which requires 14 address bits. The C64 has 64 kByte of DRAM, there are 4 VIC-II banks possible in this memory space.

The two CIA lines #VA14 and #VA15 are used to map one of these four RAM areas to the VIC-II address space. They do not appear in the address column of the tables below, because they are no address lines controlled by the VIC-II.

#VA14 is used by the PLA to decide whether CHARROM has to be visible.

#GAME, #EXROM = 1x or 00

Table A.10 shows the memory map as seen by the VIC-II when not being in Ultimax mode.

63

VIC | #VA14 = 0 | #VA14 = 1
Addr | VIC R | VIC R
$0000 | ram | ram
$1000 | ram | CHARROM
$2000 | ram | ram
$3000 | ram | ram

Table A.10: VIC-II memory configurations with GX = 1x or 00

#GAME, #EXROM = 01

Table A.11 shows the memory map as seen by the VIC-II in Ultimax mode. The address lines A12 to A15 of the C64 address bus are pulled up by RP4 whenever the VIC-II has the bus, so they are %1111 usually.

Table A.12 shows an example where the address lines A12 to A15 are overridden to %0111 by an external cartridge. This shows that a cartridge can hide any internal memory from the VIC-II and provide data for it on the Expansion Port This technique is used in the Turbo Chameleon by Individual Computers. Note that the internal color RAM is still read as usual.

VIC Addr | VIC R
$0000 | ram
$1000 | ram
$2000 | ram
$3000 | ROMH

Table A.11: VIC-II memory configuration with GX = 01

VIC Addr | VIC R
$0000 | -
$1000 | -
$2000 | -
$3000 | ROMH

Table A.12: VIC-II memory configuration with GX = 01, modified address bus

64

# Bibliography

[AC12] http://www.arcadecomponents.com/downloads.html.

[Boess12] Mail by Segher Boessenkool to cbm-hackers mailing list, 2012, http://www.softwolves.com/arkiv/cbm-hackers/17/17308.html.

[CHM09] Computer History Museum, 2009, Signetics FPLF Oral History Panel, http://archive.computerhistory.org/resources/access/text/Oral_History/102702200%20.05.01.acc.pdf

[esl11] eslapion, 2011, posts in forum thread The end of the ROM based PLA for the 64, http://sleepingelephant.com/ipw-web/bulletin/bb/viewtopic.php?t=5533.

[Fc77] Fairchild, 1977, part of Fairchild Semiconductor - Full Line Condensed Catalogue 1977, http://www.datasheetarchive.com/93459-datasheet.html.

[Hita2114] Hitachi | Semiconductor, | datasheet | HM472114-3[...] 1024-word x 4-
Bit Static | Random | Access | Memory | http://www.datasheetarchive.com/
HM472114-3-datasheet.html. (http://www.datasheetarchive.com/HM472114-3-datasheet.html)

[Hita4846] Hitachi Semiconductor, datasheet HM4864A[...] 65536-word x 1-Bit Dynamic RAM http://www.datasheetarchive.com/HM4864AP-20-datasheet.html

[Hoffmann06] Kurt Hoffmann, 2006, Systemintegration: Vom Transistor zur groß-integrierten Schaltung, Oldenbourg Wissenschaftsverlag.

[Lev86] William Levak and Ann Arbor, 1986, Commodore 64 Memory Configurations, The Transactor, Volume 6, Issue 05, p. 51-55.

[Mach110] AMD/Lattice, 1995, datasheet, MACH110-12/15/20 High-Density EE CMOS
Programmable | Logic | http://www.latticesemi.com/lit/docs/datasheets/
cpld/14127.pdf. (http://www.latticesemi.com/lit/docs/datasheets/cpld/14127.pdf)

[Maini07] Anil K. Maini, 2007, Digital Electronics: Principles, Devices and Applications, John Wiley & Sons.

[Mead79] Carver Mead, Lynn Conway, 1979, Introduction to VLSI Systems, Addison Wesley, pre-publication drafts available at http://ai.eecs.umich.edu/people/conway/VLSI/VLSIText/VLSIText.html. (http://ai.eecs.umich.edu/people/conway/VLSI/VLSIText/VLSIText.html)

[PLA95] http://www.zimmers.net/anonftp/pub/cbm/firmware/computers/c64/pla. txt. (http://www.zimmers.net/anonftp/pub/cbm/firmware/computers/c64/pla.txt)

[PLS100] Phillips Semiconductors, 1993, product specification Programmable logic arrays (16 x 48 x 8) PLS100/PLS101 http://www.datasheetcatalog.org/datasheet/philips/PLS101A.pdf. (http://www.datasheetcatalog.org/datasheet/philips/PLS101A.pdf)

65

[PRG83] Commodore Computers, 1983, Commodore 64 Programmer’s Reference Guide, Financial Times Prentice Hall.

[Raj08] A. Albert Raj, T. Latha, 2008, VLSI Design, PHI Learning.

[realPLA12] https://bitbucket.org/skoe/realpla.

[Sem08] Oleg Semenov, Hossein Sarbishaei, Manoj Sachdev, 2008, ESD Protection Device and Circuit Design for Advanced CMOS Technologies, Springer.

[Serv85] Commodore Business Machines, Inc., 1985, Service Manual Model C64
Computer, | schematic #251138 at http://www.zimmers.net/anonftp/pub/
cbm/schematics/computers/c64/251138-1of2.gif (http://www.zimmers.net/anonftp/pub/cbm/schematics/computers/c64/251138-1of2.gif) | http://www.zimmers.net/
anonftp/pub/cbm/schematics/computers/c64/251138-2of2.gif (http://www.zimmers.net/anonftp/pub/cbm/schematics/computers/c64/251138-2of2.gif)

[Si75] Signetics, 1975, part of Mos and Bipolar ROM / PROM 1975 http://www.datasheetarchive.com/82S100-datasheet.html.

[TI257] Texas Instruments, 1976, revised 1988, datasheet SN74LS257B [...] Quadru-ple 2-line to 1-line data selectors/multiplexers, http://www.ti.com/lit/gpn/sn74ls257b. (http://www.ti.com/lit/gpn/sn74ls257b)

66

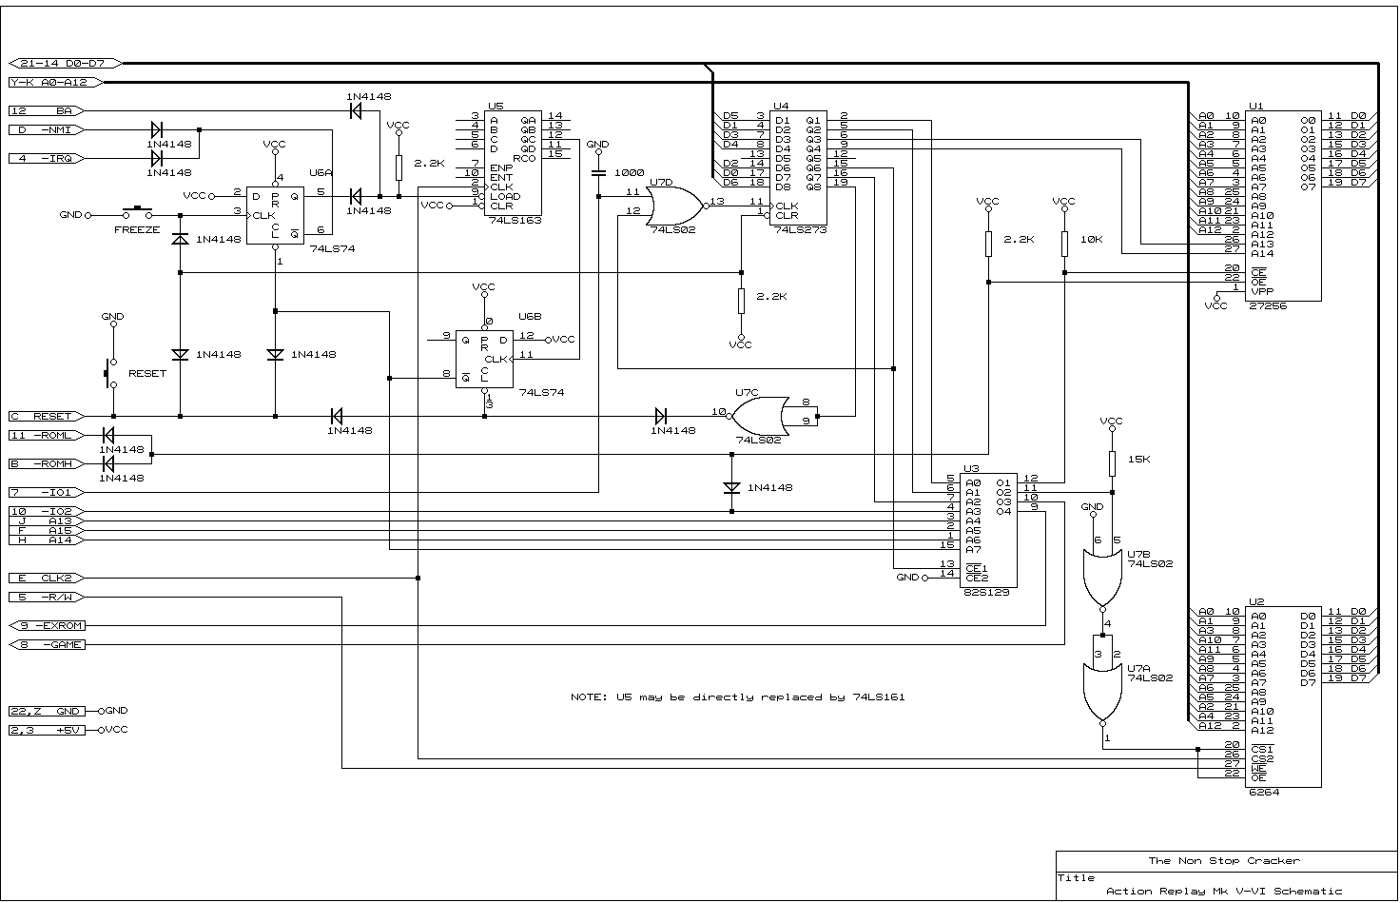
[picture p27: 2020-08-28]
Schematics/Action_Replay_MK5_6.gif

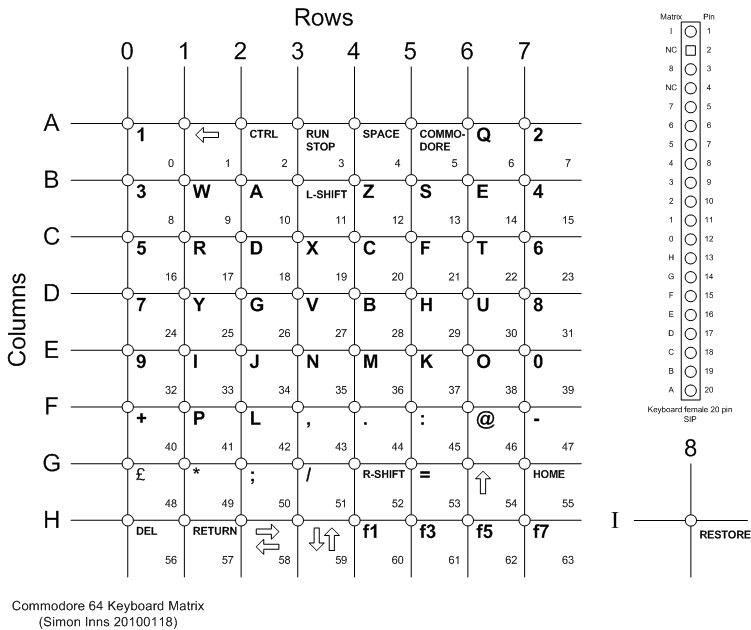
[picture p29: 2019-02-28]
Keyboard/C64_Keyboard_Schematics_PNG.png

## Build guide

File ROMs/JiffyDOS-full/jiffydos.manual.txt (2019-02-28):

JiffyDOS User's Manual:   (converted by Count Zero)

TABLE OF CONTENTS
Section 1:  Introduction.............................................1
Getting Started......................................................1
     After you have installed JiffyDOS...............................1
Getting Help.........................................................1
     Installation Service............................................2
What this Manual Includes............................................2

Section 2:  What Is JiffyDOS.........................................3
Features.............................................................3
Performance..........................................................4
     Speed comparisons...............................................5
Compatibility........................................................6

Section 3:  Using JiffyDOS...........................................9
ROM Switching........................................................9
     C-64, SX-64, and C-128..........................................9
     1541 and compatibles............................................9
     1571 and 1581...................................................9
     Switching ROMs with power on...................................10
Using a Tape Drive with JiffyDOS....................................10
Function Key Definitions............................................11
     Using the function keys with with the directory listing........11
     Disabling the function keys....................................11
     Re-enabling the JiffyDOS function keys.........................12
     Reprogrammable function keys (64 mode).........................12
Listing Freeze......................................................12
Getting Maximum Performance.........................................13
     Re-Writing files...............................................14
     Changing the Sector Interleave.................................14
The JiffyDOS File Copier............................................14
     File copier commands...........................................15
     How to copy files with JiffyDOS................................16
Setting the Sector Interleave.......................................19
     Understanding sector interleave................................19
     Determining the optimum interleave.............................20
If you're not getting top Performance...............................23
     Programs with built-in fast loaders............................23
     BASIC programs.................................................24
     Machine-language programs......................................24
     Fragmented files...............................................24
     Sprites........................................................25
     1571 drives....................................................26
If a Program won't Load or Operate..................................26
Using JiffyDOS with RAM Units.......................................27
Using JiffyDOS Commands with BASIC..................................28

Section 4:  The JiffyDOS Commands...................................29
Command Descriptions................................................29
     Setting the Default Device.....................................30
     Displaying the Directory.......................................31
     Reading the Disk Drive Error Channel...........................31
     Loading BASIC Programs.........................................32
     Saving BASIC Programs..........................................32
     Loading Machine-Language Programs..............................33
     Loading and Running the First Program on Disk..................33
     Verifying Programs.............................................34
     Listing BASIC Programs from Disk...............................34
     Listing ASCII Files from Disk..................................34
     ''Un-NEWing'' a BASIC Program..................................35
     Initializing the Disk Drive....................................35
     Resetting the Disk Drive.......................................36
     Validating Disks...............................................36
     Formatting Disks...............................................36
     Disabling the 1541 ''Head Rattle''.............................38
     Copying files..................................................38
     Changing the Sector Interleave.................................39
     Combining Files and Creating Backups...........................40
     Renaming Files.................................................40
     Scratching (Deleting) Files....................................41
     Locking and Unlocking Files....................................41
     Directing Output to a Printer..................................42
     Printing the Screen............................................42
     Disabling the JiffyDOS Function Keys...........................43
     Re-Enabling the JiffyDOS Function Keys.........................43
     Disabling the JiffyDOS Commands................................43
     Re-Enabling the JiffyDOS Commands..............................44
Special Command Features............................................44
     Using the Commands in Direct and Program Modes.................44
     Drive Specification............................................45
Enhancements to the DOS Wedge.......................................45
     Command Chaining...............................................45
     String Variables...............................................45
     Default Device Override........................................46
Addendum............................................................47
Command Summary.....................................................48

Guarantee and Warrenty..............................................50
 *np
                           Section 1
                         Introduction

Getting Started
----------------------------------------------------------------------
When you first receive your JiffyDOS system, you will probably be anxious to install it and to start taking advantage of the speed increases that JiffyDOS provides.  Before beginning, however, please note that installing JiffyDOS requires the partial disassembly of your computer and disk drive(s).  While this does not require a knowledge of electronics, it does require some manual dexterity to perform.  Read through the installation instructioons carefully before starting.  If you do not feel confident about installing JiffyDOS yourself, refer installation to a qualified technician, or take advantage of Creative Micro Design's installation service.

Also, please be aware that installing JiffyDOS will void any factory warrenty applicable to your computer or disk drive.  If you are concerned about voiding your warrenty, you may want to delay installing JiffyDOS until your warrenty period has expired (Commodore normally warrents their equipment for a period of 90 days).

After you have installed JiffyDOS

After you have installed JiffyDOS, please take the time to become familiar with this manual.  It describes the many commands and features of your JiffyDOS system, and gives you instructions on how to use them.  You will also find information that will help you get the most performance out of JiffyDOS.  If you experience any problems when using JiffyDOS, please check the manual - it may provide you with the information that you need to solve the problem.

Getting Help
----------------------------------------------------------------------
If you run into any problems or have any questions about the installation or operation of JiffyDOS, please feel free to contact Creative Micro Designs.  We will be glad to assist in any way we can.  Our address and phone number are listed below:

     Creative Micro Designs, Inc.
     P. O. Box 789
     Wilbraham, MA   01095
     (413)  525-0023

Installation Service

Creative Micro Designs offers a JiffyDOS installation service.  If you would like us to install JiffyDOS in your computer and/or disk drive, please contact us for information and prices.

What this Manual Includes
----------------------------------------------------------------------
This manual gives you complete instructions on how to use your JiffyDOS system.

Section 2, ''What is JiffyDOS?'', describes the performance and other features of JiffyDOS.

Section 3, ''Using JiffyDOS'', gives you instructions on how to enable and disable JiffyDOS, how to use the JiffyDOS function keys, how to control listings and how to get the most performance out of your system.

Section 4, ''The JiffyDOS Commands'', provides a description of each JiffyDOS command.

The JiffyDOS guarantee and Warranty are included at the back of this manual.

                            SECTION 2
                        WHAT IS JIFFYDOS?

JiffyDOS is an enhanced Disk Operating System (DOS) for Commodore C-64, SX-64, and C-128 computers.  Programmed onto ROMs that replace the Kernal ROM(s) in your computer and the DOS ROM in your disk drive, JiffyDOS provides the speed, commands and convenience missing on stock systems.  Because it is ROM-based, JiffyDOS becomes an integral part of your system, and is able to provide performance without the compatibility problems of Cartridges and other speed-enhancement systems.

Features
----------------------------------------------------------------------
Uses no ports or cabling

JiffyDOS installs without any extra cabling between your computer and disk drive(s), and does not tie up the Cartridge, User or Cassette ports.  This enables compatibility with all hardware devices (such as modems, memory expansions, etc.), and gives JiffyDOS an advantage over cartridge speedups and other hardware upgrades (RapiDOS, 1541 Flash!, DigiDOS, Dolphin DOS) which require extra cabling that plugs into one of the ports on your computer.

Built-In DOS Wedge Commands

JiffyDOS includes a complete, built-in implementation of the Commodore DOS 5.1 Wedge command set.  The DOS Wedge provides simple, easy-to-learn commands that eliminate the need to type complicated instructions when you need to perform common disk operations such as scratching files and formatting disks.  The JiffyDOS version of the Wedge also includes a series of enhancements that make it easier to use the commands within BASIC programs.

Additional JiffyDOS Commands

In addition to the standard DOS Wedge, JifyDOS includes a number of special commands that make using your computer even easier.  The JifyDOS commands all use the familiar DOS Wedge syntax, and enable you to perform functions such as disabling the head rattle (bump) on 1541's locking and unlocking files, listing files directly from disk, ''un-NEWing'' BASIC programs and dumping the screen to a printer.

Convenience features

JiffyDOS provides a full compliment of convenience features that enable you to list the directory without disturbing memory; to load and run the first program on disk; and to pause, inspect and restart BASIC of JiffyDOS listings.  In addition, JiffyDOS includes a full set of function key definitions that work along with the directory listing to eliminate the need to type lengthy filenames when loading, saving, or scratching files.

Does not bypass error checking

All JiffyDOS operations retain the built-in DOS error checking and correction routines that are a necessary part of any reliable data storage system.  While other speedup systems and utilities (i.e. the ones boasting 10-second formats) bypass these routines, JiffyDOS provides speed without jeopardizing the integrity of your data.

Incorporates the latest Commodore upgrades

When you purchase JiffyDOS, the ROMs you receive have been programmed to include the latest Commodore upgrades.  The JiffyDOS ROM for the 1571 eliminates bugs affecting Relative files, drive initialization, etc. and has also been modified to solve the problems with disk backup utilities (Fast Hack-Em, Copy II-64/128, etc.) caused by the Commodore upgrade.  The JiffyDOS Kernal ROM for the C-64 is based on the latest version, as are the 64- and 128-mode Kernal ROMs for the C-128.

Performance
----------------------------------------------------------------------
Speeds up all disk operations

JiffyDOS has been designed to speed up all operations on 1541, 1541 compatible, 1571 and 1581 disk drives.  This includes the initial loading of all types of programs (including copy-protected software), saving, reading and writing files from within programs, autobooting (C-128 in 128 mode), scratching, validating, and formatting (1541 drives).  JiffyDOS/128 speeds up disk operations in both 64 and 128 modes and is able to speed up the already-quick 128-mode operation of 1571 and 1581 drives.

Works within all types of software

Because of its ROM-based design, JiffyDOS is able to work from within all types of software to increase disk-access speed when you need it the most.  Wordprocessors, databases, spreadsheets, programming languages, MIDI software and games all benefit from the built-in speed provided by JiffyDOS.  Since JiffyDOS requires no extra RAM in your computer or disk drive and does not alter vectors, it can speed up the operation of all software that relies on the disk-access routines built into the Kernal ROM.

Speeds up access of SEQ, REL, & USR files

Another important feature of JiffyDOS is its ability to speed up the access of all types of files.  Program (PRG), Sequential (SEQ), Relative (REL) and User (USR) files can all be accessed faster on JiffyDOS systems.  This makes JiffyDOS effective with software that uses these file types, and provides an advantage over cartridge speedup products which improve performance only with PRG files.

Speed comparisons

The following tables illustrate the speed increases that can be obtained with JiffyDOS.  Please note that the times shown are rounded off to the nearest second, and do not take into account the disk spin-up delay (approx. 1/2 second) and the time required for directory searching (which varies in relation to the size of the particular directory).  Other factors may also influence the results that you obtain on your system.  Refer to Section 3 for more information on these factors and for ways to obtain maximum performance when using JifyDOS.

C-64, SX-64, C-128 in 64 Mode
-------------------------------------------------------------------------------
/                    /      1541        /      1571        /      1581        /
/                    /------------------/------------------/------------------/
/Disk Operation      / Stock / JiffyDOS / Stock / JiffyDOS / Stock / JiffyDOS /
/--------------------/-------/----------/-------/----------/-------/----------/
/Load 202-block      /       /          /       /          /       /          /
/program (PRG file)  /  124  /    12    /  124  /     9    /  102  /     8    /
/--------------------/-------/----------/-------/----------/-------/----------/
/Save 100-block      /       /          /       /          /       /          /
/program (PRG file)  /   75  /    24    /   75  /    20    /   40  /    15    /
/--------------------/-------/----------/-------/----------/-------/----------/
/Read 125-block      /       /          /       /          /       /          /
/SEQ or USR file     /   84  /    15    /   84  /    13    /   63  /     9    /
/--------------------/-------/----------/-------/----------/-------/----------/
/Write 100-block     /       /          /       /          /       /          /
/SEQ or USR file     /   81  /    27    /   81  /    24    /   44  /    17    /
/--------------------/-------/----------/-------/----------/-------/----------/
/Read 64 154-byte    /       /          /       /          /       /          /
/REL records         /   40  /    14    /   40  /    14    /   37  /    10    /
/--------------------/-------/----------/-------/----------/-------/----------/
/Write one 154-byte  /       /          /       /          /       /          /
/REL records         / .350  /  .125    / .350  /  .120    / .325  /  .110    /
/--------------------/-------/----------/-------/----------/-------/----------/
/Read/Write 16K on   /       /          /       /          /       /          /
/command channel     /   47  /     9    /   47  /     9    /   47  /     9    /
/--------------------/-------/----------/-------/----------/-------/----------/

C-128 in 128 Mode
-------------------------------------------------------------------------------
/                    /      1541        /      1571        /      1581        /
/                    /------------------/------------------/------------------/
/Disk Operation      / Stock / JiffyDOS / Stock / JiffyDOS / Stock / JiffyDOS /
/--------------------/-------/----------/-------/----------/-------/----------/
/Load 202-block      /       /          /       /          /       /          /
/program (PRG file)  /  124  /    12    /   14  /     9    /   12  /     8    /
/--------------------/-------/----------/-------/----------/-------/----------/
/Save 100-block      /       /          /       /          /       /          /
/program (PRG file)  /   75  /    24    /   48  /    25    /   26  /    14    /
/--------------------/-------/----------/-------/----------/-------/----------/
/Read 125-block      /       /          /       /          /       /          /
/SEQ or USR file     /   84  /    15    /   31  /    12    /   20  /    10    /
/--------------------/-------/----------/-------/----------/-------/----------/
/Write 100-block     /       /          /       /          /       /          /
/SEQ or USR file     /   81  /    27    /   48  /    33    /   20  /    11    /
/--------------------/-------/----------/-------/----------/-------/----------/
/Read 64 154-byte    /       /          /       /          /       /          /
/REL records         /   40  /    14    /   21  /    14    /   17  /    10    /
/--------------------/-------/----------/-------/----------/-------/----------/
/Autoboot 202-block  /       /          /       /          /       /          /
/program             /  125  /    13    /   54  /    10    /   13  /     9    /
/--------------------/-------/----------/-------/----------/-------/----------/
/Read/Write 16K on   /       /          /       /          /       /          /
/command channel     /   47  /    10    /   10  /     6    /   10  /     6    /
/--------------------/-------/----------/-------/----------/-------/----------/

Compatibility
----------------------------------------------------------------------
Works with virtually all software

We designed JiffyDOS to be fast.-.but not at the expense of compatibility.  As a result, JiffyDOS will load and operate with virtually all software of every type (including copy-protected commercial programs).  This includes programs that cannot be loaded by other speedup products such as cartridges, software-based ''turbo'' loaders, and other hardware-based systems.  In addition, JiffyDOS is compatible with programs that utilize their own fast-access routines (such as GEOS) and will work with the non-standard file formats created by programs such as the VORPAL utility kit.

RAMDOS compatibility

JiffyDOS commands are compatible with Commodore's RAMDOS for the 1700, 1750, and 1764 RAM expansion units (REU's), as well as being compatible with the RAM operating system used by CMD in the RAMLink RAM expansion interface.

Compatible with all hardware

Because it does not use any ports, JiffyDOS can work in conjunction with all hardware devices available for C-64's and C-128's, including modems, RAM expansions, MIDI interfaces, hard disk drives, etc.  JiffyDOS systems are also compatible with all serial bus devices (non-JiffyDOS disk drives, printers, printer interfaces, etc.).  JiffyDOS can be installed on disk drives regardless of device number, and devices numbers can be changed on JiffyDOS drives via software or hardware with no problems.  In addition, JiffyDOS-equipped disk drives can be used with stock C-64 and C-128 computers, if necessary.

Uses stock disk and file formats

All files written under JiffyDOS are identical to standard Commodore files.  Disks formatted on JiffyDOS systems are identical to those formatted on stock systems.  This means that you will have no problems using the disks, programs and files you create with JiffyDOS on stock systems (and vice-versa).

Can be completely switched out

In the event that a program will not load or operate properly with JiffyDOS (this should be a rare occurance - we know of only a few heavily copy-protected games that will not load), you can switch your system back to a completely stock version with the flip of a switch.  As an added advantage, you can use the switching system to switch JiffyDOS in or out with power on.

Available for all 64's, 128's and virtually all drives

JiffyDOS systems are available for the following computers and disk drives:

     C-64, 64''C'', SX-64, C-128, C-128D

     1541, 1541''C'', 1541-II, 1571, 1581
     FSD-1, FSD-2, Excelerator+, Excel 2001, OC-118
     MSD-1, MSD-2
     Enhancer 2000
     BCD/5.25, BCD/128
     RF501C, RF512C, FD-168, SW71
     Indus GT
     CSD-1

JiffyDOS can be ordered for any combination of the above computers and disk drives.  Additional drive ROMs can be ordered if you wish to speed up second, third or fourth drives.  JiffyDOS allows the use of multiple dissimilar drives (i.e. 1541, 1571, 1581) whether or not they are equipped with JiffyDOS ROMs.  JiffyDOS-equipped disk drives can be used interchangeably on different JiffyDOS-equipped computers (for example, a C-64 and C-128), or with stock computers.  Contact Creative Micro Designs if you are interested in expanding your JiffyDOS system.

Compatibility Guarantee

Because of our confidence in the compatibility of JiffyDOS, we back our product with a 30-day, Money-Back Compatability Guarantee.  The JiffyDOS guarantee is simple:  If you are dissatisfied because JiffyDOS is not compatible with any of the hardware or software that you own, simply return the unit unmodified and in good condition within 30 days of purchase for a complete refund.  This offer is only valid with units purchased directly from CMD.  See the back of this manual for a complete description of the JiffyDOS Guarantee.

                                SECTION 3
                             USING JIFFYDOS

ROM Switching
----------------------------------------------------------------------
JiffyDOS enables your computer and disk drive(s) to be switched back to stock mode, if necessary.  You will probably be able to have JiffyDOS selected all of the time.  However, in rare cases, your system may have to be switched back to stock mode to allow a program to load or operate properly.

C-64, SX-64, and C-128

The normal procedure for switching Kernal selections on the C-64, SX-64, and C-128 is to first turn your computer OFF, flip the selector switch to the desired position and then power the computer back ON.  After your computer is powered back on, the sign-on screen will indicate which Kernal has been selected.  If the JiffyDOS Kernal is selected, the sign-on screen will read:

                  JiffyDOS  V6.01     (C) 1989  CMD

This may differ slightly if your version of JiffyDOS is not version 6.01.  If the stock Kernal routines have been selected, the normal BASIC sign-on screen will be displayed.

1541 and compatibles

The normal procedure for switching JiffyDOS in or out on 1541 and compatible drives is to power the drive off, set the selector switch to the desired position and then power the drive back ON.  (Note:  The SX-64 does not have a seperate drive selector switch.)  Reading the disk drive error channel immediately after power-up will indicate which ROM selection has been made.  If JiffyDOS has been selected, the message is:

              73, JiffyDOS  5.0   1541, 00, 00

(Note:  The JiffyDOS version 6 drive ROMs have not been changed since version 5, therefore the actual version number displayed by the drive ROM is version 5).  If the stock ROM routines have been selected, the message is:

              73, CBM  DOS  V2.6  1541, 00, 00

1571 and 1581

On 1571 and 1581 drives equipped with JiffyDOS, a software switching scheme is used to select between JiffyDOS and the stock DOS.  With JiffyDOS installed, the drives sense whether the computer they are connected to is in stock or JiffyDOS mode and subsequently select the corresponding DOS routines automatically.  No manual switching is required.

Switching ROMs with power on

JiffyDOS has been designed to allow ROM switching while your system is powered on.  This is especially useful in cases where a heavily copy-protected program will not load with JiffyDOS selected, but will perform high-speed drive accesses properly if JiffyDOS is switched in once the program is up and running.

Precautions

The only precaution necessary for switching ROM selections on your computer or disk drive with power on is to be sure that no disk accesses are taking place at the time (switching while a disk drive is being accessed will cause the system to hang up).  Take note, however, that switching Kernal ROM selections on your computer while running a program may not be 100% reliable - that is, the program running at the time may crash when the switch is toggled or may hang up when a device access is attempted (some programs will respond better than others).

Switching to the Stock Kernal while in BASIC

To switch from the JiffyDOS Kernal to the stock Kernal while your computer is in BASIC direct mode, first disable the JiffyDOS commands by using the @Q command and then flip the Kernal Selector Switch to the stock position.

Switching to the JiffyDOS Kernal while in BASIC

To switch from the stock Kernal to the JiffyDOS Kernal while your computer is in BASIC direct mode, first flip the Kernal Selector Switch to the JifyDOS position and then type in one of the following commands:

  SYS 58551     (64 mode)

  SYS 65137    (128 mode)

Using a Tape Drive with JiffyDOS
----------------------------------------------------------------------
It is not possible to use a tape drive (Commodore DATASETTE, etc) while the JiffyDOS Kernal is selected.  If tape access is attempted, an ILLEGAL DEVICE NUMBER ERROR will occur.

To use a tape drive with JiffyDOS, select the stock Commodore Kernal ROM routines first by using the Kernal Selector Switch.  See ''ROM Switching'' earlier in this section for instructions.

Function Key Definitions
----------------------------------------------------------------------
JiffyDOS offers the convenience of function keys defined with JiffyDOS Wedge commands and BASIC keywords.  The function key definitions are active only in BASIC direct mode and are automatically disabled when a BASIC or ML program is run, in order to avoid conflict with any program-defined function key assignments.  The JiffyDOS function key definitions are:

  f1 = @$:* <RETURN>     Display the directory
  f3 = /                 Load a BASIC program
  f5 = ~                 Load and run a BASIC program
  f7 = %                 Load an ML program

  f2 = @D                List a BASIC program from disk
  f4 = @T                List an ASCII (text) file from disk
  f6 = <-                Save a BASIC program
  f8 = @  ''S:           Scratch a file

Using the function keys with the directory listing

The JiffyDOS function key definitions have been designed to work along with the filenames in the directory listing.  Once the directory has been listed, the cursor can be moved to the line of the desired filename, the appropriate function key can be pressed, and then RETURN can be pressed when it is OK to proceed with the command.

Using the JiffyDOS function keys with the directory listing eliminates the possibility of filename misspellings.  And, there is no need to enter a colon (:) after the filename or erase the filetype characters manually in order to avoid a syntax error.  After the function key has been pressed, the filename can be altered if desired.

Disabling the function keys

The JiffyDOS @F command may be used to disable the function key definitions in 64 mode.  In 128 mode this command will switch the function keys from the JiffyDOS definitions to the standard 128 definitions.  Refer to Section 4, ''The JiffyDOS Commands'', for a complete description of the @F command.

Re-enabling the JiffyDOS function keys

The following commands are used to re-enable the standard JiffyDOS function key definitions.  For more information see Section 4 of this manual.

  SYS 58551      (64 mode)

  SYS 65137     (128 mode)

Reprogrammable function keys (64 mode)

The function keys (C-64 or C-128 in 64 mode) can be redefined by using a BASIC program.  The following program redefines the keys with the strings assigned to variables F1$ through F8$ (change these strings to the new definitions you want to assign).  Please note that the keys must be assigned in the order shown in line 55 (f1, f3, f5, f7, f2, f4, f6, f8) and each definition must end with a CHR$(0).

15 F1$=''@$:*''+CHR$(13)+CHR$(0)
20 F2$=''@D''+CHR$(0)
25 F3$=''/''+CHR$(0)
30 F4$=''@T''+CHR$(0)
35 F5$=''~''+CHR$(0)
40 F6$=''<-''+CHR$(0)
45 F7$=''%''+CHR$(0)
50 F8$=''@  ''+CHR$(34)+''S:''+CHR$(0)
55 F$=F1$+F3$+F5$+F7$+F2$+F4$+F6$+F8$
60 BUF=820
65 FOR I=1 TO LEN(F$)
70 POKE(BUF+I-1),ASC(MID$(F$,I,1)):NEXT I
75 POKE 176,BUF-(256*(INT(BUF/256)))
80 POKE 177,INT(BUF/256):POKE 155,0

The variable ''BUF'' points to the RAM area where the new definitions will be stored (Address 820 is the Tape Buffer).  This can be changed to point to any safe RAM area except for the areas under the BASIC and Kernal ROMs.

Listing Freeze
----------------------------------------------------------------------
JiffyDOS features an enhanced listing freeze method that differs from V5.0.  The listing freeze is especially helpful when you are scanning a long BASIC program or a listing produced by the @$ (directory), @D (list BASIC program), or @T (list ASCII file) commands.  In addition, the listing freeze will work from within many commercial programs.

Scanning a listing

You can easily scan a listing by using the <CONTROL> key.  Holding down <CONTROL> will stop the listing from scrolling off the screen.  When you want the listing to start scrolling again, release the <CONTROL> key.  While you are holding down the <CONTROL> key, you can also freeze or single-step the listing (see below).

Freezing a listing

To freeze a listing, press <CONTROL>+<S> (Press ''S'' while holding down the <CONTROL> key).  This will stop the listing from scrolling and allow you to take your hands off the keyboard.  To restart the listing, press any key except <CONTROL>, <RUN/STOP>, <SHIFT>, or the <COMMODORE> key.

Single-stepping a listing

With JiffyDOS you can ''single-step'' a listing.  Single-stepping enables you to scroll through a listing one line at a time.  To single-step, first stop the listing by holding down <CONTROL>.  Then, while continually holding down the <CONTROL> key, alternately press the ''S'' and ''W'' keys.  Each time you press ''W'' a new line will appear on the screen.  You can restart the scrolling by releasing the <CONTROL> key after you have pressed ''W''.

Ending a listing

JiffyDOS enables you to end (break off) any JiffyDOS or BASIC listing by pressing and holding <RUN/STOP>.  You can press <RUN/STOP> while a listing is scrolling, or while it is frozen after <CONTROL>+<S> has been pressed.  Note:  Pressing <RUN/STOP> will work well with BASIC and JiffyDOS listings, but will not necessarily break off the listings that occur within commercial programs.

Getting Maximum Performance
----------------------------------------------------------------------
As a general rule (with 1541, 1571, and compatible drives only), programs and files saved with JiffyDOS will load faster than programs and files saved on stock systems (or with JiffyDOS switched out).  In some cases, re-saved files can be loaded up to 3 times faster.  With programs (or files) that already load quickly with the 1571 in 128 mode, re-saving files may be the only way to obtain a discernable speed increase.

Re-saving files under JiffyDOS does not alter the file's format or contents in any way - it merely rearranges the data more efficiently on disk, which allows JiffyDOS to find each block (sector) more quickly.  Re-saved files remain compatible with stock Commodore systems.

Re-writing files

To get the maximum possible speed increase when loading files from within other programs (i.e., wordprocessors, MIDI sequencers, etc.), start up the program, load in the desired file, and then re-save it.  For example, to increase the load speed of a MIDI sequencer file, load your MIDI sequencing program with JiffyDOS enabled and then load the file you want to speed up into the sequencer.  After the file has been loaded, simply save it back to disk.  In many cases, this procedure can double the speed at which files can be loaded.  Another method is to use the JiffyDOS file copier to re-write files.  See the section titled ''The JiffyDOS File Copier'' for more information.

Changing the Sector Interleave

JiffyDOS also enables you to easily change the sector interleave on 1541 and 1571 drives.  This feature makes it possible to increase the disk-access speed of particular programs that JiffyDOS seems to have little effect on.  In some cases, changing the sector interleave may be the only way to increase disk-access performance - especially when a 1571 drive is used with a C-128 in 128 mode.  For example, when a standard interleave is used, JiffyDOS does little to speed up Paperclip III (1571 in 128 mode).  However, if the sector interleave is changed to a value of 7, file-access speed is doubled.  See the section titled ''Setting the Sector Interleave'' for more information.

===============================================================================

The JiffyDOS File Copier
----------------------------------------------------------------------
JiffyDOS includes a built-in two-drive file copier that makes it easy to backup valuable data files, to copy files between 1541, 1571 and 1581 drives, and to copy files to and from RAM expansion units running under Commodore's RAMDOS.  Although the file copier built into JiffyDOS is not the fastest one in existence, it has the following advantages over stand-alone copy utilities:

.  The JiffyDOS file copier is built-in, which enables you to copy files without the hassle of loading a stand-alone utility.

.  Copies PRG, SEQ, REL and most USR files.

.  Saves time and trouble by automatically replacing existing files of the same name on the destination disk.  (The file is first scratched, then written.  Save-with-Replace is not used).

.  Unlike most utilities, the JiffyDOS file copier uses the standard JiffyDOS interleave (or the interleave specified by the @G command), which enables you to maximize the performance of the files that you copy.

.  Because the JiffyDOS copier does not rely on drive-specific routines, it can also be used to transfer non-copy-protected programs or files between any two Commodore or Commodore-compatible disk drives, including those that are not equipped with JiffyDOS.  This makes it easy to move files between 1541, 1571, 1581 and compatible drives.

.  The JiffyDOS file copier is compatible with Commodore's RAMDOS, which makes it ideal for transferring files to and from RAM Expansion Units.

.  Files can be copied with JiffyDOS without disturbing programs currently in memory.

.  The file copier commands can be used within BASIC programs, enabling you to write your own custom copy routines.

.  The file copier can be used to change the file type of PRG, SEQ, and USR files.

Re-Saving files

As described in the User's Manual, using a file copy utility (such as the JiffyDOS file copier) to re-save files created by the stock DOS is one of the best wys to increase performance when using 1541 and 1571 disk drives.  In fact, with programs or files that already load quickly on a 1571 in 128 mode, re-saving may be the only way to obtain a discernable speed increase.  The following types of files can benefit from being re-saved (copied) using the JiffyDOS file copier:

.  Any file written under the stock Commodore DOS.

.  Any file originally written on a 1541 drive now used on a 1571 drive.

.  Any file originally written on a 1571 drive now used on a 1541 drive.

File copier commands

The following JiffyDOS commands provide you with the ability to copy files.  Although only four commands are involved, they must be used properly in order to produce the desired results.  Before copying any files, you should understand the function and application of each command.  (For detailed information on each individual command, see the section covering JiffyDOS commands).

@Xdev#                 Sets the destination drive for copying.

*''filename'' type     Copies filename to the destination drive.

<CONTROL>+<A>          Toggles the copy flag on/off for all files in the directory listing.

<CONTROL>+<W>          Toggles the copy flag on/off for a single file in the directory listing.

How to copy files with JiffyDOS

The following procedures describe the steps you will need to follow when copying files with JiffyDOS.  Before using the JiffyDOS file copier for the first time, read through the procedure carefully.  It is also a good idea to experiment with non-valuable disks until you are sure you can make successful copies.

Copying a single file

If you need to copy one or two files, or you do not want to disturb a BASIC program currently in memory, use the following procedure:

1.  Place the source disk in the drive that you want to copy from.  Place the destination disk in the drive that you want to copy to.  Note:  No action is necessary at this point for a source or destination that is an REU.

2.  Use the @X command to tell JiffyDOS which drive is the destination drive.  For example, enter @X9 if the destination drive is to be device 9.

3.  Use the @# or <CONTROL>+<D> commands to set the default device to the source drive.  For example, enter @#8 if the source drive is to be device 8.

4.  List the directory from the source drive.  You can enter @$ or press f1.  Stop the listing (press RUN/STOP) when you see the file(s) that you want to copy appear on the screen.

5.  Cursor up to the file that you want to copy.  Keep the cursor on the left side of the screen.  Press the asterisk (*) key (the asterisk should appear in the leftmost column on the same line as the file you want to copy).

6.  Press <RETURN>.  The file will be copied from the source drive to the destination drive.

7.  Repeat Steps 4-6 for any additional files that you want to copy.

Copying multiple files

If you need to copy more than a few files, use the following procedure:

1.  Follow Steps 1-3 above under ''Copying a single file''.

2.  Load the directory from the source drive by entering /$.  Note:  This will overwrite any BASIC program currently in memory.

/-----------------------------------------------------------------------------/
/IMPORTANT:  Make sure you load the directory with the /$ command.  DO NOT use/
/the @$ command.                                                              /
/-----------------------------------------------------------------------------/

List the directory (type LIST).  If the directory listing is longer than one screen, you can use the JiffyDOS ''Listing Freeze'' feature to easily locate the desired file(s).  Next, use the <CONTROL>+<A> and/or <CONTROL>+<W> commands to select the files that you want to copy (see below).  The asterisk (*) indicates that the file will be copied.

Pressing <CONTROL>+<A> will togle the copy flag on/off for all files in the listing, and then re-display the entire list.

Pressing <CONTROL>+<W> will toggle the copy flag on/off for a single file.  The cursor must be on the same line as the file that you wish to toggle, and must be to the far left of the screen.

/-----------------------------------------------------------------------------/
/IMPORTANT:  DO NOT press <RETURN> when the cursor is on the same line as one /
/of the filenames.  This will result in a corrupted file list, and will       /
/require that you reload the directory from disk.                             /
/-----------------------------------------------------------------------------/

3.  Enter RUN.  The file copier will start working.  When all files have been copied, the cursor will return to the screen.

Using the file copier commands in BASIC programs

The following two examples illustrate how to use the file copier commands within a BASIC program.

Example 1:

100 @#8                           Set the source drive to device 8
110 @X10                          Set the destination to device 10
120 *''JIFFYMON''PRG              Copy PRG file ''JIFFYMON''
130 *''TAX DATA''SEQ              and SEQ file ''TAX DATA''
140 END                           from drive 8 to drive 10

Example 2:

100 INPUT''SOURCE DRIVE'';S       Input the source drive
110 INPUT''DESTINATION'';D        Input the destination drive
120 @#S : @XD                     Set the source and destination
140 INPUT''FILENAME'';F$          Input the filename
150 INPUT''TYPE (P/S/R/U)'';T$    Input the filetype
160 IF T$=''P'' THEN *F$ PRG      If file is PRG, copy it as such
170 IF T$=''S'' THEN *F$ SEQ      If file is SEQ, copy it as such
180 IF T$=''R'' THEN *F$ REL      If file is REL, copy it as such
190 IF T$=''U'' THEN *F$ USR      If file is USR, copy it as such

Changing the filetype of PRG, SEQ and USR files

The JiffyDOS file copier also enables you to change the filetype of PRG, SEQ and USR files.  (Note:  You cannot change a PRG, SEQ or USR file into a REL file, and you cannot change a REL file into any other type of file.)  Use the following procedure to change the filetype of a PRG, SEQ or USR file:

1.  Follow Steps 1-4 under ''Copying a single file''.

2.  Cursor up to the file that you wish to change.  Make sure the cursor is on the left-hand edge of the screen.  Press the asterisk (*) key.  DO NOT press <RETURN> yet.

3.  Stay on the same line and cursor over to the filetype (PRG, SEQ, USR).  Type the new filetype that you want over the one displayed on the screen, and press <RETURN>.  The file will be copied to the destination drive and will be assigned the new filetype.

Changing the filetype can also be done by using the JiffyDOS commands within a BASIC program.  See below:

100 INPUT''SOURCE DRIVE'';S       Input the source drive
110 INPUT''DESTINATION'';D        Input the destination drive
120 @#S : @XD                     Set the source and destination
140 INPUT''FILE TO CHANGE'';F$    Input the filename
150 INPUT''NEW TYPE (P/S/U)'';T$  Input the new filetype
160 IF T$=''P'' THEN *F$ PRG      Make it a PRG file
170 IF T$=''S'' THEN *F$ SEQ      Make it a SEQ file
180 IF T$=''U'' THEN *F$ USR      Make it a USR file

Additional notes about the JiffyDOS file copier

.  Whenever you copy files using the method shown above under ''Copying multiple files'' make sure that you load the directory by using the /$ command.  DO NOT use the @$ command.  The <CONTROL>+<A> and <CONTROL>+<W> commands will not work properly if the directory has been loaded using @$.

.  JiffyDOS cannot copy non-standard files such as 1581 ''CBM'' partition files and the special USR files created by GEOS.

.  Changing a PRG file to a SEQ or USR file will not remove the first two bytes in the file (the load address).  Likewise, changing a SEQ or USR file to a PRG file will not add two load address bytes to the beginning of the file.

.  When JiffyDOS starts to copy a REL file, there may be a significant delay (up to about 40 sec.) while JifyDOS interrogates the source drive to determine the record size of the particular REL file.  While this operation is being carried out, the destination drive will sit inactive.  Do not assume that this period of inactivity means the system has ''hung up''.

.  After a REL file is copied, the error light will always be flashing on the source drive.  This does not indicate that an error has occurred during copying.

Setting the Sector Interleave
----------------------------------------------------------------------
As mentioned earlier, JiffyDOS enables you to optimize performance with some software through changing the sector interleave.  The @G command is used to ease selection of the required interleave.  For specific information on the @G command, see the section covering JifyDOS commands.

Understanding sector interleave

Each time the DOS writes a file to disk, it uses a sector interleave value to lay out the physical distance (number of sectors skipped) between consecutive sectors (blocks) of a file.  After a file is written, its interleave can greatly affect the speed at which the file can be read.  If the space between consecutive sectors (the interleave) is too small, the DOS cannot read the next block in the file without having to wait for the disk to spin one additional revolution (one disk revolution takes 0.2 seconds).  If the interleave is larger that it has to be, the DOS also spends unnecessary idle time waiting for the next sector to reach the read/write head.

Because JiffyDOS can access and transfer data faster than the stock DOS, it uses special interleave values designed to reduce access delays to a minimum.  For PRG files, JiffyDOS uses an interleave that provides the fastest possible access when the Kernal Load routine is used.  For SEQ, REL and USR files, JiffyDOS uses a compromise interleave value designed to perform well in most cases.  On the other hand, the stock Commodore DOS uses the same interleave value for all file types.  Both JiffyDOS and stock interleave values for 1541 and 1571 drives are listed in the table below:

              JiffyDOS and Stock interleave values
        /-----------------------/----------------------/
        /  JiffyDOS Interleave  /   Stock Interleave   /
/-------/-----/-----------------/----------------------/
/ Drive / PRG / SEQ, REL, & USR / PRG, SEQ, REL, & USR /
/-------/-----/-----------------/----------------------/
/ 1541  /  6  /      10-12*     /          10          /
/-------/-----/-----------------/----------------------/
/ 1571  /  4  /       8-10*     /           6          /
/-------/-----/-----------------/----------------------/
  * Depends upon track zone

The standard JiffyDOS interleave values work well in most cases.  However, because of the many different ways that programs load and access data, there are times when using a different interleave value is the only way to provide maximum performance.

When to adjust the interleave

In general, if your JiffyDOS system is already performing close to its maximum capability (within a few seconds of the times shown in the performance charts in Section 2), then changing the interleave will do little to improve performance.  However, if you notice that a particular program seems to load or access data two to three times slower than is possible with JiffyDOS, then changing the interleave and resaving the program and/or data files could provide the speed you are looking for.

Files that can benefit from a new interleave

1.  Any program (PRG-type) that is not loaded by the Kernal Load routine.  Instead of using the Kernal Load routine, many commercial programs incorporate a loader that reads in sections of the program byte-by-byte.

2.  Any PRG data file not accessed by the Kernal Load routine.  Note:  most programs that use PRG data files do not use the Kernal Load routine to access the data in the PRG file.

3.  Any SEQ, REL, or USR file that is read by a slower-than-normal access routine.  Unfortunately, many programmers do not take the time to optimize their file-access code (maybe because the stock Commodore DOS is so slow), or use a compiled language that is inefficient to begin with (like compiled BASIC).  As a result, some commercial programs suffer from lackluster file-access performance, even after JiffyDOS is installed.

Determining the optimum interleave

To determine the optimum interleave for a particular program or data file, follow the procedure outlined below:

1.  First, be sure that you have read the information above so that you understand which programs and files can benefit from an altered interleave.

2.  You will need two disk drives so that the necessary files can be copied from the original disk to the new disk.  The drive you will copy from is the source drive, the drive you will copy to is the destination drive.

3.  Determine a starting interleave value.  On 1541 drives, use 6.  On 1571 drives, use 4.

4.  Make a copy of the original disk.  If it is a program disk, the copy should be a nibble backup, fast copy or parameter copy that is an exact duplicate of the original with the same sector interleave.  If it is a data disk, it should contain the necessary system files, print drivers, etc. (if any), but no actual data files.

5.  Insert the copy of the original disk into the destination drive.

6.  Insert the original disk into the source drive.

7.  Set the default to the destination drive.  Use the @# or <CONTROL>+<D> commands.  For example, enter @#9 if the destination drive is device #9.

8.  Enter the desired interleave value by using the @G command.  For example, enter @G5 to set the interleave to 5.

9.  Set the default to the source drive.  Use the @# or <CONTROL>+<D> commands.  For example, enter @#8 if the source drive is device #8.

10. Load the directory from the source drive by entering /$.  List the directory and then use the <CONTROL>+<A> and/or <CONTROL>+<W> commands to select the program(s) or data file(s) that will be getting the new interleave (see the section covering the JiffyDOS file copier for more information on the <CONTROL>+<A> and <CONTROL>+<W> commands).

/-----------------------------------------------------------------------------/
/IMPORTANT:  Make sure you load the directory with the /$ command.  DO NOT use/
/the @$ command.                                                              /
/-----------------------------------------------------------------------------/

11. Tell JiffyDOS which drive is the destination drive by using the @X command.  For example, enter @X9 if the destination drive is device #9.

12. Copy the files from the source drive to the destination drive by entering RUN.

13. Test the destination disk to see if the new interleave has helped performance.  If the disk is a program disk, load the program.  If it is a data disk, load and run the program that will access the data, and then load the data file(s).  Time the disk accesses and see if the new interleave has helped.  Keep a record of the results.

14. Return to step 5 and increase the interleave value by one.  Continue this procedure until you have tried all interleave values up to and including 16.

15. Compare the timing results you recorded in step 13 to determine the interleave value that provides the best performance.

16. Re-Copy the program(s) or data file(s) using the optimum interleave value.  Follow Steps 5 through 12.

17. Before continuing, make sure the standard interleave is reinstated on all drives.  The safest way to do this is to completely reset your system (C64 users should power down, then up; C-128 users can press the reset button).

18. Carefully read the following procedure concerning data files that require an altered interleave.

Data files which require an altered interleave

Each time you are planning to work with data files that require an altered interleave, follow the prcedure below:

1.  Before loading and running the program that will access or create the data file(s), set the default to the drive that will contain the data disk.  Use the @# or <CONTROL>+<D> commands.  For example, enter @#9 if the data drive is device #9.

2. Set the interleave to the optimum value for the particular program.  For example, enter @G9 if the optimum value is 9.  Remember, do this for 1541 and 1571 drives only - altering the interleave on 1581 drives will have no effect on performance.

3. If more than one drive will be accessing the data, Repeat Steps 1 and 2 for each of the additional data drives.

4.  Reset the default to the drive that the program will load from.  For example, enter @#8 if the program will be loaded from device #8.

5.  Load and run the program that will access the data.

6.  Read, write and create data files in the normal fashion from within the program.

7.  After you have finished working with the program, make sure that the standard interleave is reinstated on all drives (refer to Step 17 in the previous procedure).

Important points to remember about the interleave

.  Adjusting the interleave is only effective on 1541 and 1571 drives - it will not increase performance on the 1581.  Adjusting the interleave will also be effective on drives that are closely compatible with the 1541 and 1571 (for example FSD, Bluechip, Amtech, Swan, Excel, Enhancer and Cardco drives).  Adjusting the interleave with drives that are not as closely compatible (such as MSD and Indus drives), should be approached with caution and may in fact disturb the DOS in these drives to the point where disks and data could be corrupted.

.  Files that already perform up to the maximum speed provided by JiffyDOS will not benefit from being re-written using a new interleave value.  In fact, performance with these files will most likely suffer if a different interleave value is used.  However, if a particular program loads or accesses data two to three times slower than is possible with JiffyDOS (refer to the times shown on pages 5 and 6 of the User's Manual), then changing the interleave could provide the increased speed you are looking for.

.  The correct interleave for a particular program or file depends upon numerous factors and must be chosen carefully.  In most cases, a trial-and-error approach must be employed to find the optimum value.

.  Adjusting the interleave for a particular program or file cannot make up for grossly inefficient programming practices.  In other words, if the software you are using is just plain slow, there just isn't much that can be done to speed up disk access.  Even machine language programs can be written poorly enough to fall into this category.

.  Adjusting the interleave may not do much for slow-running languages like BASIC.  A good example is a loop that reads a file one byte at a time using the GET# statement.  Because the BASIC interpreter takes so long to execute each instruction, far too much time passes between the actual reading of each byte.  Compiled BASIC is better, but not as much as you would expect.  While adjusting the interleave may help speed up file access from within BASIC, it will most likely not provide the maximum speed that JiffyDOS is capable of.

.  Some programs utilize custom file access routines that completely bypass the Kernal ROM.  GEOS and Flight Simulator II are two examples.  Neither JiffyDOS nor an altered interleave can help the performance of such programs.

.  Files saved under JiffyDOS using a standard or altered interleave will most likely load slower on stock systems.

.  Be careful if you have both 1541 and 1571 drives.  The optimum interleave for a 1571 drive may cause severely decreased performance on a 1541 drive (1571's can read data much faster than 1541's).  If you have disks that will be used on both 1541 and 1571 drives, then use the optimum interleave for the slower 1541 drive.

If you're not getting top Performance
----------------------------------------------------------------------
When using certain programs, you may feel that JiffyDOS is not increasing performance as much as it should be.  In these cases, the problem is most likely related to the particular software in use.  There are also some considerations to note when using the 1571 drives.

Programs with built-in fast loaders

Some programs utilize their own built-in fast loaders.  Some examples are GEOS, the Mastertracks MIDI sequencer, Fast Hack'Em, and disks created by certain types of ''freezer'' cartridges.  These programs contain their own DOS which bypasses the disk-access routines in the Kernal and DOS ROMs.  Since JiffyDOS resides in these ROMs, any program which bypasses the disk-access routines renders JiffyDOS ineffective.  As a result, JiffyDOS can provide little, if any, performance gains with such programs.

In these cases, better performance may be achieved only by altering the software so that it uses the disk-access routines provided in the Kernal ROM, or to alter the interleave as outlined previously.  Altering the software itself can be a difficult job, even if you have the programming know-how.  Another option is to contact the software manufacturer to see if any versions of the program exist that do not incorporate the built-in fastloader, or if there is an easy way to disable it.  If you own the Mastertracks MIDI sequencer, contact Creative Micro Designs to obtain a free conversion utility which disables the built-in fastloader and enables JiffyDOS to take charge of disk accesses.

BASIC programs

Programs written in BASIC will produce mixed results with JiffyDOS because of the slowness of the BASIC interpreter.  The interpreter spends most of its time figuring out what each instruction is and what it should do with it - making disk access time insignificant when compared to this software overhead.  As a result, the speed increases you notice when using JiffyDOS will vary according to the way the BASIC program was written.

JiffyDOS performs best when loading another program from within BASIC (i.e. LOAD''TEST.ML'',8,1).  Because the entire file is accessed by a single instruction (the LOAD command), JiffyDOS can perform at 100% efficiency.  On the other hand, reading a file byte-by-byte by means of the GET# instruction is the least efficient method of accessing a file.  Because of the amount of software overhead involved in interpreting the GET# instruction and the other instructions in a typical GET loop (and because of the disk-access characteristics of GET#), you will probably notice no better than a 2x speed increase with JiffyDOS.  Whenever possible, use the INPUT# instruction to read files.  Input # will perform much better than GET# - especially if you read in a long string each time INPUT# is executed (the longer the string, the better the performance).

Compiled BASIC (i.e. programs compiled using Basic-64 or Blitz!) will perform better with JiffyDOS than uncompiled BASIC (the elimonatoon of interpreter overhead is the main reason).  However, the degree of speed increase will still depend upon how the original program was written.  See the above paragraph for a discussion of the GET# and INPUT# instructions.

Machine-language programs

JiffyDOS performs best when disk accesses are handled by efficient, well-written machine-language routines (JiffyDOS performance specifications are based on results obtained using ML routines).  However, not all machine-language routines are efficiently written - which means that the speed increases you experience using JiffyDOS can vary greatly from program-to-program.

Fragmented files

''Fragmented'' files have their data scattered across a disk in a non-orderly fashion.  This usually occurs on disks that have had a number of files ''scratched'', or erased.  When a file is saved to such a disk, the DOS first fills up the empty areas left by the scratched files.  If the file being saved is long, it may be written to many of these randomly-located areas.  When it comes time to read the file, the DOS is forced to search across a wide area of the disk in order to retrieve all the data, which can add significantly to the amount of time it takes to read the file.

To eliminate file fragmentation, copy the files from the fragmented disk to an empty disk.  You can transfer the files using the JiffyDOS file copier or a file-copy program.  See ''Getting Maximum Performance'' earlier in this section for more information.

Sprites

''Sprites'' are graphic display items that can be moved around quickly and easily on the screen.  Although sprites are used primarily in games (Pac-Man is a sprite), they are also found in other types of programs (the GEOS pointer is also a sprite).  While it seems unlikely that a screen graphic could affect disk-access performance, sprites present a real problem for serial-bus communications routines.  Sprites are hardware-generated by the VIC-II chip, and displaying them requires the VIC-II to ''steal'' cycles from the 6510/8510 microprocessor.  Cycle stealing makes it impossible to use high-speed software timing loops to transfer data over the serial bus (JiffyDOS uses timing loops).  Even the stock Commodore C-64 is prone to hang up when sprites are displayed during serial I/O.

The solution to the problem is to disable sprites (shut them off) whenever serial bus communications are taking place.  This is the approach used by GEOS (you'll notice the pointer disappear during disk accesses).  Unfortunately, few programs imitate GEOS in this regard.  Because of such programs, JiffyDOS is forced to disable sprites on its own (Commodore also does this in their 128-mode DOS).  When JiffyDOS has to disable sprites for each byte read or written over the serial bus, data transfer slows down to the turtle-like speed of stock systems (this slowdown also occurs, by the way, with Commodore's 128-mode DOS).

Unfortunately, there is not much you can do if sprites are causing JiffyDOS to slow down (unless, of course, you have written the offending program yourself and can change it).

1571 drives

If you are using a JiffyDOS-equipped 1571 drive with a C-64, SX-64, or a C-128 in 64 mode, you will obtain maximum performance only if the 1571 is in 1541 mode.  With JiffyDos installed, your 1571 can access (and format) both sides of a disk in 1541 mode - making it unnecessary to switch to 1571 mode to benefit from the increased dual-side storage.  This means:

1.  You should not use the ''U0>M1'' command to switch into 1571 mode when using a C-64, SX-64 or C-128 in 64 mode (this will reduce performance).  C-64/SX-64 owners:  Note that the 1571 is automatically in 1541 mode upon power-up.

2.  When switching from 128 mode to 64 mode on a C-128, use the reset switch and hold down the Commodore key.  Do not use the ''GO64'' command.  Using GO64 will leave the 1571 in 1571 mode, resulting in reduced performance in 64 mode.

Note:  If you must use the GO64 command, sending the ''U0>M0'' command to the 1571 disk drive will place it in 1541 mode, ensuring best performance.

If a Program won't Load or Operate
----------------------------------------------------------------------
Although we have made every effort to ensure compatibility with as much software as possible, you may occasionally run across a program that will not load or operate properly with JiffyDOS.  Loading problems are almost always caused by extravagant copy-protection schemes that rely on stock head step rates, serial bus timing, and particular ROM versions (these copy protection schemes are the same ones that cause loading problems on 1571 and 1541C drives).  Unfortunately, it would be necessary to reduce the performance of JiffyDOS in order to provide compatibility with these programs.

Another very rare type of program will load OK under JiffyDOS but will not operate properly once loaded.  This type of problem is caused almost exclusively by bad programming practices (i. e. the indiscriminate use of ROM routines without regard to normal entry points, jump tables, etc.).  This misuse of ROM routines has become so widespread that Commodore is now very reluctant to change (even fix or improve) their own ROMs for fear of introducing compatibility problems.  Since JiffyDOS relies on carefully selected ROM changes to enhance performance, undoing any of these alterations to provide compatibility with just one program would unfortunately reduce performance, features, or both.

What to do if a program won't load

JiffyDos includes a switch which will return your system to a 100% stock configuration to ensure compatibility with the few programs that do present problems.  Refer to ''ROM Switching'' earlier in this section for information on how to switch JiffyDOS out in order to provide compatibility with problem programs.

Using JiffyDOS with RAM Units
----------------------------------------------------------------------
The JiffyDOS commands support Commodore's RAMDOS for the 1700, 1750 and 1764 RAM Expansion Units in both 64 and 128 modes.  Please read the following information carefully before using an REU with JiffyDOS.

Recommended RAMDOS Versions

The following versions of Commodore's RAMDOS are required for proper operation with JiffyDOS:

   64 mode:     RAMDOS V4.2 (or higher)
   128 mode:    RAMDOS V4.3 (or higher)

Using earlier RAMDOS versions will subject you to the bugs that they contain and to incompatibilities with certain JiffyDOS commands.  If you do not have the correct version of RAMDOS, it can be obtained from Q-Link, a User's Group, bulletin board or friend.  Note:  All versions of Commodore's RAMDOS are in the public domain.

JiffyDOS commands that conflict with RAMDOS

The following JiffyDOS commands are incompatible with Commodore's RAMDOS and should not be used:

   @L:filename      (Lock a file)
   |filename        (load and run a machine-language program)

Starting up RAMDOS on your JiffyDOS system

To use RAMDOS along with JiffyDOS, do the following:

1.  Power up or reset your system with JiffyDOS active (the power-on screen message will indicate if JiffyDOS is switched in).

2.  Start up RAMDOS as you would normally.  DO NOT load the DOS Wedge supplied on your RAMDOS diskette - it will disable the JiffyDOS commands.

3.  Use the JiffyDOS commands as you would normally to access the REU.  Remember to avoid the JiffyDOS commands that are not compatible with RAMDOS (see above).

The limitations of RAMDOS

Commodore's RAMDOS relies on software vectors to operate.  Since many commercial programs reset these vectors, they effectively disable RAMDOS and render the REU useless.  Because of the design of RAMDOS and the REU, JiffyDOS cannot overcome this limitation and provide increased commercial compatibility with RAMDOS.  So, although JiffyDOS will make using your REU easier, it cannot by itself extend the usefulness with commercial software.  Future CMD products are planned which will overcome these problems and make your REU useable with nearly all software.

Using JiffyDOS Commands with BASIC
----------------------------------------------------------------------
Whenever JiffyDOS executes a command, it opens up a 255-byte buffer at the top of BASIC.  If you have a BASIC program in memory that takes up all (or almost all) of the available BASIC memory, an OUT OF MEMORY error may occur when the buffer is opened.  If this problem occurs with a particular program you are working on or using, you can do two things to overcome the memory shortage:  1) If you are in direct mode, enter CLR.  In most cases, this will free up enough memory for the buffer.  2) Shorten the offending program, or cut down on its use of arrays and variables.

===============================================================================

                                 SECTION 4
                           THE JIFFYDOS COMMANDS

JiffyDos offers the convenience of a complete, built-in implementation of the Commodore DOS 5.1 Wedge command set.  Also included are a set of additional commands that provide functions that are not accessible on stock systems or through the standard DOS Wedge.  All JiffyDOS commands can be entered in BASIC direct mode and/or used from within BASIC programs.

Command Descriptions

This section gives a complete description of each JiffyDOS command.  The commands are listed by their function, along with the syntax of each form of the command.  Examples are provided after the command descriptions to illustrate the use of each command in its basic and optional forms.  If no example is given, the only form of the command is as listed in the syntax line.  Here is a brief description:

. . .     Indicates a command in which the last parameter given may be repeated.  NOTE:  The maximum length of a command string is 41 characters.

{ }       Used to enclose information which is optional to the command syntax.  The brackets themselves are not part of the command.

filename  Indicates where a filename should be placed in a command.  Other names are used to indicate filenames as well such as oldfile, file1, and backup.

dev#      Used to indicate where a device number should be placed in a command.  Legal device numbers are usually 4 or 5 for printers, and 8 through 11 for disk drives.

Direct:   Shows the syntax of the command when used in direct mode.

Program:  Shows the syntax of the command when used in a program.  This syntax may usually be used in direct mode as well, and in many cases, must be used in order to take advantage of the default device override feature.

Parameters printed in italics are not literal and should be replaced with the proper information when using the command.

Parameters printed in plain text are literal and must be included in the command.

A drive number may optionally be used with most drive commands.  This is useful when using dual drives such as the MSD-2 or Commodore 4040.  To indicate a drive number (0 or 1), place the drive number just prior to the colon (:) in the command string.  If using a command with quotes, place the device number and colon within the quotes.

Setting the Default Device
----------------------------------------------------------------------
Two commands are available for switching the JiffyDOS default device on multiple-drive systems:  The standard DOS Wedge command :#, and the convenient JiffyDOS <CONTROL>+<D> device toggle.

@#

Direct:   @#>dev#<

Program:  same

The @# command is used in multiple-drive systems to specify the default disk drive device number for all JiffyDOS commands.  When this command is entered, an attempt is made to access the drive with the device number specified within the command.  If the access succeeds, the specified drive becomes the new default drive.  If the access fails, a DEVICE NOT PRESENT error will be displayed, and the default device will remain unchanged.

@#9       Sets the default drive device number to 9 (if device 9 is present).

<CONTROL>+<D>

The <CONTROL>+<D> command is used on multiple-drive systems to switch the default disk drive device number for all JiffyDOS commands.  Pressing <CONTROL>+<D> (holding down the <CONTROL> key and pressing D at the same time) will switch the default device assignment and display the new device number on the screen.  For example, if device 8 is the current default, <CONTROL>+<D> will make device 9 (if present) the default, and display a ''9'' on the screen.  If device 9 is the current default, pressing <CONTROL>+<D> will make device 8 the default, and display an ''8'' on the screen.  <CONTROL>+<D> offers a much more convenient means of changing default devices than the :# command.  The <CONTROL>+<D> command is only available in direct mode.

Displaying the Directory
----------------------------------------------------------------------
Direct:   @${:filename}

Program:  :''${:filename}''{,dev#}

JiffyDOS provides a quick, convenient way to display disk directories without overwriting programs stored in your computer's BASIC memory.  JiffyDOS directories can be easily printed, suspended or ended at any time.

The @$ command displays the disk directory.  Typing @$ with no filename displays the entire directory.  @$ followed by a colon and a filename will display the specified file in the directory listing (if it exists).  A selective listing can be displayed by using pattern matching or wild cards as part of the filename.  The directory can be printed by entering the @P command prior to issuing the @$ command, and after the listing has been completed, output can be restored to the screen by issuing another @P command.

Note:  A directory listing produced by the @$ command can be paused or suspended at any time by using the commands described in the section titled ''Listing Freeze''.

@$        Displays the entire directory.

@$:TEST   The directory listing will display the file TEST if it exists on disk.

@$:T*     All files having a ''T'' as the first letter in their filename will be displayed in the directory listing.

@P        Lists the directory to a printer.
@$        Output is then restored to the
@P        screen.

Reading the Disk Drive Error Channel
----------------------------------------------------------------------
Direct:   @{'''',dev#}

Program:  same

JiffyDOS makes it easy to find out what has happened when the error light on your disk drive starts flashing.  Instead of having to type in a program (as you must on stock systems), you can enter a single character to display the error messages output by your disk drive.

The @ command is used to read and display the disk drive error channel.  This is useful in determining what type of error has occurred when the red error light on the disk drive is flashing (you will also be pleased to find that issuing the @ command will also shut off the distracting flash of the error light).  If @ is typed when the error light is not flashing, the drive ''OK'' message will be displayed (00, OK,00,00).

If the @ command is entered when the system (or your disk drive) has just been powered up or reset, the disk drive's DOS type and version number will be displayed.

Loading BASIC Programs
----------------------------------------------------------------------
JiffyDOS provides two commands for loading BASIC programs.

Load a BASIC program

Direct:   /filename

Program:  /''filename''{,dev#}

The / command provides a shorthand method of loading a BASIC program.  Typing /filename is identical to entering the BASIC command LOAD''filename'',n (where n is the default drive device number).

Load and RUN a BASIC program

Direct:   ~filename

Program:  ~''filename''{,dev#}

The ~ command loads and runs a BASIC program.  Typing ~filename is the same as entering the BASIC commands LOAD''filename'',n (where n is the default drive device number) and RUN.

Saving BASIC Programs
----------------------------------------------------------------------
Direct:   <-filename

Program:  <-''filename''{,dev#}

The JiffyDOS <- command saves a BASIC program.  Typing <-filename is equivalent to entering the BASIC command SAVE''filename'',n (where n is the default drive device number).

Loading Machine-Language Programs
----------------------------------------------------------------------
JiffyDOS provides two powerful commands for loading machine-language programs.

Load a machine language program

Direct:   %filename

Program:  %''filename''{,dev#}
The % command loads a machine language file without resetting any BASIC pointers.  Typing %filename is the equivalent of entering the command LOAD''filename'',n,1 (where n is the default drive device number), except that the BASIC program pointers are not reset as a result of the load.  This avoids OUT OF MEMORY errors, and also means that the BASIC program pointer is not reset to the beginning of the current program.  Thus, this command provides a way to load ML programs from within a BASIC program without resorting to the usual contortions.  For example, use a routine similar to the following to load a number of machine language modules:

10 %''ML1'':%''ML2'':%''ML3''

Load and execute machine language program

Direct:   |filename

Program:  |''filename''{,dev#}

The | command loads and then runs a machine-language program.  Typing |filename is a much more convenient alternative to entering LOAD''filename'',n,1 and then doing a SYS to start the program.  At the beginning of a load, the | command finds the starting address of the ML file and then begins execution at that addredss when the program has finished loading.  Note:  While this command will work properly with most machine language programs, it will not work with programs that have entry points that differ from their load addresses.

Loading and Running the First Program on Disk
----------------------------------------------------------------------
<Shift>+<RUN/STOP>

The <Shift>+<RUN/STOP> key combination can be used to load and run the first program on disk.  Using this command is identical to entering the BASIC commands LOAD'':*'',8,1 and RUN.  This provides a quick, convenient way of starting up most commercial software programs.  In 64 mode the <Commodore> key may be used instead of <Shift>.

Verifying Programs
----------------------------------------------------------------------
Direct:   'filename

Program:  ' ''filename''{,dev#}

The ' (apostrophe) command verifies a file in memory against a file on disk.  Using this command provides a shorthand method of entering the BASIC command VERIFY''filename'',n,1 (where n is the default drive device number).  This command will work with all machine language files and with all BASIC programs that have been saved under the current BASIC environment (i. e. a BASIC program saved on the C-64 will verify properly on a C-64 but not on a C-128 in 128 mode).

Listing BASIC Programs from Disk
----------------------------------------------------------------------
Direct:   @D:filename

Program:  @D''filename''{,dev#}

The @D (DLIST) command enables a BASIC program to be listed to the screen or to a printer directly from the disk without loading it into memory first.  The file listing can be directed to a printer by issuing the @P command prior to using this command.  After the listing has been completed, output can be restored to the screen by entering the @P command once again.  For legible results, take care to use @D to list only BASIC programs.

Note:  A listing produced by the @D command can be paused or suspended at any time by using the commands described in the section titled ''Listing Freeze''.

@D:GAME     A listing of the program GAME will be sent from disk to the screen.

@P          A listing of the program LOTTERY will be
@D:LOTTERY  output from disk to a printer (device #4).
@P          Output is then restored to the screen.

Listing ASCII Files from Disk
----------------------------------------------------------------------
Direct:   @T:filename

Program:  @T''filename''{,dev#}

The most common use of the @T (TYPE) command is to list an ASCII text file (such as a wordprocessor file) to the screen or to a printer.  When using @T, care should be taken to list ASCII files only - otherwise, the results may be unpredictable (for example, a BASIC program will display garbage if listed to the screen or to a printer via @T).  The default output device for the @T command is the screen.  To list a file to the screen, enter @T:filename.  To print a listing, issue the @P command prior to using the @T command.  When the printout is complete, you can restore output to the screen by entering @P once more.

Note:  A listing produced by the @T command can be paused or suspended at any time by using the commands described in the section titled ''Listing Freeze''.

@T:LETTER        Lists the file LETTER to the screen.

@P               Lists the file APPOINTMENTS to a printer.
@T:APPOINTMENTS  Output is restored to the screen at the
@P               completion of the command.

''Un-NEWing'' a BASIC Program
----------------------------------------------------------------------
Direct:   @O

The JiffyDOS @O (Old) command can be used to recover a BASIC program that has been accidently ''NEWed''.  Entering @O will also recover a BASIC program lost when the computer is reset.  Note that the Un-NEW command is only effective if no new BASIC lines have been entered since the original program was lost.

Initializing the Disk Drive
----------------------------------------------------------------------
Direct:   @I

Program:  @''I''{,dev#}

The @I (INITIALIZE) command initializes the disk drive.  Initialization causes the drive to read the BAM (block availability map) and ID from a diskette and store this information in its internal memory.  Initialization also clears the error channel and turns off the error LED on the drive (if it is flashing).  At times (i. e. after a DRIVE NOT READY error), it will be necessary to initialize the disk drive before it can be used to perform any further operations.  Remember that the @I command clears the error status of the drive, so if you wish to read the drive error channel after an error has occurred (see the @ command), do so before using this command.  Note that it is a good idea to initialize the disk drive every time you insert a diskette into the drive.

Resetting the Disk Drive
----------------------------------------------------------------------
Direct:   @UJ

Program:  @''UJ''{,dev#}

The @UJ command is used to reset the disk drive.  Note that @UJ may not work properly with older 1541 drives.  For this command to work with older 1541's, the alternate syntax @U: may be required.

Validating Disks
----------------------------------------------------------------------
Direct:   @V

Program:  @''V''{,dev#}

The @V (VALIDATE) command is used to free unused blocks on a diskette.  After a diskette has been in use for a while, more blocks may be free than the BAM and directory indicate.  Primarily, this happens when unclosed files have been scratched.  Using the @V command will free space on a diskette available for use.  Note that this command may take some time to complete, depending on the amount and size of the files located on the particular diskette.

Formatting Disks
----------------------------------------------------------------------
The @N (NEW) command is used to format a diskette.  There are three versions of this command to cover long, short, and extended formatting of the diskette.

Note:  Using inferior media can cause errors during formatting.  JiffyDOS is less forgiving in this respect than the stock DOS, but when a formatting error occurs it should indicate to you that the media may not be reliable.

''Long'' NEW

Direct:   @N:diskname,ID

Program:  @''N:diskname,ID''{,dev#}

This version of the @N command is necessary when formatting a diskette for the very first time.  Diskname is any name you wish to assign to the disk and can be up to 16 characters long (the diskette name appears at the top of directory listings).  The ID can be any 2 characters and is written to the directory along with the diskname and also to all header blocks on the diskette.  Remember to include the comma between diskname and ID when using this form of the command.

''Short'' NEW

Direct:   @N:diskname

Program:  @''N:diskname''{,dev#}

This version of the @N command performs a ''short'' NEW on a diskette that has already been formatted.  A short NEW clears the directory and BAM of an already-formatted diskette and is much quicker than completely reformatting.

''Extended'' NEW for 1571 from 64 mode

(JiffyDOS-equipped 1571 drives only)

Direct:   @N2:diskname,ID

Program:  @''N2:diskname,ID''{,dev#}

This version of the @N command is used exclusively to format both sides of 1571 disks when the 1571 is in 1541 mode (the stock Commodore DOS allows only one side of a diskette to be formatted in 1541 mode).  This command helps take advantage of the double-side 1541-mode operation provided by JiffyDOS.  Note that the 1571 is in 1541 mode upon power-up, and will only switch to 1571 mode if used with a C-128 in 128 mode, or if the U0>M1 command is issued.  The @N2 command is effective only on 1571's equipped with JiffyDOS - using this command on other drives will result in a syntax error (no formatting will take place).

Examples:

@N:NEWDISK,00        Completely formats (NEWs) a diskette and assigns the name ''NEWDISK'' and the ID code ''00'' to the diskette.

@N:BACKUP            Performs a short NEW (clears the directory and BAM) and assigns the name ''BACKUP'' to the diskette.

@N2:TWOSIDE,01       Formats both sides of a 1571 disk when the 1571 is in 1541 mode.  Assigns the name ''TWOSIDE'' and the ID code ''01'' to the diskette.

@''N:NEWDISK,00'',9  Completely formats a diskette in the drive assigned as device number 9 with the name ''NEWDISK'' and the ID code ''00''.

Disabling the 1541 ''Head Rattle''
----------------------------------------------------------------------
Direct:   @B       (JiffyDOS/64 only)

Program:  same     (JiffyDOS/64 only)

The @B (BUMP) command can be used to disable the 1541 head rattle (bump) routine which occurs when certain disk errors are encountered.  Entering @B will disable the head rattle.  If you wish to re-enable the head rattle, you may do so by issuing the @UJ command.  This command does not support the default device override function.

Note:  To ensure accurate formatting, @B will not disable the head bump at the start of a disk NEW (format).

Copying files
----------------------------------------------------------------------
The JiffyDOS file copier consists of four specialized commands that enable you to make quick, convenient copies of non-copy-protected programs or data files.  See the section on using the JiffyDOS file copier for step-by-step procedures on how to apply these commands.

Set Destination Device

Direct:   @Xdev#

Program:  same

The @X command sets the destination drive for copying files.  The device number specified in the command can be that of any disk drive on the serial bus, or the device number of a RAM expansion unit.

@X10      Set the destination drive to device 10.

Copy file from source to destination

Direct:   *''filename''filetype

Program:  same

The * (asterisk) command copies a file to the destination drive specified in the @X commands (see above).  The filetype specified by this command can be PRG, SEQ, REL, or USR.

*''TEST''PRG   Copies the PRG file ''TEST'' to the destination drive specified in the last @X command that was issued.

<CONTROL>+<A>

The <CONTROL>+<A> command toggles the copy flag for all files in the directory listing.  For this command to work properly, the directory must first be loaded into memory using the /$ command.  When you press <CONTROL>+<A>, the copy flag for each file in the directory will be toggled, and then the directory will be re-listed to the screen with the new copy status for each file displayed.  A file marked for copying will have an asterisk (*) next to it in the directory listing.  After you have marked the files that you want to copy, the actual process of copying the files is started by entering the BASIC RUN command.

<CONTROL>+<W>

The <CONTROL>+<W> command toggles the copy flag of a single file in the directory listing.  For this command to work properly, the directory must first be loaded into memory using the /$ command.  To select the file that you wish to toggle, move the cursor to that file in the directory listing and press <CONTROL>+<W>.  The cursor must be kept to the leftmost edge of the screen.  A file marked for copying will have an asterisk (*) next to it in the directory listing.  If the directory listing is longer than one screen, you can use the JiffyDOS ''Listing Freeze'' feature to easily locate the desired file(s).  You can redisplay the entire directory listing at any time by entering the BASIC LIST command.  After you have marked the files that you want to copy, the actual process of copying the files is started by entering the BASIC RUN command.

Changing the Sector Interleave
----------------------------------------------------------------------
JiffyDOS provides a means for adjusting the interleave (intersector gap) for files it writes.  Adjusting the sector interleave can provide faster program loading and file-access performance in instances where the standard JiffyDOS interleave values are not appropriate.  Adjusting the interleave can be one of the best ways to improve performance when a 1571 disk drive is used on a C-128 in 128 mode.  See the section on adjusting the sector interleave under ''Getting Maximum Performance'' for step-by-step procedures on how to apply this command.

Gapsize

Direct:   @Ggapsize

Program:  same

The @G command changes the sector interleave (intersector gap) of the current JiffyDOS default disk drive to the value specified by gapsize.  Valid gapsize values range from 0 to 16.  Since no range checking is done by this command, be sure that you do not exceed the above limits (0-16), or else unpredictable drive operation may result during writes to disk.  If you find that you have entered an illegal value, simply re-enter the command with the correct value.  To reinstate the default JiffyDOS interleave, enter a gapsize of 0.  Remember, changing the sector interleave is only effective on 1541, 1571 and compatible drives - do not try to change the interleave of 1581 or MSD drives.  Also, please note that the default device override feature cannot be used with this command.

@G8       Set the sector interleave of the default device to 8.

@G0       Re-establish the standard JiffyDOS interleave.

Combining Files and Creating Backups
----------------------------------------------------------------------
Direct:   @C:newfile=oldfile{,file2}...

Program:  @''C:newfile=oldfile{,file2}...''{,dev#}

The @C (COPY) command enables you to duplicate a file.  @C can also be used to combine two or more text or data files into a single file.  Programs may not be combined in this manner.  Note that @C will duplicate a file under a different name on the same diskette, but will not copy or combine files from one diskette to another, or from one drive to another.

@C:BACKUP=ORIGINAL  Creates a new file named BACKUP which is an exact duplicate of the file named ORIGINAL.

@C:DATA=BITS,BYTES  Creates a file named DATA which is the combination of the files BITS and BYTES.

Renaming Files
----------------------------------------------------------------------
Direct:   @R:newname=oldname

Program:  @''R:newname=oldname''{,dev#}

The @R (RENAME) command can be used to rename a file on disk.  When using the @R command, remember that the new name for the file is entered first (to the left of the = sign) and that the existing name of the file is entered second (to the right of the = sign).

@R:REPORT=NOTES  Renames the file NOTES as REPORT.

Scratching (Deleting) Files
----------------------------------------------------------------------
Direct:   @S:file1{,file2}...

Program:  @''S:file1{,file2}...''{,dev#}

The @S (SCRATCH) command can be used to delete (scratch) a file or a number of files from a disk.  Files can be scratched one at a time (by entering the exact filename) or in groups, by specifying filenames explicitly or by using pattern matching and/or wild cards.  The error channel may be read at the completion of the @S command by issuing the @ command, but will not otherwise be displayed.  If used after scratching, the number of files scratched will be displayed.  For example, the following message indicates that two files have been scratched:

   01,  FILES SCRATCHED,02,00

This message indicates that no files have been scratched:

   01,  FILES SCRATCHED,00,00

Examples of using the @S command:

@S:TEST              Scratches the file named TEST

@S:*                 Scratches all files from a disk.

@S:T*                Scratches all files that begin with the letter T.

@S:?T                Scratches all files with names two characters long that have a ''T'' as the second character.

@S:BITS,BYTES,WORDS  Scratches the files BITS, BYTES and WORDS

Locking and Unlocking Files
----------------------------------------------------------------------
Direct:   @L:filename

Program:  @''L:filename''{,dev#}

The @L (LOCK) command locks and unlocks files.  Once a file has been locked, it cannot be accidently scratched and is marked with a ''<'' at the end of its directory entry (i. e. 32 ''TESTFILE''           PRG<).  The @L command works as a toggle - that is, if @L is used on an unlocked file, the file will be locked.  If @L is used on an already locked file, the file will be unlocked.

Note:  The LOCK command (@L) will not work with 1581 or MSD disk drives which are not equipped with JiffyDOS.

@L:TESTPROGRAM   Locks the file TESTPROGRAM (if TESTPROGRAM is not currently locked).

@L:TESTPROGRAM   Unlocks the file TESTPROGRAM (if TESTPROGRAM is currently locked).

Directing Output to a Printer
----------------------------------------------------------------------
Direct:   @P{,dev#}{,secondary address}

Program:  same

The @P (Printer output toggle) command makes it easy to send BASIC program listings, directory listings, or output from the JiffyDOS @D and @T commands to a printer.  Entering @P before issuing a command that normally produces a listing to the screen will result in the screen output being redirected to your printer (the default is device #4, secondary address=0).  If you wish to specify a different printer device number and/or secondary address, include the device number and secondary address in the @P command as shown in the examples below.  To restore output to the screen after using the @P command, simply enter @P again.  Normally, the secondary address of 0 is used for uppercase/graphics printing, and a secondary address of 7 is used for uppercase/lowercase printing.

@P      Send screen output to printer (device #4, secondary address 0)

@P,5    Send screen output to printer (device #5, secondary address 0)

@P,5,7  Send screen output to printer (device #5, secondary address 7)

@P      Restore output to screen (assuming @P has already been used to redirect screen output to a printer).

Printing the Screen
----------------------------------------------------------------------
<CONTROL>+<P>

The <CONTROL>+<P> (PRINT SCREEN) command outputs the current text screen to a printer.  Pressing <CONTROL>+<P> (holding down the <CONTROL> key and then pressing ''P'') will cause the text displayed on the screen to be sent to a printer.  This function automatically detects the current screen mode in order to print from the proper character set.  The printer must be configured as device 4.

Disabling the JiffyDOS Function Keys
----------------------------------------------------------------------
Direct:   @F

Program:  same

The @F (FUNCTION KEY) command is used to disable the JiffyDOS function key definitions.  Typing @F with the function keys enabled (as they are upon power-up) will disable them.  In 128 mode this will cause the standard 128 function key definition to be activated.  The JiffyDOS function key definitions are active only in BASIC direct mode and are disabled when programs are run in order to avoid conflict with any program-defined function key assignments.

Re-Enabling the JiffyDOS Function Keys
----------------------------------------------------------------------
SYS 58551   (JiffyDOS/64)

SYS 65137   (JiffyDOS/128)

The SYS commands are used to re-enable the JiffyDOS function key assignments.  This can be necessary if the commands have been previously disabled via the @F command, or after a program has been run.

SYS 58551   Will restore the JiffyDOS/64 function keys and commands on a C-64, SX-64 or C-128 in 64 mode.

SYS 65137   Will restore the JiffyDOS/128 function keys on a C-128 in 128 mode.

Disabling the JiffyDOS Commands
----------------------------------------------------------------------
Direct:   @Q

Program:  same

The @Q (QUIT) command disables all JiffyDOS commands and function key definitions and reinstates all stock BASIC vectors.  The disk drive fast-access routines are not disabled, however, and will continue to operate at full speed.

Re-Enabling the JiffyDOS Commands
----------------------------------------------------------------------
SYS 58451   (JiffyDOS/64)

SYS 65137   (JiffyDOS/128)

These SYS commands are used to re-enable the JiffyDOS commands.  This can be necessary if the commands have been previously disabled via the @Q command, if the JiffyDOS Kernal has been switched in while the computer power is ON, or if an applications program has altered the BASIC tokenization or execution vectors.  In any of these cases, the JiffyDOS commands will not be available.

SYS 58451   Restores the use of all JiffyDOS/64 commands on a C-64, SX-64, or C-128 in 64 mode.  This will not restore the JiffyDOS function key definitions.

SYS 65137   Restores the use of all JiffyDOS/128 commands on a C-128 in 128 mode.

Special Command Features
----------------------------------------------------------------------
Using the Commands in Direct and Program Modes

All JiffyDOS commands may be used in BASIC direct mode and/or from within BASIC programs.  When using the commands within programs, many of the command/filename strings must be enclosed in quotes.  For example, @S:FILENAME is acceptible in direct mode only, while @''S:FILENAME'' is the required form for program mode.  The following are examples of using commands in program mode.  Be sure to check the command syntax given in the previous reference section if you are uncertain how to use a command in program mode.

Examples of program-mode command syntax:

10 @''$:*''           Display the directory

20 @''S0:filename''   Scratch a file

30 @#9                Set the default device to 9

40 @''D:filename''    List a BASIC program from disk

50 @''I:''            Initialize the default drive

Drive Specification

All commands which perform a disk operation may specify a drive number (0 or 1) within the syntax of the command.  This is useful if a dual-drive unit (i. e. MSD-2 or Commodore 4040) is sharing the serial bus with a JiffyDOS system.  To specify the drive number, insert the 0 or 1 in front of the colon in each command.

Examples:

@$1:*          List the directory from drive 1

@S0:filename   Scratch a file from drive 0

When addressing 1541 and compatible drives, the 0 or 1 is not required, but a 0 may be used if desired.

===============================================================================

Enhancements to the DOS Wedge
----------------------------------------------------------------------
JiffyDOS offers these three major enhancements to the standard DOS Wedge command format.

Command Chaining

In program mode, the JiffyDOS commands may be chained with BASIC commands or other JiffyDOS commands within the same program line.

Examples:

10 @#9:@''S:TEST'':@#8   Switch default to device 9, scratch a file, and then switch the default back to device 8.

20 @''$:*'':PRINT:@      Display the directory, print a blank line, and display the error channel.

Note:  Chaining is also possible to some degree in direct mode, as long as program-mode syntax is used, and no standard BASIC commands are intermixed with JiffyDOS commands.

String Variables

With JiffyDOS, string variables may be used as part of the standard DOS Wedge and JiffyDOS commands.  This makes it possible to input disk command strings from the keyboard into a string variable, and then use that variable within a command sent to the disk drive.  This makes it easy to design short, memory-efficient, interactive disk ''housekeeping'' programs with JiffyDOS - something which is not possible with the Commodore DOS Wedge, which forces filenames to be hard-coded into your program.

Example program using string variables:

10 REM SCRATCH A FILE
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

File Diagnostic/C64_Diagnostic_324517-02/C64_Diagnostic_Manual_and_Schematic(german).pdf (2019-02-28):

Zuerst werden alle Prüfstecker angeschlossen, dann das Modul reingesteckt und erst zum Schluß der Rechner eingeschaltet!!

Brückenbelegung für C64-Diagnostik

### 1. Keyboard - Stecker:

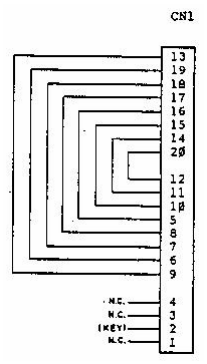
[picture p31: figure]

### 2. Control-Port 1 + 2 Stecker (R1 – R4 = 270k 1/8W ausgemessen)

(Joystick-Port)

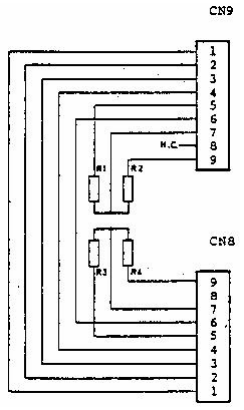
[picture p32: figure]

### 3. User-Port Stecker

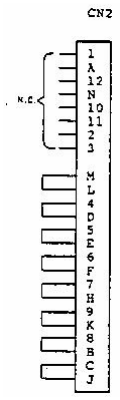
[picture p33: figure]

### 4. Casetten-Port Stecker

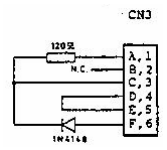
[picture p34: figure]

### 5. Serial-Port Stecker ( IEC-Gerätestecker z.B Floppy, Drucker, etc.)

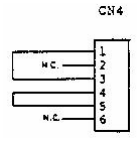
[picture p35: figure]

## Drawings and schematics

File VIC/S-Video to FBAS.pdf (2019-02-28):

A | B | C | D | E | F

1

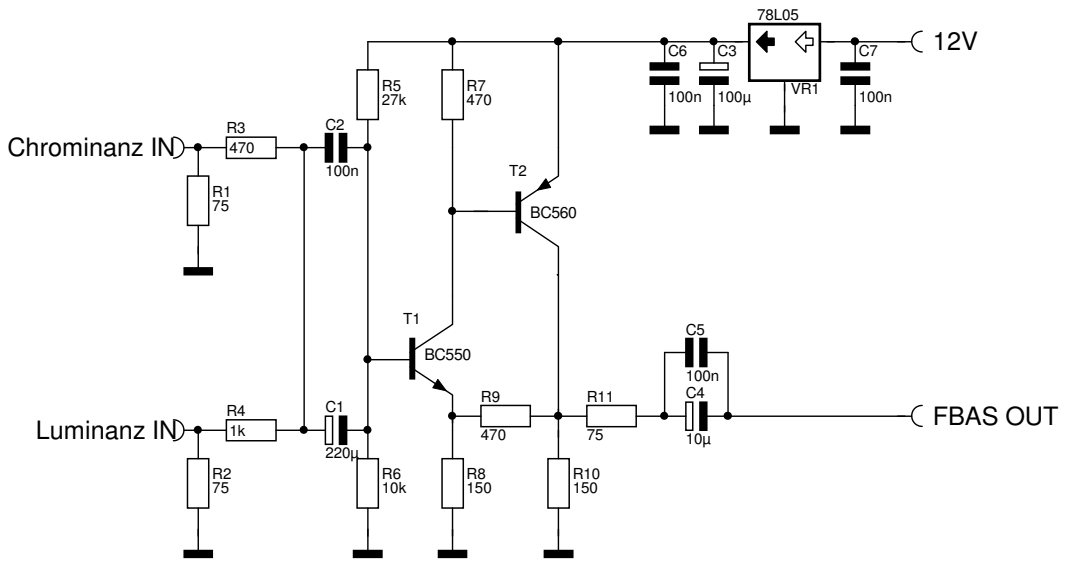
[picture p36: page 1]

FBAS OUT Luminanz IN

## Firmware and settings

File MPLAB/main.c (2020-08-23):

/*
 * File:   main.c
 * Author: svpet
 *
 * C64 Controller
 * Clock: 40 MHz ext. = 10 MHz int.
 *
 * pin layout:
 * RA0: KEYB_DATA (input)
 * RA1: KEYB_CLOCK (input/output)
 * RA2: TOD_50Hz
 * RA3: /NMI
 * RA4: /RESET
 * RA5: /MCLR
 * RA6:
 * RA7: CLKI
 * RB0-RB2: AX0-AX2 (address for COL/PA)
 * RB3-RB5: AY0-AY2 (address for ROW/PB)
 * RB6: /STROBE
 * RB7: SW_DATA
 * 
 * Created on 28. Februar 2019, 21:16
 */

#include "config.h"
#include "base.h"

#include <xc.h>
#include <pic18f1220.h>
#include <plib/xlcd.h>
#include <stdio.h>
#include <stdlib.h>

#include "lcd.h"
#include "keyboard.h"

#define TIMER_HI 0xCF // 40 MHz
#define TIMER_LO 0x2C // 40 MHz

unsigned char shiftlock_active;

void __interrupt () Isr () {
    TMR0H = TIMER_HI; // interrupt every 10 ms
    TMR0L = TIMER_LO;

    if (LATAbits.LA2 == 0)
        LATAbits.LA2 = 1;
    else
        LATAbits.LA2 = 0;

    INTCONbits.TMR0IF = 0;
}

void Initialize() {
    
    ADCON0 = 0; // disable A/D converter
    ADCON1 = 0x0F;

    INTCON = 0b10100000; // Enable Timer0 interrupt, disable peripheral interrupts
    INTCON2 = 0b10000000; // disable PORTB pull-up
    INTCON3 = 0;
    PIE1 = 0;
    PIE2 = 0;
    IPR1 = 0;
    IPR2 = 0;
    RCON = 0;
    CCP1CON = 0;

    T0CON = 0b00000010; // Timer0: prescaler 8, 16 bit, disabled
    TMR0H = TIMER_HI; // interrupt every 10 ms
    TMR0L = TIMER_LO;

    TRISA = 0b00001001;
    LATA = 0b00000000;
    TRISB = 0b00000000;
    LATB = 0;

    // Init PS/2 keyboard
    InitKeyboard();
}

void SetC64Key(unsigned char key, unsigned char state) {
    unsigned char col, row, swaddr;
   
    col = (key & 0x70) >> 4;
    row = key & 0x07;
    swaddr = col + (row << 3);
    LATB = swaddr | 0b01000000;
    if (state > 0)
        LATBbits.LB7 = 1;
    NOP();
    LATBbits.LB6 = 0;
    NOP();
    LATBbits.LB6 = 1;
/*   
    if (state == 1)
        Lcd_Set_Cursor(1, 1);
    else
        Lcd_Set_Cursor(2, 1);
   
    printf("col: %d row: %d  ", col, row);
 */
}
/*
void print_c64key() {
    SetC64Key(c64key, 1);
    __delay_ms(50);
    SetC64Key(c64key, 0);
    __delay_ms(50);
}

void output_digit(unsigned char digit) {
    switch (digit) {
        case 0: // 0
            c64key = 0x43;
            break;
        case 1: // 1
            c64key = 0x70;
            break;
        case 2: // 2
            c64key = 0x73;
            break;
        case 3: // 3
            c64key = 0x10;
            break;
        case 4: // 4
            c64key = 0x13;
            break;
        case 5: // 5
            c64key = 0x20;
            break;
        case 6: // 6
            c64key = 0x23;
            break;
        case 7: // 7
            c64key = 0x30;
            break;
        case 8: // 8
            c64key = 0x33;
            break;
        case 9: // 9
            c64key = 0x40;
            break;
    }
    print_c64key();
}

void output_num(unsigned char value) {
    unsigned char d;
    d = value / 100;
    output_digit(d);
    value -= d * 100;
    
    d = value / 10;
    output_digit(d);
    value -= d * 10;
    
    output_digit(value);
    
    c64key = 0x01; // RETURN
    print_c64key();
}
*/
void MainLoop() {
//    unsigned char scode;

/*
    while (1) {
        while (KeybGetScancode(&scode) == 0) ;
                
        Lcd_Set_Cursor(1, 1);
        printf("%d ", scode);
        while (KeybGetScancode(&scode) == 1)
          printf("%d ", scode);
                    
        while (KeybGetScancode(&scode) == 0) ;
       
        Lcd_Set_Cursor(2, 1);
        printf("%d ", scode);
        while (KeybGetScancode(&scode) == 1)
          printf("%d ", scode);

    }
*/
/*  
    while (1) {
        while (KeybGetScancode(&scode) == 0) ;
        output_num(scode);
    }
*/
    //const unsigned char C64SpaceKey = 0x74;
    const unsigned char C64LeftShiftKey = 0x17;
    
    unsigned char data;
    
    shiftlock_active = 0;
    while (1) {
        KeybGetC64Key();
        
        if (keyb_shift_lock == 1) {
            if (c64key == C64LeftShiftKey)
                c64key = 0xFF;
            if (shiftlock_active == 0) {
                SetC64Key(C64LeftShiftKey, 1);
                shiftlock_active = 1;
            }
        }
        else if (shiftlock_active == 1) {
            SetC64Key(C64LeftShiftKey, 0);
            shiftlock_active = 0;
        }
        
        if (key_shift == 1 && shiftlock_active == 0) {
            if (key_break == 1)
                data = 0;
            else
                data = 1;
            SetC64Key(C64LeftShiftKey, data);
        }
        
        if (c64key != 0xFF) {
            if (key_break == 1)
                data = 0;
            else
                data = 1;
            SetC64Key(c64key, data);
        }
        
        if (restore == 1) {
            //output_num(64);
            LATAbits.LA3 = 0;
            TRISAbits.RA3 = 0;
            __delay_us(20);
            TRISAbits.RA3 = 1;
            LATAbits.LA3 = 1;
            restore = 0;
        }
    }
 
}

void main() {
    
    Initialize();
    
    // reset system
    __delay_ms(1500);
    TRISAbits.RA4 = 1;

    T0CONbits.TMR0ON = 1; // Enable Timer0

//    Lcd_Init();
//    Lcd_Clear();
//    Lcd_Set_Cursor(1, 1);
        
    MainLoop();
    
    return;
}

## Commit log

2019-02-28 Added more documentation and schematics.
2019-02-28 Added SX64 schematics. Added old Eagle files.
    [C64_1 R0.1.brd, C64_1 R0.1.sch, C64_1.brd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]
2019-02-28 Added diagnostic tools & schematics.
2019-03-03 Fixed HD44780 code (for debugging), added test code.
    [main.c]
2019-03-07 Fixed bugs in PS/2 keyboard code. Added debug output to HD44780 display (commented out).
    [main.c]
2019-03-10 Moved PLA files to correct folder. Set NMI pull down time to 100 µs.
    [main.c]
2019-03-22 Moved Rev1 Eagle files to _deprecated
    [C64_1.brd, C64_1.sch, C64_2.brd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]
2019-03-22 Changed Eagle files revision to 1.1
    [C64_1.brd, C64_1.sch, C64_2.brd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]
2019-03-23 Removed pull-ups from CIA2 outputs. Removed overclocking connector. Connected RAM /OE to inverted R/W.
    [C64_1.brd, C64_1.sch, C64_2.brd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]
2019-03-24 changed signal name /BA to BA
    [C64_1.brd, C64_1.sch, C64_2.brd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]
2019-03-25 Changed kernel switches.
    [C64_2.brd, C64_2.sch]
2019-03-30 moved deprecated Eagle files to correct folder.
    [C64_1 R0.1.brd, C64_1 R0.1.sch, C64_1.brd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]
2019-04-13 Fixed rev. number on board.
    [C64_2.brd, C64_3.brd, C64_3.sch]
2019-04-25 Changed video output circuit. Replaced SCART connector with S-Video and cinch. Added FBAS output.
    [C64_1.brd, C64_1.sch, C64_2.brd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]
2019-05-09 Removed ICS525-01, changed modulator: added FBAS output. Replaced SCART connector with S-Video.
    [C64_1.brd, C64_1.sch]
2019-05-09 Changed some resistor values on modulator.
    [C64_1.brd, C64_1.sch]
2020-08-20 Disabled power on timer, improved reset.
    [main.c]
2020-08-20 Fixed VIC-II A6 bug.
    [C64_1.brd, C64_1.sch]
2020-08-21 Fixed color ram write bug.
    [C64_1.brd, C64_1.sch, C64_2.brd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]
2020-08-23 Fixed RESTORE key and other keyboard bugs.
    [main.c]
2020-08-23 Fixed layout.
    [C64_1.brd, C64_2.brd, C64_2.sch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]
2020-08-28 Moved Eagle files to separate folder. Minor layout fixes.
    [C64_1 R0.1.brd, C64_1 R0.1.sch, C64_1.brd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]
2020-08-28 Added action replay schematics. Updated gitignore
2020-08-30 Changed layer of some texts in schematics.
    [C64_1.sch, C64_2.sch]
2021-12-20 Fixed some stuff. Created board Rev. 1.2
    [C64_1.brd, C64_1.sch, C64_2.brd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]
